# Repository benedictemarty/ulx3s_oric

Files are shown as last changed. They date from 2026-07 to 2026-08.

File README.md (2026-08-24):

# ulx3s_oric — Oric Atmos sur FPGA ULX3S

Portage matériel (core FPGA) de l'**Oric Atmos** pour la carte **ULX3S** (Lattice ECP5-85F),
entièrement en Verilog et synthétisable avec la chaîne open-source (yosys / nextpnr-ecp5).

La référence fonctionnelle est l'émulateur logiciel `~/Oric1` (timing ULA, VIA, clavier, AY
vérifiés contre son code source).

## Fonctionnalités (v1)

- CPU **6502** à 1 MHz (core Arlet Ottens)
- **ULA** vidéo réimplémentée : timing PAL 50 Hz (64 µs/ligne, 312 lignes), modes
  TEXT 40×28 et HIRES 240×200, attributs série (ink/paper/charset alternatif/double
  hauteur/clignotement/inversion), palette 8 couleurs
- ROM **BASIC 1.1b** (Atmos), 48 Ko de RAM
- **VIA 6522** complète ($0300) : ports A/B, timers T1/T2, IFR/IER, PCR/ACR
- **AY-3-8912** (core jt49) piloté par CA2/CB2 (BC1/BDIR), audio sur la prise jack
  (DAC 4 bits ULX3S)
- **Clavier USB** sur le port US2 (core usb_hid_host), traduit vers la matrice 8×8 Oric
- Sortie vidéo **HDMI/DVI** (GPDI) 640×480@60, framebuffer 240×224 doublé ×2

## Arborescence

```
rtl/           RTL spécifique au projet (ULA, VIA, clavier, top…)
third_party/   Cores libres vendorés (verilog-6502, jt49, usb_hid_host)
roms/          ROM BASIC 1.1b (+ conversion .hex pour $readmemh)
sim/           Testbenches iverilog
tests/         Scripts de test automatisés
constraints/   Fichier LPF ULX3S v2.0 (85F)
docs/          Documentation projet (architecture, backlog agile)
build/         Produits de synthèse (non versionnés)
```

## ROMs requises (non fournies)

Les ROMs propriétaires ne sont **pas distribuées** dans ce dépôt (copyright). À
placer soi-même dans `roms/` avant de construire :

| Fichier | Contenu | Format |
|---|---|---|
| `roms/basic11b.rom` | BASIC 1.1b (Atmos), 16 Ko | binaire |
| `roms/basic11b.hex` | idem, converti pour `$readmemh` | un octet hexa/ligne |
| `roms/basic10.hex`  | BASIC 1.0 (banque alternative) | idem |
| `roms/microdis.hex` | firmware Microdisc (support `.dsk`) | idem |

Conversion binaire → `.hex` (exemple) :
```sh
xxd -c1 -p roms/basic11b.rom > roms/basic11b.hex
```
`roms/font8x8.hex` (police OSD, maison) est fournie.

## Construire

```sh
make            # synthèse complète -> build/oric_ulx3s.bit
make test       # lance tous les testbenches (iverilog)
make prog       # flash SRAM via openFPGALoader (ou: make prog-fujprog)
```

## Matériel requis

- ULX3S avec ECP5-**85F**
- Écran HDMI (640×480@60 minimum)
- Clavier USB (le port **US2**, connecteur micro-USB du dessus)
- Casque/enceintes sur la prise jack 3,5 mm (son AY)

## Licences

- `third_party/verilog-6502` : licence libre (voir README amont, Arlet Ottens)
- `third_party/jt49` : GPL-3.0 (Jose Tejada)
- `third_party/usb_hid_host` : MIT (nand2mario)
- RTL du projet : GPL-3.0 (contaminé par jt49)
- Les ROMs BASIC (Oric/Tangerine) et le firmware Microdisc restent la propriété
  de leurs ayants droit ; **non distribués ici** — à fournir localement (cf.
  « ROMs requises »).

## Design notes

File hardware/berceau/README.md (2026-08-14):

# Berceau « LOCI-Bridge » — état du projet

Carte berceau : l'ULX3S s'enfiche (JB1/JB2 aux positions exactes relevées sur
`emard/ulx3s ulx3s.kicad_pcb` — nets affectés PAR POSITION, le piège
pairs/impairs est éliminé par construction), la LOCI arrive par nappe IDC 34
(J_LOCI, numérotation Atmos = table JEXP). Schéma électrique =
`../loci_lvc/SPEC_NETLIST.md` (5× SN74LVCC3245A TSSOP-24 + BSS138, brochage
vérifié TI SCAS585R).

## État (2026-08-14)

- `gen_pcb.py` : génération complète reproductible (150×58, plans F.Cu=GND,
  B.Cu=+3V3|+5V split x=116, vias d'alim posés par `post_power.py`).
- `route.py` : freerouting — **tous les signaux routés** (~40 nets).
- `post_power.py` : raccords alim/masse post-routage (vias collision-vérifiés,
  raccords en L, idempotent).

**RESTE À FAIRE avant fabrication** (~30 min de KiCad interactif) :
1. ~15 liaisons d'alimentation : mes contrôles géométriques ignorent les
   îlots de plan isolés — certains vias +3V3/+5V tombent dans des poches de
   zone déconnectées. Ouvrir `berceau.kicad_pcb`, afficher le chevelu,
   tirer les liaisons d'alim restantes à la souris (large, 0,4 mm), DRC.
2. 3 courts-circuits résiduels + sérigraphie (silk_over_copper etc.) à
   corriger au même moment.
3. REVUE MÉCANIQUE avant commande : sens d'enfichage ULX3S (embases mâles
   verticales sous la carte vs femelles coudées d'origine), hauteur des
   composants sous l'ULX3S, position du détrompeur IDC.

Pipeline : `python3 gen_pcb.py && python3 route.py && python3 post_power.py`
puis `kicad-cli pcb drc berceau.kicad_pcb`.

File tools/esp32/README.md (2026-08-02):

# Outillage ESP32 (ULX3S) — compiler & flasher l'ESP32 embarqué

Chaîne complète pour compiler `firmware/esp32_modem` et le flasher sur
l'**ESP32 embarqué** de l'ULX3S, sans matériel externe.

## Méthode (officielle emard)

L'ESP32 se flashe *à travers* le FPGA : on charge un **bitstream passthru**
qui relie le FTDI (US1) à l'UART0 de l'ESP32 et gère EN/GPIO0 pour le
bootloader, puis on téléverse avec esptool (via arduino-cli). On recharge
ensuite le bitstream Oric.

## Installation (une fois)

```sh
make esp32-setup
```
Installe, en local (`tools/esp32/bin`, ignoré par git) :
- **arduino-cli** (installeur officiel Arduino) ;
- le **core Arduino esp32** d'Espressif (inclut esptool) — gros téléchargement ;
- le **passthru 85F officiel** (`emard/ulx3s-bin`) dans `tools/esp32/passthru/`.

> ⚠️ `make esp32-setup` télécharge et exécute l'installeur arduino-cli
> (`curl | sh`) et récupère plusieurs centaines de Mo (toolchain xtensa). À
> lancer toi-même en connaissance de cause. En environnement restreint,
> exécute-le directement : `! make esp32-setup`.

## Compiler / flasher

```sh
make esp32-build              # compile le firmware
make esp32-flash              # passthru -> flash ESP32 -> recharge l'Oric
make esp32-flash PORT=/dev/ttyUSB1   # port différent
```

`esp32-flash` :
1. charge `ulx3s_85f_passthru.bit` en SRAM (`openFPGALoader -b ulx3s`) ;
2. `arduino-cli upload` sur le port série (esptool entre en bootloader) ;
3. recharge `build/oric_ulx3s.bit`.

## Après le flash — config WiFi

Depuis un terminal côté Oric (écriture sur le 6551 `$031C`), en mode commande :
```
AT$SSID=MonReseau
AT$PASS=monMotDePasse
AT$C          -> WIFI OK
ATDT bbs.exemple.com:23
```

## Dépannage

- **PCB v3.1.x** : si le flash échoue avec le passthru, relie **TMS et GND**
  au connecteur JTAG et réessaie (cf. doc ULX3S).
- L'ESP32 ne doit pas piloter **wifi_gpio5** (LED bleue / TMS) en sortie les
  premières secondes — notre sketch n'y touche pas.
- Mappage UART ESP32↔FPGA à confirmer (cf. `firmware/esp32_modem/README.md`).

## Sources
- Passthru & méthode : `emard/ulx3s-passthru`, `emard/ulx3s-bin`
  (`fpga/passthru/passthru-v20-85f/`).
- Core Arduino : `espressif/arduino-esp32`.

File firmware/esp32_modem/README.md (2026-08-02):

# esp32_modem — modem WiFi Hayes pour l'Oric (US-MODEM phase 2)

Firmware pour l'**ESP32 embarqué de l'ULX3S**. Il ponte l'UART venant du
**6551 ACIA** émulé dans le FPGA (`$031C-$031F`, phase 1) vers une connexion
**TCP/telnet en WiFi**, en interprétant les commandes **Hayes AT**. L'Oric
« croit » parler à un modem RS-232.

> **Statut : scaffold.** À compiler et flasher par bmarty. Non compilé ni
> testé dans ce dépôt (pas de toolchain ESP32 ici). Les points marqués ⚠️
> demandent une vérification matérielle.

## Câblage FPGA ↔ ESP32

Côté FPGA (déjà en place, cf. `rtl/top_ulx3s.v` + LPF) :

| FPGA | Sens | ESP32 |
|---|---|---|
| `wifi_rxd` (K3) | FPGA → ESP32 | RX (le 6551 émet) |
| `wifi_txd` (K4) | ESP32 → FPGA | TX (le 6551 reçoit) |
| `wifi_en` | FPGA → ESP32 | EN (maintenu haut) |

⚠️ **À vérifier sur le schéma ULX3S** : le mappage GPIO exact de cet UART côté
ESP32. Le firmware utilise par défaut `Serial` (**UART0**, GPIO1/3), qui est la
liaison standard ESP32↔FPGA de l'ULX3S. Si UART0 entre en conflit avec la
console/programmation, basculer sur un UART secondaire dans le sketch :
```cpp
HardwareSerial Link(2);
// dans setup(): Link.begin(LINK_BAUD, SERIAL_8N1, RX_PIN, TX_PIN);
```
Le débit **doit rester 115200** (identique aux `uart_tx`/`uart_rx` du FPGA).

## Compilation

Arduino IDE (paquet **esp32** d'Espressif) ou `arduino-cli` :
```sh
arduino-cli compile --fqbn esp32:esp32:esp32 firmware/esp32_modem
```
Carte : « ESP32 Dev Module » (l'ESP32 de l'ULX3S est un module WROOM).
Dépendances : `WiFi`, `Preferences` (fournies par le core esp32).

## Flash de l'ESP32 sur l'ULX3S ⚠️

Sur l'ULX3S, l'ESP32 se flashe **via le FPGA** qui fait passerelle FTDI↔ESP32
et pilote EN/GPIO0 pour le bootloader. Procédure de principe (à confirmer avec
la doc ULX3S / le dépôt `ulx3s-examples`) :
1. Charger un **bitstream « passthru »** ULX3S (relie l'FTDI à l'UART0 de
   l'ESP32 et gère EN/IO0), p.ex. depuis les exemples ULX3S.
2. Flasher avec `esptool.py --chip esp32 --port /dev/ttyUSB0 write_flash ...`
   (ou `arduino-cli upload`), l'esptool gère l'entrée en bootloader.
3. Recharger notre bitstream Oric (`make prog`) pour rétablir le modem.

> Tant que ce point n'est pas rôdé, tester le firmware sur un **ESP32 de
> dev externe** relié à K3/K4/GND est le plus simple.

## Configuration WiFi (une fois)

Depuis un terminal côté Oric (ou tout ce qui écrit sur le 6551), en mode
commande :
```
AT$SSID=MonReseau
AT$PASS=monMotDePasse
AT$C            (connexion WiFi ; réponse WIFI OK / WIFI FAIL)
AT$W            (affiche SSID + IP)
```
SSID/mot de passe sont **persistés en NVS** (Preferences).

## Commandes AT gérées

| Commande | Effet |
|---|---|
| `AT` | OK |
| `ATDT host[:port]` / `ATD ...` | connexion TCP (port 23 telnet par défaut) → `CONNECT` |
| `+++` | échappement vers le mode commande (connexion maintenue) |
| `ATO` | retour en ligne |
| `ATH` | raccroche → `NO CARRIER` |
| `ATE0/ATE1` | écho off/on |
| `ATV0/ATV1` | réponses numériques / texte |
| `ATI` | bannière d'identification |
| `ATZ` | reset léger (raccroche) |
| `AT$SSID= / AT$PASS= / AT$C / AT$W` | config/état WiFi (custom) |

Réponses : `OK`, `ERROR`, `CONNECT`, `NO CARRIER`.

## Points ouverts (à traiter en phase 2/3)

- ⚠️ **UART ESP32↔FPGA** : confirmer le GPIO/UART exact (voir plus haut).
- ⚠️ **Procédure de flash ULX3S** de l'ESP32 (passthru + esptool).
- **DCD matériel** : la porteuse est signalée **en bande** (`CONNECT` / `NO
  CARRIER`). Pour un vrai bit **DCD** (`$031D` bit5), router un `wifi_gpio`
  (p.ex. `wifi_gpio5`) depuis l'ESP32 vers l'entrée `acia_dcd` du FPGA (câblée
  à 0 aujourd'hui) — petite retouche RTL à faire quand le firmware pilote la
  porteuse.
- **Contrôle de flux** : pas de RTS/CTS câblé ; le 6551 régule via
  `TDRE`/`RDRF`. Aux débits BBS (≤ 9600 « virtuels ») c'est large ; surveiller
  aux gros transferts.
- **Telnet** : négociations IAC refusées en minimal (`telnetStrip`) ; suffit
  pour la plupart des BBS. PETSCII/ANSI = côté terminal Oric (phase 3).
- **Partage du lien** avec US-NETFS : à terme ce même UART portera aussi le
  contrôle du navigateur de fichiers → prévoir un protocole à canaux
  (cf. `docs/NETFS_WIFI.md`).

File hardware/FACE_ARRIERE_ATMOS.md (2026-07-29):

# Carte « Atmos moderne » — carte mère format Oric Atmos

**CARTE UNIQUE** (décision 2026-07-29) : une seule platine porte tout le
micro — berceau **Tang Nano 20K** (le cœur, portage Gowin prérequis),
**2 berceaux Pico W**, adaptation 5 V, connecteurs d'époque, USB, HP.
L'ULX3S reste hors carte (banc de développement ECP5 uniquement).

```
                    face arrière (connecteurs d'époque)
┌──────────────────────────────────────────────────────────────────────┐
│  [HDMI]   [DIN-7]     [===== 2x10 =====]    [██ peigne 34 ██]   [5V] │
│  vidéo    cassette     port imprimante        extension (LOCI)  jack │
│                                                                      │
│U │   ┌─────────────┐  ┌─────────────┐  ┌──────────────────────┐     │
│S │   │ berceau      │  │ berceau     │  │ berceau              │     │
│B │   │ Pico W  #1   │  │ Pico W #2   │  │ TANG NANO 20K        │     │
│1 │   │ (LOCI fw,    │  │ (modem WiFi,│  │ (le cœur : core Oric │     │
│  │   │  SD ext,USB1)│  │ clavier,USB2│  │  Gowin, HDMI, SDRAM) │     │
│U │   └─────────────┘  └──────┬──────┘  └───────────┬──────────┘     │
│S │                          pont UART multiplexé ───┘                │
│B │      6x TXS0108E, LM393, PhotoMOS, PAM8302+HP, nappe clavier      │
│2 │                                                                   │
└──────────────────────────────────────────────────────────────────────┘
   côté : USB1, USB2 (USB-A femelles)
```

## Connecteurs (de gauche à droite, comme l'Atmos)

| Emplacement Atmos | Ici | Référence |
|---|---|---|
| Prise TV (RF) | — supprimée | |
| DIN RGB | **HDMI femelle** coudée, déport mécanique du GPDI ULX3S par câble HDMI court mâle-mâle (aucune électronique) | prise HDMI-A traversante |
| DIN-7 cassette | **DIN-7 femelle** identique à l'origine (brochage Atmos : TAPE OUT, GND, TAPE IN, SOUND, RELAYS) | DIN 7 broches 270° |
| Port imprimante 20 pts | **Header mâle 2×10** au pas 2,54 comme l'origine (câbles imprimante d'époque compatibles) | |
| Port d'extension 34 pts | **Peigne doré 2×17** au bord de la carte — la LOCI s'y clipse comme sur un vrai Atmos | doigts or, PCB 1,6 mm |
| Jack alim 9 V | **Jack 5,5/2,1 mm, 5 V** : alimente le côté 5 V (cartouche, imprimante, cassette, TXS) | |

## Électronique embarquée (assemblage JLCPCB, zéro soudure)

- 5× **TXS0108E** (TSSOP-20) : 16 adresses + 8 données + 8 contrôles
  extension + 8 données imprimante + strobe/ack/cassette.
- 1× **LM393** + réseau RC : mise en forme du signal TAPE IN
  (magnétophone → niveau logique).
- Condensateurs de découplage, résistances de pull-up 5 V (bus au repos).
- liaisons internes en pistes (plus aucun câblage Dupont : carte unique).

## Affectation GPIO complémentaire (imprimante + cassette)

| GPIO | Signal | Sens FPGA |
|---|---|---|
| gp[23..27], gn[23..25] | Données imprimante PA0..PA7 | sortie |
| gn[26] | /STROBE imprimante (PB4) | sortie |
| gn[27] | /ACK imprimante (CA1) | entrée (pull-up) |
| gp[14] | TAPE OUT (PB7) | sortie |
| gp[15] | MOTEUR cassette (PB6, vers relais/transistor) | sortie |
| gp[16] | TAPE IN (vers CB1, après LM393) | entrée |

## Berceaux (côté 3,3 V — le même bus que le lien ULX3S)

Principe : **un Pico = un firmware** ; les berceaux sont de simples
supports femelles, à peupler selon l'usage. Avec la LOCI réelle branchée
sur le peigne, le berceau #1 (LOCI intégrée) reste VIDE — un seul Pico W
(#2, modem WiFi + scan clavier) suffit. Le #1 se peuple pour une config
autonome sans cartouche.

- **2× berceau Pico W** (2 rangées de supports femelles 1×20, pas 2,54) :
  - Pico #1 : candidat naturel pour porter le **firmware LOCI natif**
    (github.com/sodiumlb/loci-firmware, RP2040) ou tout périphérique de bus
    maison — il voit le bus 6502 en 3,3 V, comme le RP2040 de la vraie LOCI ;
  - Pico #2 : **modem WiFi** (PicoWiFiModemUSB, ACIA à $0380 — déjà supporté
    par l'émulateur de référence) ;
  - straps de sélection pour choisir quelles lignes de bus chaque Pico voit
    (éviter les conflits de pilotage — deux périphériques ne répondent
    jamais à la même adresse).
- **1× berceau Tang Nano 20K** (choix acté 2026-07-29, remplace le couple
  Primer 20K + dock) : format DIP à picots 2,54 → deux rangées de supports
  femelles. GW2AR-18 avec 8 Mo de SDRAM intégrée, HDMI et lecteur SD à
  bord ; FPGA d'expérimentation sur le bus (co-processeur, cartouche
  synthétique…). Même règle : il voit le bus 3,3 V.

⚠️ Règle de cohabitation : le Tang Nano pilote toujours A/RW/Φ2 ; les berceaux
sont des **périphériques** (ils ne pilotent D que sur lecture de leur
plage, /IRQ//ROMDIS//MAP en drain ouvert).

## Stockage et mémoire

- **Slot micro-SD ACCESSIBLE DE L'EXTÉRIEUR** (exigence 2026-07-29) :
  monté au bord arrière de la carte, poussoir push-push, câblé en SPI sur
  le berceau Pico #1 — c'est le stockage LOCI (.tap/.dsk), celui qu'on
  change au quotidien. Accès par l'ancienne découpe TV (RF) du boîtier
  Atmos, inutilisée (prévoir un insert imprimé 3D pour guider la carte
  dans l'ouverture ronde).
- Le micro-SD embarqué du Tang Nano 20K (core, rarement manipulé) reste
  interne ; en cas de besoin, une rallonge micro-SD souple peut le
  déporter.
- **RAM : aucun boîtier sur la carte porteuse.** La RAM de l'Oric (64 Ko)
  est en BRAM dans le FPGA ; le Tang Nano 20K apporte 8 Mo de SDRAM
  intégrés — le bus 6502 n'adresse que 64 Ko.

## USB latéraux

Chaque USB-A latéral est un port **hôte PIO-USB appartenant à un Pico**
(D+/D- sur 2 GPIO + 5 V du jack ; le Tang Nano n'a aucun rôle USB) :
- **USB1 → Pico #1** (firmware LOCI) : clé USB de stockage et
  clavier/souris HID, comme le port USB de la vraie cartouche (hub
  supporté par le firmware) ;
- **USB2 → Pico #2** (modem WiFi + scan matrice) : clavier USB de secours
  quand le berceau #1 est vide (vraie LOCI sur le peigne).
La LOCI réelle branchée sur le peigne conserve son propre port USB.
Les micro-USB natifs des Picos restent accessibles sur les berceaux pour
flasher leurs firmwares (opération d'atelier, ne sort pas du boîtier).

## Portage Gowin (nouveau chantier RTL)

Le core développé sur ULX3S (ECP5) devra être porté sur le GW2AR-18 du
Tang Nano 20K : chaîne yosys `synth_gowin` + nextpnr-himbaechel/apicula
(le Tang Nano 20K est bien supporté par la chaîne libre), ou Gowin EDA.
À adapter : PLL (rPLL Gowin), sérialiseur TMDS (primitives ODDR Gowin),
BRAM (inférence identique), USB clavier (déplacé vers les Pico).
CPU/ULA/VIA/AY : portables tels quels. → épic au backlog.

## Alimentation

- Le jack 5 V alimente exclusivement le domaine 5 V de la carte
  (VCCB des TXS, cartouche broche 33, imprimante, LM393).
- Le jack 5 V alimente aussi le Tang Nano et les Picos (via leurs entrées 5 V). **Masse unique de la carte.**
- Prévoir 5 V / 1 A (la LOCI consomme < 300 mA).

## Format : carte mère Atmos complète

**Boîtier cible acté (2026-07-29) : OriClone-1** — boîtier imprimable 3D
(Thingiverse 6228328, CC-BY-SA, ~284×205×~100 mm assemblé) conçu pour la
carte du projet OriClone-1 de JennyDigital (github.com/JennyDigital/OriClone-1,
cloné en `hardware/oriclone-1-ref/`). Notre carte reprend donc le gabarit
**OriClone-1 : 206,5 × 138,0 mm**, trous de fixation à (3,8;3,8),
(3,8;133), (96,8;133), (202,5;3,8), (202,5;133) mm (+ 2 petits trous à
l'origine), extraits du fichier Eagle `OriClone-1.brd`. Le clavier peut
être la platine **« Oric Tactile KB » du même dépôt** (switches MX,
gerbers prêts à commander, compatible avec ce boîtier et sa touche SHIFT
imprimée). Positions des connecteurs arrière à reprendre du .brd au
moment du routage :
- connecteurs arrière positionnés exactement comme l'origine (découpes du
  boîtier) : le peigne d'extension au bord arrière droit, DIN cassette,
  port imprimante, HDMI à l'emplacement du DIN RGB, jack alim ;
- trous de fixation aux emplacements des plots du boîtier Atmos ;
- **le Tang Nano 20K en berceau est le cœur** : son HDMI est déporté sur le
  connecteur arrière (câble/adaptateur court), son micro-SD sert au core,
  sa SDRAM 8 Mo est intégrée ; le bus 6502 5 V sort de ses GPIO via les
  TXS0108E ;
- **haut-parleur** : emplacement pour HP Ø 40-50 mm (comme l'origine) +
  ampli classe D PAM8302 attaqué en PWM/sigma-delta depuis un GPIO du
  Tang Nano ;
- **budget GPIO Tang Nano 20K** (~40 broches utiles) : bus extension
  (32) + cassette (3) + OE + audio + pont UART Pico #2 (2) ≈ 40 ;
- **architecture satellites (actée 2026-07-29)** : seuls le FPGA et la
  LOCI (réelle ou Pico #1 avec le firmware LOCI, ~26 GPIO consommés par
  le bus) touchent le bus parallèle. Le Pico #2 est un satellite HORS
  bus relié au FPGA par un **pont UART multiplexé** (2 GPIO) qui
  transporte : les octets imprimante (logique VIA dans le FPGA, lignes
  Centronics physiques et handshake ACK sur le Pico — mode « imprimante
  virtuelle » vers SD/WiFi possible), le modem WiFi (ACIA 6551 en RTL
  dans le FPGA, modèle dispo dans la référence Phosphoric), et les
  événements du clavier matrice scanné par le Pico ;
- **pont UART : aucun composant à ajouter** (pistes 3,3 V courtes sur
  PCB ; la liaison PC du Nano 20K passe par son BL616 embarqué, comme le
  FTDI de l'ULX3S). Protocole du pont avec trames typées + CRC8 +
  acquittement (3 flux multiplexés : imprimante, modem ACIA, clavier) —
  la robustesse est logicielle, pas matérielle ;
- **clavier d'origine réutilisable tel quel** : la platine Atmos est une
  matrice 8×8 passive (aucune électronique). Header nappe au même
  emplacement que la carte d'origine (brochage : schéma du manuel de
  service, à transcrire au routage). Scan par le **Pico #2** (16 GPIO,
  injection vers le core par le canal clavier série existant) — le FPGA
  reste déchargé. Pas de diodes dans la matrice d'origine : ghosting
  authentique conservé.

⚠️ Mesures à faire sur boîtier/carte réels avant le routage final :
dimensions exactes, positions des découpes arrière, entraxes de fixation,
position du connecteur nappe clavier.

## Stratégie : CARTE UNIQUE (décision bmarty 2026-07-29)

**Une seule platine porte tout** : berceau Tang Nano 20K, 2 berceaux
Pico W, les 6 TXS, le peigne LOCI, cassette, imprimante, HDMI déporté,
micro-SD externe, HP, clavier. Pas de bandeau intermédiaire commandé.

Le dossier « phase A » (hardware/phaseA/) N'EST PAS perdu : c'est le
prototype virtuel dont la carte unique hérite les blocs VALIDÉS PAR DRC :
banc de 6 TXS et affectations, géométrie exacte du peigne (pas confirmé
sur la LOCI réelle), chaîne analogique cassette (LM393+hystérésis,
PhotoMOS), port imprimante, pinouts fan-out monotone, et toutes les
leçons de routage (paires de doigts, échappements TSSOP, routage
conjoint). Maîtrise du risque sans deuxième commande : DRC 0 erreur
exigé + revue visuelle des rendus + lot de 5 (une itération de réserve).

Le boîtier paramétrique OpenSCAD (backlog S5) est généré depuis les
coordonnées des connecteurs de CETTE carte : gabarit libre (plus
contraint par l'OriClone), silhouette Atmos par le profil extrait.

## Notes de conception vérifiées

- **TXS0108E TSSOP-20 (PW), brochage vérifié sur datasheet TI SCES642H** :
  1=A1, 2=VCCA(3,3 V), 3..9=A2..A8, 10=OE, 11=GND, 12..18=B8..B2,
  **19=VCCB(5 V), 20=B1**. OE : pull-down 10 kΩ vers GND (Hi-Z au
  démarrage, exigence datasheet) + strap vers 3,3 V pour activer.
- Moteur cassette : contact sec attendu par le magnétophone → relais
  statique PhotoMOS (AQY212 ou TLP222A) piloté par MOTOR_3V3, pas un
  transistor à la masse.
- TAPE IN : comparateur LM393 (seuil ~200 mV) avec pull-up 3,3 V en sortie.
- TAPE OUT : diviseur résistif vers niveau ligne (~10 k/1 k).

## Fabrication

- PCB 2 couches ~150×40 mm, doigts or biseautés (option « gold fingers +
  bevel » chez JLCPCB), épaisseur 1,6 mm.
- Assemblage face top (économique) : TXS0108E, LM393, passifs.
- Connecteurs traversants (HDMI, DIN-7, headers, jack) en assemblage
  standard JLCPCB.
- Fichiers à produire : KiCad (schéma + PCB), gerbers, BOM.csv, CPL.csv.

## État

- [x] Spécification (ce document)
- [x] RTL : signaux imprimante + cassette exposés (cf. CHANGELOG)
- [ ] Schéma KiCad (en attente installation KiCad : `sudo apt install kicad`)
- [ ] PCB + DRC + gerbers + BOM/CPL JLCPCB
- [ ] Vérification du pas exact du connecteur LOCI avant envoi en fab
      (mesure sur la cartouche réelle : pas attendu 2,54 mm, à confirmer !)

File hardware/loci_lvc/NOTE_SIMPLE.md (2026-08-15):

# Version SIMPLIFIÉE — `loci_lvc_simple` (façon vraie LOCI)

**Date :** 2026-08-15 · **Auteur :** bmarty

## L'idée
La carte à **5 transceivers** (`loci_lvc` / `SPEC_NETLIST.md`) est dense et dure à
router. Or la **vraie LOCI n'a qu'UN transceiver octal** (74LVC4245A) + de petits
buffers, parce que sa logique est dans le RP2040.

On applique le même principe : **les entrées des périphériques Oric sont
5 V-tolérantes** (seuil TTL ≈ 2 V), donc les **sorties du FPGA** (A0–A15, Φ2, R/W,
/IO) pilotent le peigne **en direct en 3,3 V — sans aucun transceiver**. Il ne
reste à adapter que :
- le **bus de données** (bidirectionnel) → **1× 74LVC4245A** (`U1`) ;
- les **entrées de contrôle** (/IRQ, /ROMDIS, /MAP, /IOCTL, venant du périphérique
  en 5 V) → **1× 74LVC245** (`U2`, alim 3,3 V, 5 V-tolérant) ;
- **/RESET** (drain ouvert) → **1× BSS138** (`Q1`).

## Résultat
- **15 composants** au lieu de 25.
- **Route en 2 couches** : freerouting ferme **tous les signaux, 0 violation**
  (là où la version 5-transceivers plafonnait à 12–17 signaux !).
- Reste **9 masses à coudre** + 3 vias GND de freerouting à écarter — **finition
  triviale**.

## Reproduire
```sh
python3 gen_pcb_simple.py loci_lvc_simple.kicad_pcb   # placement + zones
python3 route_simple.py                               # freerouting 2 couches
# -> tous signaux routes, 0 violation, 9 masses restantes
```

## Finir (couture des 9 masses)
Le plus simple : **passer en 4 couches** (plan GND interne) → la couture devient un
via par pad GND (cf. `convert_6layer.py` adapté, ou dans KiCad). Ou, en 2 couches,
poser à la main un **via GND** près de chaque pad GND non connecté (9 vias, ~5 min
dans KiCad). Puis DRC → 0/0 → Gerbers → JLCPCB.

## BOM (simplifiée)
| Réf | Composant | Boîtier |
|---|---|---|
| U1 | SN74LVCC3245APW (data) | TSSOP-24 |
| U2 | SN74LVC245APW (entrées ctrl) | TSSOP-20 |
| Q1 | BSS138 (/RESET) | SOT-23 |
| R1–R4 | 10 kΩ | 0603 |
| C1–C5 | 100 nF / 10 µF | 0603 / 0805 |
| J_ULX | 2×20 (vers ULX3S) | THT |
| J_EXP | peigne 34 doigts | bord de carte |
| J_PWR | jack +5 V | THT |

> **Mapping GPIO ULX3S** : inchangé (`top_ulx3s.v` / `mapping-gpio-contraintes.md`).
> Les nets `A5V*`, `RW5`, `PHI2_5`, `IO5_n` disparaissent (adresses/Φ2/R-W//IO
> pilotées en direct) ; seuls `D5V*`, `*5_n`, `RST5_n` restent (via composants).

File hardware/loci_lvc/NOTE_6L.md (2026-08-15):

# Variante 6 couches — routage du bus complet (WIP)

**Date :** 2026-08-15 · **Auteur :** bmarty

## Pourquoi 6 couches
La carte 2 couches (routage `route.py` d'origine) **plafonne à ~12–17 signaux
non routés** : le faisceau côté 5 V (puces → peigne) est trop dense pour 2 (voire
4) couches. **Le passage en 6 couches (4 couches de signal + 2 plans GND internes)
débloque le routage** : freerouting ferme alors tout sauf ~11 liaisons.

## État de `loci_lvc_6l2.kicad_pcb`
- **6 couches** : F.Cu / **In1.Cu (plan GND)** / In2.Cu (signal) / In3.Cu (signal) /
  **In4.Cu (plan GND)** / B.Cu. Plans GND aussi sur F/B.
- **Routé à ~90 % par freerouting, PROPRE : 0 violation DRC.**
- **Reste 25 liaisons non connectées** :
  - **11 signaux** dont les pads côté puce sont **recouverts par le faisceau**
    (freerouting ne les ferme pas — limite de placement, pas de couches) ;
  - **14 masses** à coudre (vias pad → plans In1/In4).

## Reproduire le board propre
```sh
python3 gen_pcb.py loci_lvc_6l2.kicad_pcb      # board vierge (placement)
python3 convert_6layer.py loci_lvc_6l2.kicad_pcb  # 6 couches + plans GND In1/In4
python3 route_6l2.py                            # freerouting (mp 100) + import
# -> ~25 non connectees, 0 violation
```

## Finition (à faire dans KiCad, à la main)
Les 25 dernières liaisons se finissent **dans l'éditeur KiCad** :
- router les **11 signaux** sur In2/In3 (couches internes libres) ;
- **coudre les 14 masses** (poser un via GND près de chaque pad GND non connecté ;
  les plans In1/In4 sont continus → tout via GND legal connecte).

## ⚠️ Scripts de complétion automatique — NON fiables
`route_signals.py`, `fix_gnd2.py`, `finish_islands.py`, `route_pair.py`,
`fix_power.py`, `cleanup_vias.py`, `find_island2.py` : tentatives de complétion
**automatique** des 25 liaisons. **Elles connectent mais introduisent des
courts-circuits / violations DRC** (détection de collision insuffisante). À
utiliser seulement comme base ; **préférer la finition manuelle KiCad** pour un
board réellement fabricable.

## Règles / fabrication
- Réglé fabricable JLCPCB 6 couches (trace 0,15 / via 0,3-0,6 possible).
- Une fois les 25 liaisons finies et DRC propre : générer Gerbers + drill + BOM
  (BOM = `SPEC_NETLIST.md`) + placement, puis commander en PCBA.

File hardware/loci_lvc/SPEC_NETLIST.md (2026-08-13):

# Carte adaptateur LOCI (rév. LVC) — spécification électrique

Petite carte 2 couches (~110×50 mm) entre les nappes GPIO de l'ULX3S et le
connecteur carte-bord 34 points de la **LOCI**. Révision 2026-08-13 : les
TXS0108E du bandeau phaseA sont **proscrits** (auto-sens inadapté à un bus
parallèle push-pull, cf. `docs/PORT_EXTENSION.md`) → **5× SN74LVCC3245APW**
(dual-supply 3,3 V/5 V, DIR + /OE maîtrisés).

Hérite de phaseA : géométrie du peigne J_EXP (34 doigts, 2×17, pas 2,54 mm,
doigts 1,6×6 mm sans masque, F.Cu+B.Cu, biseau 45°, ENIG), numérotation
officielle Atmos (position k : avant = 2k, arrière = 2k−1).

## Différences avec phaseA

- Périmètre réduit : NI imprimante, NI cassette/DIN, NI LM393/PhotoMOS —
  uniquement le bus d'extension vers la LOCI.
- 5× 74LVCC3245A à direction figée ou pilotée, plus de TXS.
- /RESET par BSS138 (drain ouvert bidirectionnel), plus par transceiver.
- Deux nets de pilotage venant du FPGA : `XCVR_DIR` (gp[16]) et
  `/XCVR_OE` (gn[16]) — déjà câblés dans le bitstream (commit RTL
  2026-08-13).

## Affectation des transceivers

DIR haut = A→B (A = côté 3,3 V FPGA, B = côté 5 V LOCI).

| Chip | Canaux | DIR | /OE |
|---|---|---|---|
| U1 | A1..A8 = A0..A7 → A5V0..A5V7 | figé HAUT (A→B) | GND |
| U2 | A1..A8 = A8..A15 → A5V8..A5V15 | figé HAUT (A→B) | GND |
| U3 | A1..A8 = D0..D7 ↔ D5V0..D5V7 | **XCVR_DIR** (pull-down 10 k) | **/XCVR_OE** (pull-up 10 k → isolé par défaut) |
| U4 | A1..A3 = RW, PHI2, IO_n → RW5, PHI2_5, IO5_n (A4..A8 NC, entrées A à GND) | figé HAUT (A→B) | GND |
| U5 | B1..B4 = IRQ5_n, ROMDIS5_n, MAP5_n, IOCTL5_n → IRQ_n, ROMDIS_n, MAP_n, IOCTL_n (B5..B8 = entrées, liées à GND en direct) | figé BAS (B→A) | GND |

Sécurité par défaut (FPGA absent/non configuré) : U3 isolé (/OE tiré haut)
et en écoute (DIR tiré bas) ; les entrées de canaux inutilisés ne flottent
jamais (liées à la masse du côté émetteur).

## SN74LVCC3245A — brochage VÉRIFIÉ (TI SCAS585R, mai 2026)

⚠️ Boîtier PW = **TSSOP-24** (7,8×6,4 mm, pas 0,65 mm) — PAS 20 broches.
1=VCCA, 2=DIR, 3..10=A1..A8, 11/12/13=GND, 14..21=B8..B1 (ordre inversé),
22=/OE (actif bas), 23=NC, 24=VCCB.
- VCCA 2,3-3,6 V (côté FPGA), VCCB 3-5,5 V (côté LOCI).
- **DIR et /OE référencés à VCCA** → pilotage direct 3,3 V par le FPGA.
- DIR haut = A→B ; VCC isolation : si un des deux VCC < 100 mV, tout passe
  en haute impédance (sécurité au débranchement).
- Empreinte KiCad : `Package_SO:TSSOP-24_4.4x7.8mm_P0.65mm`.

## /RESET (bidirectionnel drain ouvert)

BSS138 : gate = +3V3 ; source = RST_n (côté FPGA) + R 10 k → 3V3 ;
drain = RST5_n (côté LOCI, doigt 4) + R 10 k → +5V. Schéma classique
« niveau I²C » : chaque côté peut tirer bas, aucun ne pousse du 5 V vers
le FPGA.

## J_ULX (2×20) — vers l'ULX3S (nappe/Dupont, 3,3 V)

Ordre fan-out monotone (hérité phaseA, + les 2 nets XCVR) :
1=RW, 2=PHI2, 3=IO_n, 4=RST_n, 5=IRQ_n, 6=ROMDIS_n, 7=MAP_n, 8=IOCTL_n,
9=XCVR_DIR, 10=XCVR_OE_n ; 11..18 = D0..D7 ; 19..26 = A0..A7 ;
27..34 = A8..A15 ; 35,36=GND ; 37,38=+3V3 (depuis l'ULX3S) ; 39,40=GND.

Correspondance côté ULX3S = table de `docs/PORT_EXTENSION.md`
(gp/gn J1-J2, dont XCVR_DIR=gp[16], /XCVR_OE=gn[16]).

## Alimentations

- +3V3 : depuis l'ULX3S (J_ULX 37,38) — alimente VCCA des 5 chips + pull-ups côté A.
- +5V : **jack 5,5/2,1 externe** (J_PWR) — alimente VCCB des 5 chips,
  pull-up RST5_n, et le doigt 33 (+5V LOCI). JAMAIS relié au 3V3/FPGA.
- Masse commune : J_ULX (35,36,39,40) + jack + doigt 34.
- Découplage : 100 nF ×2 par chip (un par VCC), 10 µF vrac sur +5V et +3V3.

## BOM (draft)

| Réf | Composant | Empreinte |
|---|---|---|
| U1..U5 | SN74LVCC3245APW | TSSOP-24_4.4x7.8mm_P0.65mm |
| Q1 | BSS138 | SOT-23 |
| J_EXP | Peigne 34 doigts (script phaseA) | custom |
| J_ULX | Header mâle 2×20 | PinHeader_2x20_P2.54mm_Vertical |
| J_PWR | Jack alim 5,5/2,1 | BarrelJack_Horizontal |
| R1,R2 | 10 k (pull-ups /RESET 3V3 et 5V) | R_0603 |
| R3 | 10 k (pull-up /XCVR_OE → 3V3) | R_0603 |
| R4 | 10 k (pull-down XCVR_DIR) | R_0603 |
| C1..C10 | 100 nF | C_0603 |
| C11,C12 | 10 µF | C_0805 |

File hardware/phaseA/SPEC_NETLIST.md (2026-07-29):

# Phase A — Bandeau LOCI : spécification électrique complète

Carte 2 couches ~160×50 mm. Peigne doré 34 contacts (2×17, pas 2,54 mm,
doigts des deux faces) au bord DROIT. Assemblage JLCPCB (SMD top).
Épaisseur 1,6 mm, finition ENIG + biseau 45° sur le peigne.

## Composants

| Réf | Composant | Empreinte KiCad |
|-----|---|---|
| J_EXP | Peigne 34 doigts (custom, voir géométrie) | générée par script |
| U1..U6 | TXS0108E (TSSOP-20) | Package_SO:TSSOP-20_4.4x6.5mm_P0.65mm |
| U7 | LM393 (SOIC-8) | Package_SO:SOIC-8_3.9x4.9mm_P1.27mm |
| K1 | PhotoMOS AQY212GH (DIP-4 CMS) | Package_DIP:DIP-4_W7.62mm (ou SOP-4) |
| J_ULX_A | Header mâle 2×20 | Connector_PinHeader_2.54mm:PinHeader_2x20_P2.54mm_Vertical |
| J_ULX_B | Header mâle 2×10 | Connector_PinHeader_2.54mm:PinHeader_2x10_P2.54mm_Vertical |
| J_PRN | Header mâle 2×10 (Centronics Atmos) | idem 2x10 |
| J_CAS | DIN-7 femelle 270° THT | Connector_DIN:DIN41524_7pin_... (ou pads THT custom) |
| J_PWR | Jack alim 5,5/2,1 | Connector_BarrelJack:BarrelJack_Horizontal |
| J_SND | Header 1×2 (audio vers DIN4) | PinHeader_1x02 |
| R_OE | 10 kΩ 0603 (pull-down OE) | R_0603 |
| R1 | 10 kΩ 0603 (div. TAPE OUT série) | R_0603 |
| R2 | 1 kΩ 0603 (div. TAPE OUT masse) | R_0603 |
| R3,R4 | 100 kΩ 0603 (polarisation IN+ LM393) | R_0603 |
| R5 | 100 kΩ 0603 (seuil auto IN-) | R_0603 |
| R6 | 10 kΩ 0603 (pull-up sortie LM393) | R_0603 |
| R7 | 470 Ω 0603 (LED PhotoMOS) | R_0603 |
| R8 | 1 MΩ 0603 (hystérésis LM393) | R_0603 |
| C1 | 1 µF 0603 (couplage TAPE IN) | C_0603 |
| C2 | 100 nF 0603 (moyenne IN-) | C_0603 |
| C3..C14 | 100 nF 0603 (découplage : 2/TXS) | C_0603 |
| C15,C16 | 10 µF 0805 (vrac 5V, 3V3) | C_0805 |

## TXS0108E — brochage VÉRIFIÉ (TI SCES642H)

1=A1, 2=VCCA(3V3), 3=A2, 4=A3, 5=A4, 6=A5, 7=A6, 8=A7, 9=A8, 10=OE,
11=GND, 12=B8, 13=B7, 14=B6, 15=B5, 16=B4, 17=B3, 18=B2, **19=VCCB(5V)**,
**20=B1**. Tous les OE sur le net OE_EN (R_OE 10 k vers GND ; piloté haut
par le FPGA via J_ULX_A.33 après verrouillage des PLL).

## J_EXP — peigne (numérotation officielle Atmos, annexe 11)

Face AVANT (F.Cu) = broches paires, face ARRIÈRE (B.Cu) = impaires,
même position le long du bord. Position k (1..17) : avant = 2k, arrière = 2k-1.

| Doigt | Net 5V | | Doigt | Net 5V |
|---|---|---|---|---|
| 1 | MAP5_n | 2 | ROMDIS5_n |
| 3 | PHI2_5 | 4 | RST5_n |
| 5 | IO5_n | 6 | IOCTL5_n |
| 7 | RW5 | 8 | IRQ5_n |
| 9 | D5V2 | 10 | D5V0 |
| 11 | A5V3 | 12 | D5V1 |
| 13 | A5V0 | 14 | D5V6 |
| 15 | A5V1 | 16 | D5V3 |
| 17 | A5V2 | 18 | D5V4 |
| 19 | D5V5 | 20 | A5V4 |
| 21 | A5V5 | 22 | D5V7 |
| 23 | A5V6 | 24 | A5V15 |
| 25 | A5V7 | 26 | A5V14 |
| 27 | A5V8 | 28 | A5V13 |
| 29 | A5V9 | 30 | A5V12 |
| 31 | A5V10 | 32 | A5V11 |
| 33 | +5V | 34 | GND |

Géométrie doigts : largeur 1,6 mm, longueur 6 mm depuis le bord, pas
2,54 mm, sans masque (mask ouvert), F.Cu ET B.Cu.
✔ Pas confirmé (2026-07-29, bmarty) : le connecteur LOCI est un
Amphenol 34 points carte-bord standard (type nappe disquette), pas
2,54 mm, carte 1,6 mm. Option de raccordement souple : nappe 34
conducteurs avec connecteurs carte-bord IDC de récupération (câble
disquette d'époque), si l'insertion directe est mécaniquement gênante.

## Affectation TXS

| Chip | Côté A (3V3) ← J_ULX_A | Côté B (5V) → destination |
|---|---|---|
| U1 A1..A8 | A0..A7 | A5V0..A5V7 → J_EXP |
| U2 A1..A8 | A8..A15 | A5V8..A5V15 → J_EXP |
| U3 A1..A8 | D0..D7 | D5V0..D5V7 → J_EXP |
| U4 A1..A8 | RW, PHI2, IO_n, RST_n, IRQ_n, ROMDIS_n, MAP_n, IOCTL_n | RW5, PHI2_5, IO5_n, RST5_n, IRQ5_n, ROMDIS5_n, MAP5_n, IOCTL5_n → J_EXP |
| U5 A1..A8 | PA0..PA7 | PRN_D0..PRN_D7 → J_PRN |
| U6 A1,A2 | STROBE_n, ACK | PRN_STB_n, PRN_ACK → J_PRN (A3..A8/B3..B8 : NC) |

## J_ULX_A (2×20) — vers le FPGA hôte (Dupont, 3,3 V)

**Hôte cible : Tang Nano 20K** (décision 2026-07-29) — l'ULX3S peut aussi
servir de banc de validation ECP5. Budget Nano 20K : J_ULX_A complet passe ;
J_ULX_B (imprimante/cassette) attendra le pont Pico (voir spec carte B).

**Ordre RÉVISÉ 2026-07-29 (fan-out monotone vers les TXS, routage sans
croisements)** :
1=RW, 2=PHI2, 3=IO_n, 4=RST_n, 5=IRQ_n, 6=ROMDIS_n, 7=MAP_n, 8=IOCTL_n,
9=OE_EN ; 10..17 = D0..D7 ; 18..25 = A0..A7 ; 26..33 = A8..A15 ;
34..36=GND ; 37,38=+3V3 (depuis ULX3S) ; 39,40=GND.
(Le câblage Dupont vers les gp/gn de l'ULX3S suit ce tableau, pas
l'ancien : chaque fil est indépendant, seule la table change.)

## J_ULX_B (2×10)

1..8 = PA0..PA7 ; 9=STROBE_n ; 10=ACK ; 11=TAPE_OUT_3V3 ; 12=MOTOR_3V3 ;
13=TAPE_IN_3V3 ; 14,15,16=GND ; 17,18=+3V3 ; 19,20=GND.

## J_PRN (2×10, brochage imprimante Atmos officiel)

Impairs : 1=PRN_STB_n, 3=PRN_D0, 5=PRN_D1, 7=PRN_D2, 9=PRN_D3, 11=PRN_D4,
13=PRN_D5, 15=PRN_D6, 17=PRN_D7, 19=PRN_ACK. Pairs 2..20 : GND.

## J_CAS (DIN-7, brochage Atmos)

1=TAPE_OUT_DIN (depuis diviseur R1/R2), 2=GND, 3=TAPE_IN_DIN (vers C1),
4=SOUND (depuis J_SND.1), 5=NC, 6=MOTOR_A, 7=MOTOR_B (contacts K1).

## Circuits analogiques

- TAPE OUT : TAPE_OUT_3V3 —R1(10k)— TAPE_OUT_DIN —R2(1k)— GND.
- TAPE IN : TAPE_IN_DIN —C1(1µF)— nœud IN+ ; R3(100k) IN+→3V3 ;
  R4(100k) IN+→GND ; R5(100k) IN+→IN- ; C2(100n) IN-→GND ;
  LM393 : IN+=broche 3, IN-=broche 2, OUT=broche 1 ; R6(10k) OUT→3V3 ;
  **R8(1M) OUT→IN+ : hystérésis ~30 mV** (immunité au bruit du câble
  magnétophone — ajouté 2026-07-29) ; OUT = net TAPE_IN_3V3.
  VCC LM393(8)=3V3, GND(4)=GND. 2e comparateur : entrées (5,6) à GND,
  sortie (7) NC.
- MOTEUR : MOTOR_3V3 —R7(470)— K1 LED+(1) ; K1 LED-(2)=GND ;
  K1 contacts (3,4) = MOTOR_A/MOTOR_B (contact sec).

## Alimentations

+5V : J_PWR centre → VCCB U1..U6 (19), J_EXP.33. GND : commun.
+3V3 : J_ULX_A.37/38 → VCCA U1..U6 (2), R3, R6, LM393.8.
Découplage 100 nF au plus près de chaque broche VCCA et VCCB.

## Placement (indicatif)

- Bord droit : J_EXP (doigts, centrés).
- Bord haut (« face arrière ») de gauche à droite : J_PWR, J_CAS, J_PRN.
- Bande centrale : U1..U6 alignés, côté B vers la droite/haut.
- Bord bas : J_ULX_A puis J_ULX_B (accès Dupont), U7/K1 près de J_CAS.

## Critères d'acceptation des fichiers de fabrication

1. `kicad-cli pcb drc` : 0 erreur (avertissements sérigraphie tolérés).
2. 0 net non routé (ratsnest vide).
3. Gerbers + perçage Excellon exportés (`kicad-cli pcb export gerbers/drill`).
4. BOM.csv (réf LCSC quand dispo : TXS0108EPWR=C17197?, à vérifier) et
   CPL.csv (positions top) au format JLCPCB.
5. README de commande : 2 couches, 1,6 mm, ENIG, gold fingers + bevel.

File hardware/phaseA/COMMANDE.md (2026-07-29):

# COMMANDE JLCPCB — Phase A « Bandeau LOCI »

Fichiers à téléverser : archive zip du dossier `gerbers/`
(gerbers toutes couches + Edge.Cuts + perçage Excellon).

## Options PCB (obligatoires)

| Option | Valeur |
|---|---|
| Base Material | FR-4 |
| Layers | **2** |
| Dimensions | 160 × 50 mm |
| PCB Thickness | **1,6 mm** |
| Surface Finish | **ENIG** (obligatoire pour le peigne) |
| Gold Fingers | **Yes** |
| Bevel/Chamfer (gold fingers) | **45°** |
| Outer Copper Weight | 1 oz |
| Solder Mask / Silkscreen | au choix (vert/blanc par défaut) |
| Remove Order Number | conseillé : « Specify a location » impossible ici → « Yes » (payant) ou accepter le marquage |

Remarques :
- Le peigne (34 doigts, 2×17, pas 2,54 mm, doigts 1,6 × 6 mm sur F.Cu et
  B.Cu, masque ouvert) est au bord DROIT du contour. L'option « Gold
  Fingers + 45° bevel » s'applique à ce bord.
- ⚠️ Avant de payer : confirmer le pas de 2,54 mm et le sens de
  numérotation par mesure sur la LOCI réelle (voir QUESTIONS.md §1/§10).

## Options assemblage (SMT top uniquement)

| Option | Valeur |
|---|---|
| PCBA Type | Economic (si dispo) |
| Assembly Side | **Top** |
| BOM | `BOM.csv` |
| CPL (Pick & Place) | `CPL.csv` |

Composants assemblés (32 CMS top) : U1..U6 (TXS0108EPWR, C17206),
U7 (LM393DR, C67470), R_OE,R1..R8 (0603), C1..C14 (0603), C15,C16 (0805).

NON assemblés (à souder soi-même, lignes LCSC=TBD dans la BOM) :
- K1 AQY212GH (DIP-4 traversant — cf. QUESTIONS.md §3 ; variante CMS
  possible : AQY212GHAX = C719739 avec empreinte SOP/SMDIP),
- J_ULX_A (2×20), J_ULX_B (2×10), J_PRN (2×10), J_SND (1×2) : headers
  mâles 2,54 mm THT,
- J_PWR : jack alim 5,5/2,1 THT (type CUI PJ-102A ou équivalent),
- J_CAS : DIN-7 femelle 270° THT (valider l'empreinte mécanique du
  connecteur acheté avant commande, QUESTIONS.md §4).

## Vérifications au moment de la commande

1. Aperçu JLC : orientation des TSSOP/SOIC dans le rendu de placement
   (rotations CPL = angles KiCad ; corriger dans l'outil JLC si besoin).
2. Statut/stock des codes LCSC (vérifiés 07/2026) : C17206, C67470,
   C25804, C21190, C25803, C23179, C14663, C15849, C15850.
3. DRC de production JLC (min track/space 0,127 mm) : la carte est en
   0,25/0,2 mm — large marge.

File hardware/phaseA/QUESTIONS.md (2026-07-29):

# QUESTIONS / points à vérifier avant commande (Phase A)

Incohérences ou ambiguïtés relevées dans SPEC_NETLIST.md, avec
l'interprétation retenue (la plus sûre). AUCUNE modification de netlist
n'a été faite : chaque net/broche/valeur vient de la spec.

## 1. J_EXP — sens de numérotation le long du bord
La spec définit « position k (1..17) : avant = 2k, arrière = 2k-1 » mais
ne dit pas si k=1 est en HAUT ou en BAS du bord droit.
**Retenu : k=1 en haut (y minimal), k=17 en bas.** Si la LOCI réelle est
numérotée dans l'autre sens, il faut miroiter le peigne (1 ligne à changer
dans gen_pcb.py : `y0` / signe du pas). ⚠️ Sens à CONFIRMER face au
connecteur Amphenol de la LOCI (le pas 2,54 mm et l'épaisseur 1,6 mm ont
été confirmés par bmarty le 2026-07-29 — note dans la spec révisée).

## 2. J_EXP — retrait de 0,05 mm par rapport au bord
Les doigts font 6,00 mm de long mais s'arrêtent à 0,05 mm du bord
théorique (demi-épaisseur du trait Edge.Cuts) pour satisfaire le DRC.
Sans effet pratique : le biseau 45° de JLCPCB entame de toute façon le
bord sur ~0,5 mm.

## 3. K1 — « AQY212GH (DIP-4 CMS) » : contradiction THT/CMS
AQY212GH est un boîtier DIP-4 traversant ; les variantes CMS sont
AQY212GHA (pattes coupées) / AQY212GHAX (gull-wing, LCSC C719739).
La spec demande « DIP-4 CMS » avec l'empreinte
`Package_DIP:DIP-4_W7.62mm (ou SOP-4)`.
**Retenu : DIP-4_W7.62mm traversant (1er choix explicite de la spec).**
Conséquence : K1 n'est PAS assemblable par JLC en « assemblage top SMD »
(à souder à la main, ou passer sur AQY212GHAX + empreinte SMD).

## 4. J_CAS — empreinte DIN-7 femelle 270° créée par script
Aucune empreinte DIN 41524 7 broches dans les bibliothèques KiCad.
Créée par script : 7 pastilles THT Ø2,4 mm / perçage 1,3 mm sur un arc de
270°, cercle de broches Ø7,0 mm (DIN 45329), 45° entre broches, ordre
physique 6-1-4-2-5-3-7
(broche 2 au centre de l'arc), ouverture vers le bord haut de la carte.
**À VALIDER mécaniquement contre le connecteur réellement acheté**
(position des pattes de fixation, sens avant/arrière du brochage vu côté
soudure, diamètre des broches). Aucun trou de fixation ajouté faute de
référence constructeur dans la spec.

## 5. J_SND — broche 2 non spécifiée
La spec ne définit que J_SND.1 = SOUND (vers DIN4). **Retenu :
J_SND.2 = GND** (retour audio), interprétation la plus sûre.

## 6. J_PWR — 3e contact du jack (coupure) non spécifié
L'empreinte BarrelJack_Horizontal a 3 pastilles (1=centre, 2=manchon,
3=contact de coupure). La spec ne mentionne que centre=+5V et GND.
**Retenu : pastille 3 laissée non connectée** (le manchon reste GND en
permanence). Vérifier la mécanique du jack acheté (5,5/2,1) vs empreinte
générique KiCad.

## 7. LM393 — comparateur 2 : « entrées (5,6) à GND »
Appliqué tel quel (5 et 6 à GND, 7 NC). Remarque (non corrigée, netlist
respectée) : avec IN+=IN-=0 V la sortie du comparateur inutilisé est
indéterminée ; sans conséquence car la broche 7 est NC. Aucun découplage
100 nF dédié au LM393 dans la spec (C3..C14 réservés aux TXS) ; C16
(10 µF, 3V3) est placé à proximité relative.

## 8. Références LCSC
Vérifiées en ligne (07/2026) :
- TXS0108EPWR (TSSOP-20) = **C17206** (le « C17197? » de la spec ne
  correspond pas : C17206 confirmé sur jlcpcb.com/lcsc.com).
- LM393DR (TI, SOIC-8) = **C67470**.
- AQY212GHAX (CMS) = C719739 ; AQY212GHA = C135778 ; le AQY212GH DIP
  exact n'a pas de code C confirmé → **TBD** dans la BOM.
- Passifs : voir BOM (C25804, C21190, C25803, C23179, C14663, C15849,
  C15850) — codes « basic parts » usuels, à re-vérifier au moment de la
  commande (stock/statut basic évolutif).
- Connecteurs THT (headers, jack, DIN) : non assemblés par JLC → TBD.

## 9. CPL / rotations JLCPCB
Les rotations du CPL sont les angles KiCad. JLCPCB ré-oriente parfois les
TSSOP/SOIC de ±90°/180° : vérifier l'aperçu de placement (rendu 3D) sur
le site JLC avant de valider la commande d'assemblage.

## 10. Révisions de spec intégrées en cours de génération (2026-07-29)
- **R8 1 MΩ (hystérésis LM393, OUT→IN+)** : intégré. R8 avait été ajouté
  directement dans phaseA.kicad_pcb à (55,5;13,2), en court-circuit sur
  U7 pad 8 (+3V3) : replacé en (59;21) par gen_pcb.py.
- **J_ULX_A ordre révisé** (1..8=contrôle, 9=OE_EN, 10..17=D0..D7,
  18..33=A0..A15) : intégré dans gen_pcb.py, carte re-routée.
- **Pas du peigne confirmé** (Amphenol 34 pts, 2,54 mm) : la question ne
  reste ouverte que pour le SENS de numérotation (§1).

## 11. Largeur des pistes d'alimentation : 0,4 mm (au lieu de 0,5)
Le guide de routage indiquait 0,5 mm pour +5V/+3V3. Une piste de 0,5 mm
ne peut pas entrer dans un pad TSSOP-20 au pas 0,65 mm en respectant
l'isolation de 0,2 mm (0,65-0,25-0,2 = 0,20 mm : limite exacte, refusée
par le routeur). Les pistes d'alim sont donc routées à **0,4 mm**
(chutes de tension négligeables : TXS0108E ≈ quelques mA par rail).
La netclass « Power » du board reste déclarée à 0,5 mm.

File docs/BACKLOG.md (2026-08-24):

# Backlog agile — ulx3s_oric

> **Validation carte en attente** : procédure de test matériel des
> fonctionnalités « sim OK » (US2.3 LEDs, US3.3 joystick, US-CSAVE.2/4) dans
> [VALIDATION_CARTE.md](VALIDATION_CARTE.md).

## Sprint 1 (TERMINÉ 2026-07-29) — « Il boote »
Objectif : Oric Atmos fonctionnel sur ULX3S 85F — BASIC 1.1b au boot,
affichage HDMI, clavier USB, son AY.

- [x] US1.1 Squelette projet + docs + git
- [x] US1.2 RTL cœur : ULA, VIA 6522, mémoire, intégration 6502/jt49
- [x] US1.3 HDMI 640×480 + top-level ULX3S + USB HID + audio
- [x] US1.4 Testbenches : VIA, ULA, boot ROM (message BASIC en RAM écran)
- [x] US1.5 Synthèse 85F propre en timing + bitstream + flash carte

### Validation matérielle
- [x] Affichage HDMI réel (2026-07-29 — boot BASIC visible ; synchro
      fiabilisée par l'alignement de phase TMDS)
- [x] Clavier série UART depuis le PC (2026-07-29 — frappes visibles à
      l'écran via picocom)
- [x] Flash permanent en SPI v1.1.0 (2026-07-29, --unprotect-flash)
- [x] HIRES validé sur carte (2026-07-29, correctif v1.1.1 confirmé par bmarty)
- [x] Frappe clavier USB réelle (2026-08-02 — clavier physique confirmé
      fonctionnel par bmarty sur ULX3S)
- [x] Bascule disposition QWERTY/AZERTY sur BTN6 (2026-08-02 — décodage
      ASCII FR + table partagée, LED4 = AZERTY, testbench tb_azerty)
- [x] Son AY sur la prise jack (2026-08-20) : déjà routé (DAC R-2R 4 bits),
      **amélioré** par un noise-shaper sigma-delta `rtl/audio_dac_sd.v`
      (suréchantillonné 25 MHz → résolution effective ~10 bits). `test-audio-dac`.
      Reste validation carte (écoute PING/ZAP/MUSIC au casque).

## Sprint 2 — « On charge des programmes »
- [x] US2.1 Chargement .tap (cassette) (2026-08-02) — injecteur cassette FPGA
      alimenté par UART avec contrôle de flux par crédits (voie retour
      ftdi_rxd) ; modulation fidèle à la référence, script tools/send_tap.py,
      testbench tb_tape. VALIDÉ SUR CARTE avec un vrai .tap (bmarty, 2026-08-02).
- [x] US2.2 Bouton reset physique (BTN1) + reset à chaud/froid (2026-08-16 :
      BTN1 reset ; BTN5 bascule ROM+reset ; SW1 bascule Microdisc+reset AUTO
      anti-rebondi ; insertion .dsk = reset auto. tb_sw1reset garde-fou.)
- [x] US2.3 LED d'activité (IRQ, VSYNC, USB) (2026-08-23, sim + synthèse OK,
      **carte à valider**) : `rtl/led_activity.v` monostable re-déclenchable
      (heartbeat IRQ/VSYNC, flash USB) ; overlay opt-in **SW4** (`sw[3]`) →
      `led[7:5]={IRQ,VSYNC,USB}`, vue diagnostic SD/FAT inchangée sinon.
      tb_led_activity (cible `test-led`).

## Épopée MODEM WiFi — 6551 ACIA + ESP32 Hayes (plan : docs/MODEM_WIFI.md)
Objectif : modem WiFi Oric (telnet/BBS) via 6551 émulé (FPGA) + firmware
Hayes/WiFi sur l'ESP32 embarqué. Décisions (bmarty, 2026-08-02) : Hayes+TCP
dans l'ESP32 ; 6551 mappé `$031C-$031F` (standard Oric, fidèle à
`~/Oric1/src/io/acia6551.c`) ; pont UART FPGA↔ESP32 sur `wifi_rxd`/`wifi_txd`.
- [x] US-MODEM.1 **Phase 1 — Cœur 6551 FPGA** (2026-08-02) : `rtl/acia6551.v`
      (registres data/status/command/control, TDRE/RDRF/OVRN, IRQ, DCD/DSR),
      décodage `sel_acia` ($031C-$031F) dans oric_atmos + IRQ
      `via_irq|ext_irq|acia_irq`, pont UART ESP32 (uart_tx/uart_rx 115200) sur
      wifi_rxd (K3) / wifi_txd (K4), `wifi_en`, testbench `tb_acia`. RTL fait,
      testé (tb_acia), synthèse OK. Reste : brancher DCD réel en phase 2.
- [~] US-MODEM.2 **Phase 2 — Firmware ESP32** : SCAFFOLD + outillage faits
      (2026-08-02, `firmware/esp32_modem/`, `tools/esp32/`). ⚠️ Flash esptool
      de l'ESP32 interne IMPOSSIBLE (v3.0.8, GPIO0 non tenable — épuisé le
      2026-08-02, ne pas retenter). **DÉBLOQUÉ le 2026-08-13 par une autre
      voie : le firmware d'usine MicroPython 1.14 est vivant** (REPL UART
      115200 via le passthru, `network.WLAN` OK, flash 4 Mo, boot.py stub).
      **FAIT le 2026-08-13** : `firmware/esp32_modem/main.py` (MicroPython,
      commandes compatibles ~/picowifi PicoWiFiModemUSB) installé par
      raw-REPL (`tools/esp32/install_main.py`) et persistant. AT/ATI/AT?
      validés via passthru. Reste : ATC1 sur le vrai WiFi, ATDT vers un
      BBS, et le terminal Oric (US-MODEM.3). Pico W (2b) = plan B.
- [ ] US-MODEM.2b **Modem WiFi externe** (issue retenue) : repointer le pont
      UART du 6551 de `wifi_rxd/txd` vers 2 broches `gp[]` accessibles + doc
      câblage (TX/RX/GND). Cible décidée 2026-08-02 : **Pico W** (branché sur
      US2 pour l'ALIM 5 V ; données via UART GPIO sur le connecteur gp[], PAS
      via l'USB de US2 — un hôte USB-CDC FPGA serait trop lourd). Firmware :
      **arduino-pico** (réutilise le sketch modem, API WiFi ~ESP32 ; flash .uf2
      par BOOTSEL, trivial). Reste à faire : repointage RTL + portage sketch
      Pico W + brochage 3 fils.
- [ ] US-MODEM.3 **Phase 3 — Terminal Oric** : programme pilotant le 6551
      (poll RDRF, R/W $031C), v0 BASIC (PEEK/POKE pour AT/OK), v1 terminal ML
      (VT52/ANSI mini) vers un BBS. Réutiliser la logique de la référence.

## Épopée NETFS — Navigateur de fichiers WiFi (tap/dsk) (plan : docs/NETFS_WIFI.md)
Objectif : parcourir depuis l'Oric une arborescence de .tap/.dsk servie en
HTTP via WiFi, et charger le fichier choisi. Décisions (bmarty, 2026-08-02) :
.tap d'abord (.dsk après) ; OSD incrusté par le FPGA ; serveur HTTP + listing
JSON. Partage le lien ESP32↔FPGA de l'épopée MODEM.
- [ ] US-NETFS.1 **Protocole ESP32↔FPGA & client HTTP** : trames série
      (DIR/ENTRY/END côté ESP32 ; CD/UP/LOAD/REFRESH côté FPGA), multiplexées
      avec le modem sur l'UART ESP32. Firmware ESP32 : GET listing JSON d'un
      dossier → trames ENTRY ; sur LOAD, GET du fichier → stream cassette.
- [ ] US-NETFS.2 **OSD incrusté (FPGA)** : couche texte+curseur dans
      `hdmi_out.v` (police 8×8, fenêtre défilante), tampon des entrées de la
      page courante, navigation flèches `btn[3..6]` + FIRE, ouverture/fermeture
      OSD ; incrustation combinatoire (ne touche pas au timing vidéo).
      Testbench de rendu.
- [ ] US-NETFS.3 **Chargement .tap via WiFi (bout-en-bout)** : router le flux
      du fichier sélectionné ESP32 → `tape_injector` (réutilise le contrôle de
      flux crédits, source = UART ESP32). Validation sur carte.

## Épopée DISK — support .dsk (Microdisc) — EN COURS (démarrée 2026-08-12)
Objectif : émuler l'interface Microdisc (FDC WD1793 + EPROM microdis) pour
booter Sedoric et charger la logithèque disquette (dont `Citadelle.dsk`).
Références : `~/Oric1/src/io/microdisc.c` (wrapper : `$0310-$0313` = WD1793,
`$0314` W = contrôle INTENA/ROMDIS/side/drive/EPROM, `$0314`/`$0318` R =
/INTRQ//DRQ bit 7, actifs bas) et `~/Oric1/src/storage/disk.c` (WD1793
complet : types I-IV, timings réels, format MFM_DISK). ROM `microdis.rom`
(8 Ko) dispo dans `~/Oric1/roms`. **Révision 2026-08-12 : la source des
.dsk est la CARTE SD** (le plan WiFi de 2026-08-02 prédate l'épopée
US-SDCARD ; `fat32` liste déjà les `.dsk`). Pas de conflit ACIA : le
Microdisc s'arrête à `$0318`, l'ACIA est à `$031C-$031F` (comme la réf).
Architecture retenue : **buffer de PISTE en BRAM** (~6,4 Ko, piste MFM
brute du format MFM_DISK) rechargé depuis la SD à chaque seek (~200 ms,
comparable à une vraie mécanique 3") ; v1 en LECTURE SEULE.
- [x] US-DISK.1 **Cœur WD1793 RTL** (2026-08-12, validé en sim) fidèle à `disk.c` : registres
      cmd/track/sector/data, commandes type I (seek/step, h/V/r1r0),
      type II (read sector : recherche d'ID dans la piste MFM, DRQ par
      octet), type III (read address), type IV (force interrupt), status
      par type, timings réels (step 6-30 ms, latence rotation, RNF après
      5 tours d'index). Testbench : piste MFM synthétique en BRAM,
      séquences lecture/seek vérifiées contre le comportement de la réf.
- [x] US-DISK.2 **Wrapper Microdisc + intégration** (2026-08-12, VALIDÉ SUR
      CARTE) : registres `$0310-$0318` actifs-bas, EPROM 8 Ko overlay
      `$E000-$FFFF`, /ROMDIS combiné, IRQ si INTENA, **SW1 (DIP) =
      interface branchée** (OFF = Atmos intact). Sur carte : SW1 ON →
      « insert system disc », SW1 OFF → Atmos normal.
- [x] US-DISK.3 **Pistes depuis la SD** (2026-08-12, validé en sim :
      22 pistes réelles Citadelle au byte près) : accès aléatoire dans le
      fichier .dsk (fat32 : seek par re-suivi de chaîne de clusters +
      offset piste = f(side, track) de l'en-tête MFM_DISK), chargement du
      buffer de piste, poignée « disquette insérée » pour le WD1793.
- [x] US-DISK.4 **OSD : insérer un .dsk** (2026-08-13, VALIDÉ SUR CARTE :
      menu Sedoric au boot) : BTN4 sur un `.dsk` = insertion + reset auto
      (attente `dsk_inserted` puis ~5 ms) → boot EPROM → Sedoric. Gel du
      boot résolu (init RAM motif Oricutron + course seek/rechargement,
      cf. CHANGELOG). OSD ouvert/fermé : BTN4 ferme, appui suivant rouvre
      (fini les chargements cassette accidentels pendant un boot disque).
      `Citadelle.dsk` validé sur carte (choix du menu OK — l'« erreur de
      syntaxe » venait de la course de piste). Reste ouvert : lenteur des
      chargements de piste (cf. US-SD-SPEED).
- [x] US-SD-SPEED **SPI SD haute vitesse + seek FAT32 incrémental**
      (2026-08-13, VALIDÉ SUR CARTE — « ok cela fonctionne », gravé SPI) :
      SPI à 6,25 MHz après init (×16) et seek avant en O(1) depuis le
      cluster courant (`cur_base` dans fat32). Le boot Sedoric re-suivait
      la chaîne depuis le début du fichier à chaque piste (piste 60 ≈ 90
      sauts FAT à 390 kHz). Boot Sedoric rapide, Citadelle OK, cassette
      et Atmos pur sans régression.
- [x] US-DISK.5 **Écriture disquette** (TERMINÉ 2026-08-17, 4 phases sim OK) :
      - [x] Phase 1 : sd_spi écrit un bloc (CMD24) — test-sd-write, suite OK
      - [x] Phase 2 : fat32 écrit un bloc à un offset quelconque (suivi de
            chaîne FAT + LBA) — test-fat-write (offset 8192, 3e cluster), OK
      - [x] Phase 3 : dsk_track write-back (2026-08-17, sim OK) — `sec_we` écrit
            le secteur dans tbuf ; `wr_commit` déclenche le **RMW** des 1-2 blocs
            SD touchés (lecture bloc -> overlay des octets du secteur depuis tbuf
            -> réécriture via `fat32.wblk`). Overlay déterministe par `ocnt0`
            (octets dans le 1er bloc) ; `wblk_data` combinatoire (latence 1-cycle
            fatale au streaming, cf. `tb_fat_write`). **`test-dsk-write`** :
            écrit un secteur, recharge depuis la SD, vérifie la nouvelle donnée
            + secteur voisin intact ; **`test-dsk` (lecture) sans régression**.
      - [x] Phase 4 : WD1793 commande write sector (2026-08-17, e2e OK) —
            commande `0xA0`, DRQ pour recevoir 256 octets → `sec_we` vers tbuf
            (position via DRQ pour éviter la course avec le pulse), `wr_commit`
            en fin → attente `wr_ok`/`wr_err` (niveaux, échantillonnables à cen).
            Câblage top complet : WD1793 → microdisc → oric_atmos → dsk_track →
            fat32.wblk (tie-offs supprimés). Write-protect retiré. **`test-wd`
            (écriture 256 o) et `test-dsk-wr-e2e` (Write Sector → SD → relecture,
            secteur voisin intact) PASSED ; test-boot/dsk/microdisc/dsk-write
            sans régression.**
- [x] US-DISK.6 **Formatage — commande Write Track WD1793** (2026-08-17, sim OK) :
      `rtl/wd1793.v` — commande `0xF0` : parseur du flux IBM/MFM (réf. `~/Oric1`
      `disk.c`) — marque `FE` → champ ID 4 octets (secteur), `FB/F8` → champ data
      256 o poussé dans `tbuf` (`sec_we`, secteur = ID courant) ; gaps/CRC (`F5/
      F6/F7/4E`) ignorés ; write-back **par secteur** (réutilise la chaîne phase
      3/4), fin quand les `n_spt` secteurs sont écrits. Même anti-course
      `cur_offset` (incrément à l'échéance DRQ). **`test-wd`** (flux 17 secteurs →
      capture par secteur vérifiée) PASSED ; e2e/boot/microdisc sans régression.
      Permet un `INIT`/formatage Sedoric sur une piste déjà cataloguée (réécrit
      la donnée). Read Track reste non implémenté (peu utile).

## Épopée CSAVE — sauvegarde cassette — EN COURS (démarrée 2026-08-20)
Objectif : capturer la forme d'onde `CSAVE` que la ROM bit-bange sur PB7 et la
reconstruire en `.tap`. Miroir de l'épopée LOAD (`tape_injector`). Destination :
**les deux, en incrémental** — UART vers le PC d'abord (validation rapide),
carte SD ensuite. Décodeur de référence : `~/Oric1/src/io/cassette.c`
(`tape_capture_*`, mode `--tape-out-capture`).
- [x] US-CSAVE.1 **Démodulateur RTL** (2026-08-20, sim OK) : `rtl/tape_demod.v`
      — fronts montants PB7 → période front-à-front → seuil 512 µs (`CYC_THRESH`)
      → bit ; réassembleur d'octet par chasse au start (comme `GetTapeByte`,
      brûle la parité, ignore le nombre de stops) ; `byte_out`/`byte_valid` +
      `capturing` (fin sur `GAP_CYCLES` de silence). `sim/tb_tape_demod.v` (cible
      `test-tape-demod`) : boucle `tape_injector`→`tape_demod`, octets décodés ==
      amorce + données (flux simple + multi-blocs). **PASSED, suite sans
      régression.**
- [x] US-CSAVE.2 **Sortie UART vers le PC** (2026-08-20, synthèse OK, **carte à
      valider**) : `tape_demod` branché sur `tape_out` dans `top_ulx3s`, octets
      injectés dans le mux UART (priorité dump > SAVE > écran > crédits),
      `sav_capturing` coupe l'écran. `tools/recv_tap.py` : resync `0x16…0x24`,
      parse les blocs, écrit le `.tap`. Synthèse 85F propre (pas de double-driver),
      parseur validé sur flux synthétique. Reste : `CSAVE"NOM"` réel sur carte
      → `.tap` relisible par `send_tap.py`/un émulateur.
- [~] US-CSAVE.3 **Sortie carte SD** (stratégie **placeholder** retenue :
      écrase un `SAVE.TAP` pré-créé, pas de création FAT32) :
      - [x] **Phase A** (2026-08-20, sim e2e OK) : `rtl/tape_saver.v` — octets
            démod → double buffer ping-pong → `fat32.wblk` dans `SAVE.TAP` ;
            dernier bloc padé `0x00`, `nbytes` = taille réelle.
            `tools/gen_fat_test.py` : placeholder `SAVE.TAP` (4096 o, 0xEE).
            `sim/tb_tape_saver.v` (`test-tape-saver`) : chaîne complète
            injector→demod→saver→fat32→SD, 600 o (2 blocs, ping-pong), relecture
            vérifiée. `file_count` des tests fat32/dsk 7→8. Suite 29/29.
      - [x] **Phase B** (2026-08-20, synthèse OK, **carte à valider**) :
            intégration top — `fat32` 4ᵉ port de nom (`q4`), locator FSM qui
            verrouille l'index de `SAVE.TAP`, instance `tape_saver`, mux
            `fat32.wblk` disque↔saver (`sav_busy`). Save inhibée si `SAVE.TAP`
            absent (`sav_found`). Synthèse 85F propre, suite sans régression.
            Reste : `CSAVE"NOM"` réel sur carte → `SAVE.TAP` mis à jour.
      - [x] **Refinement** (2026-08-20, sim e2e + synthèse OK) : primitive
            `dsize_*` de fat32 (RMW du secteur de répertoire, octets 28-31),
            localisation de l'entrée mémorisée au parsing, déclenchée par le top
            à la fin de la save (`sav_done` → `sav_nbytes`). Post-check
            `tools/check_save_tap.py` sur l'image. `SAVE.TAP` porte sa taille
            réelle. **US-CSAVE.3 complète** (reste validation carte).
- [x] US-CSAVE.4 **Vraie création FAT32** (COMPLÈTE en sim 2026-08-24, **reste
      validation carte**) :
      lever le *placeholder* `SAVE.TAP` — créer un vrai fichier `.tap` sur la SD
      (allocation de cluster + entrée de répertoire) au lieu d'écraser un fichier
      pré-existant. Stratégie retenue : **allocation incrémentale** (clusters
      alloués à la demande pendant l'écriture, pas de pré-allocation ni de
      troncature).
      - [x] **Phase 1 — Allocateur de cluster** (2026-08-24, sim + check OK) :
            `fat32.v` gagne `alloc_start/alloc_prev → alloc_clus/alloc_done/
            alloc_error`. Scanne la FAT depuis le cluster 2 (multi-secteur),
            trouve la 1re entrée libre, la marque **EOC** (RMW du secteur FAT
            via `secbuf`) ; si `alloc_prev≠0`, chaîne aussi `prev → nouveau`
            (extension). `sim/tb_fat_alloc.v` (cible `test-fat-alloc`) : 3 allocs
            chaînées, la persistance de l'EOC est prouvée (alloc #2 rend c1+1) ;
            `tools/check_fat_alloc.py` valide la chaîne FAT sur l'image. Trous FAT
            de l'image de test bouchés (`gen_fat_test.py`) → 1er libre > 128,
            scan multi-secteur exercé. Top : allocateur tie-off (pas encore
            piloté).
      - [x] **Phase 2 — Création d'entrée de répertoire** (2026-08-24, sim OK) :
            `fat32.v` gagne `mkent_start/mkent_name/mkent_clus/mkent_size →
            mkent_idx/mkent_done/mkent_error`. Scanne le répertoire racine
            (`DIRSECS` secteurs), trouve un slot libre (1er octet `0x00`/`0xE5`),
            écrit l'entrée 8.3 (nom, attr 0x20, cluster hi/lo, taille) par RMW du
            secteur, puis ajoute le fichier au listing en mémoire (visible sans
            re-parse). `sim/tb_fat_mkent.v` (cible `test-fat-mkent`) : alloc +
            création de `NEWSAVE.TAP`, contrôle du listing mémoire, puis
            **re-parse** de l'image → le fichier réapparaît (nom/cluster/taille),
            persistance prouvée.
      - [x] **Phase 3 — Extension de chaîne** (2026-08-24, sim OK) : nouvel input
            `wblk_extend` — quand l'écriture (`wblk`) atteint la fin de chaîne
            (EOC), si `wblk_extend=1` l'allocateur est invoqué en sous-routine
            (`wb_extending`) pour allouer et chaîner un cluster puis poursuivre ;
            si `wblk_extend=0`, comportement inchangé (`wblk_error`, fichiers
            disque pré-alloués). `sim/tb_fat_extend.v` (cible `test-fat-extend`) :
            crée un fichier neuf (alloc + entrée), écrit 3 blocs (SPC=1 → 2
            extensions), relit les 1536 o par le chemin de lecture (suivi de la
            chaîne construite) — contenu conforme.
      - [x] **Phase 4 — Intégration top** (2026-08-24) : orchestration `mkfile`
            (alloc + dirent) branchée au `tape_saver`, **nom réel du `CSAVE"NOM"`**
            extrait de l'en-tête cassette. La phase 5 (e2e) est intégrée dans D2
            (`tb_tape_create`).
            - [x] **D1 — Extracteur de nom** (2026-08-24, sim OK) : `rtl/tape_name.v`
                  observe le flux `tape_demod` (amorce 0x16 → 0x24 → 9 o d'en-tête
                  → nom ASCII + 0x00) et reconstruit un nom 8.3 (troncature 8,
                  majuscules, `[A-Z0-9]` sinon `_`, extension `TAP`, défaut
                  `NONAME`). `sim/tb_tape_name.v` (cible `test-tape-name`) : nom
                  normal, minuscules/invalides, troncature, nom vide.
            - [x] **D2 — Orchestration** (2026-08-24, sim e2e + synthèse OK) :
                  `rtl/tape_creator.v` (intègre `tape_name`) séquence
                  extraction du nom → `alloc` → `mkent` (nom réel, taille 0) →
                  `file_ready`/`file_idx` → écriture `tape_saver` (avec
                  `wblk_extend`) → `dsize` (taille réelle) à la fin. `tape_saver`
                  gagne `file_ready` (le 1er bloc attend la création ; il
                  bufferise pendant l'amorce). `top_ulx3s` remplace le locator
                  `SAVE.TAP` + le bloc `dsize` par `tape_creator` ; `alloc`/
                  `mkent`/`dsize` de fat32 pilotés par lui, `wblk_extend=sav_busy`.
                  `sim/tb_tape_create.v` (cible `test-tape-create`) : chaîne e2e
                  complète (injector→demod→creator+saver→fat32→SD), flux avec
                  en-tête + nom « TESTPROG », capture du flux décodé réel, puis
                  re-parse → fichier `TESTPROGTAP` créé, taille inscrite, contenu
                  relu identique. **Plus de placeholder SAVE.TAP.** Reste :
                  validation carte.
      - [ ] **Phase 5 — e2e** : injector→demod→saver→(création+écriture)→SD,
            relecture du `.tap` créé + vérif entrée + chaîne FAT.

## Épopée LOCI — émulation interne (plan : docs/LOCI_EMULATION.md)
> ⏸ **PARQUÉE (2026-08-17)** — décision « retour à l'Atmos pur » (on arrête
> d'élargir). Exploration conservée pour mémoire, non reprise pour l'instant.
Objectif : décider ce qui, de la carte LOCI (`sodiumlb/loci-hardware` 1.3,
firmware `loci-fw`), est émulable dans l'ECP5. **Constat de conception
(2026-08-17)** : la LOCI est un **RP2040 + firmware** ; son cœur (MIA `$03A0`,
API POSIX, ROM swap) est **logiciel**, non émulable en RTL pur, et **redondant**
avec la chaîne disque native déjà validée (épopée DISK). Seule brique retenue :
l'**ACIA 6551 à `$0380`** (canal modem LOCI), distincte du 6551 existant à
`$031C`. Le pont vers une **vraie** LOCI est un sujet séparé (`expansion_port.v`,
`docs/NOTE_EQUIPE_LIAISON_LOCI.md`).
- [x] US-LOCI.0 **Conception + périmètre** (2026-08-17) : `docs/LOCI_EMULATION.md`
      — cartographie LOCI, ce qui est/n'est pas émulable, recouvrement avec
      l'épopée DISK, brique ACIA `$0380` retenue, soft-CPU écarté.
- [ ] US-LOCI.1 **Décision** : (a) 2ᵉ 6551 à `$0380` coexistant avec `$031C`
      vs (b) 6551 commutable ; garde d'exclusivité avec une vraie LOCI branchée.
- [ ] US-LOCI.2 **RTL** `loci_acia` (ou paramétrage `acia6551.v`) + `sel_loci`
      prioritaire sur `sel_ext` + testbench `tb_loci_acia`.
- [ ] US-LOCI.3 **Intégration** top + pont UART + synthèse timing.
- [ ] US-LOCI.4 **Validation carte** : dialogue AT depuis l'Oric sur `$0380`.

## Épopée LOCI-SOC — soft-core RISC-V exécutant loci-fw (plan : docs/LOCI_SOC.md)
> ⏸ **PARQUÉE (2026-08-17)** — décision « retour à l'Atmos pur ». Conception
> conservée, non reprise.
Objectif : LOCI fidèle via un **soft-core VexRiscv/LiteX** dans l'ECP5 exécutant
un **portage de `loci-fw`**. **Faits de conception (2026-08-17)** : aucun portage
RP6502→FPGA n'existe (*from scratch*) ; ARM M0 open = expérimental → **RISC-V**
(LiteX a une cible ULX3S). « Tel quel » impossible : recompilation + réécriture du
HAL RP2040 (PIO/DMA/dual-core/USB/XIP). Les couches PIO-bus et WD1793 sont
**redondantes** avec le natif → on garde la **logique applicative** (MIA/API,
menu, fatfs) et on branche sur le bus 6502 natif + SD. **Seul vrai mur : l'USB
host du modem** (repli v0 = UART/ESP32). Approche dé-risquée par spikes.
- [x] US-LOCI-SOC.0 **Conception SoC** (2026-08-17) : `docs/LOCI_SOC.md` —
      faisabilité, choix RISC-V, carte SoC, HAL gardé/réécrit, point USB, jalons.
- [ ] US-LOCI-SOC.1 **Spike** : VexRiscv minimal qui boote sur ULX3S (blinky+UART).
- [ ] US-LOCI-SOC.2 **Mémoire & stockage** : SDRAM + SD lus par le soft-core (fatfs).
- [ ] US-LOCI-SOC.3 **Coexistence** SoC ↔ cœur Oric sans casser le boot actuel.
- [ ] US-LOCI-SOC.4 **MIA bridge** : registre-file `$03A0-$03BF` RTL, 1er API_OP.
- [ ] US-LOCI-SOC.5 **Portage loci-fw** (RV32) : logique MIA/API/menu, op par op.
- [ ] US-LOCI-SOC.6 **Modem** : décision USB (v0 UART/ESP32) puis fidélité.
- [ ] US-LOCI-SOC.7 **Validation carte** : menu LOCI piloté depuis l'Oric.

## Épopée ULA-NG — extensions « voie Telestrat » : banques mémoire + vidéo étendue
> **Frontière avec `~/oric2`** (2026-08-10) : le projet Oric 2 « chimère »
> (65C816, OricOS multitâche, GPU blitter, golden model Phosphoric) est un
> **workspace séparé** (`~/oric2`). Ici, `ulx3s_oric` reste l'Atmos fidèle
> en 6502, étendu à la manière de l'époque (Telestrat/Sedoric) — pas de
> duplication de la chimère.
Objectif : étendre l'ULA FPGA vers la spec ULA-NG de la référence
(`~/Oric1/docs/ula-ng/ULA-NG-SPEC.md`) : commutation ROM/RAM pilotée par
l'ULA, banques ROM, puis modes vidéo NG (80 colonnes, chunky 4bpp).
Décisions (bmarty, 2026-08-10) : registre de banque logé dans la fenêtre
ULA-NG (`$03E0-$03EF`, toujours visible) ; l'ULA exporte le signal de
sélection vers le décodage existant de `oric_atmos.v` (sémantique
`sel_rom`/`rom_as_ram` conservée — changement minimal) ; comportement
HCS10017 strict par défaut (verrouillage NG), boot sur la banque BASIC.
Expérience utilisateur (bmarty, 2026-08-10) : boot 100 % classique ; la
commande **`HIRES 1`** (argument inexistant en BASIC standard) bascule en
mode OCULA/NG + BASIC étendu ; `HIRES` sans argument = HIRES classique
inchangé. Implique une ROM 1.1b patchée (handler HIRES seul modifié) en
banque de boot + banque(s) d'extension via NG_BANK (trampoline RAM basse).
Prototypage de la ROM patchée dans l'émulateur `~/Oric1` d'abord.
ROM patchée = usage personnel uniquement (cf. dette technique).
Cible mémoire : 48 Ko RAM fixe + fenêtre 16 Ko à `$C000` commutée
(jusqu'à 4-8 banques ROM + RAM haute = « 64 Ko ROM / 64 Ko RAM »).
L'émulateur `~/Oric1` sert de modèle de référence à chaque incrément.

### Sous-chantier MULTIBANK — voie Telestrat fidèle (plan : docs/MULTIBANK.md)
> ⏸ **PARQUÉ (2026-08-17)** — décision « retour à l'Atmos pur ». Le RTL déjà
> livré (bank_window, VIA-2 $0320, telestrat_mode, SDRAM) reste en place mais
> **DORMANT et rétro-compatible** : `telestrat_mode`=0 dans le top, VIA-2 inactif
> tant que non écrit → l'Atmos boote strictement comme avant (test-boot vert).
> Aucune reprise (US-MBANK.3b et suivantes) tant que la décision tient.
**Décision (bmarty, 2026-08-17)** : le mécanisme de banques est spécifié
**Telestrat-fidèle** (spec confirmée sur le web, état de l'art 2026 : core FPGA
BigMist GPL-2.0, ORIX 2025). Fenêtre `$C000` = **8 banques** hétérogènes ROM/RAM,
sélecteur = **3 bits PA0-2 d'un 2ᵉ VIA à `$0320`** (et non le simple `NG_BANK
$03E0`, qui devient un alias optionnel) ; **bank 0 = overlay RAM** (STRATSED),
**bank 7 = TELEMON** (boot). Écritures `$C000` → toujours overlay RAM. Répond à
« RAM aussi ? » = OUI (RAM = banques comme les ROM ; BigMist a 128 Ko RAM).
Clean-room d'après la spec, pas de reprise du code GPL BigMist.
**Cible ORIX (2026-08-17)** : ORIX = **TELEMON 3.0** (bank 7 bootable, appels
`BRK_TELEMON`, 7 banques `orixbank1..7.rom` présentes dans `~/oricutron/roms/`).
La compat ORIX impose : **boot bank 7** (mode Telestrat, US-MBANK.3), **banques
en SDRAM** (112 Ko, US-MBANK.4, cf. `docs/MULTIBANK_SDRAM.md`) et un **CH376**
(stockage FAT32 d'ORIX, à émuler par-dessus `fat32.v`/`sd_spi.v` — modèle dans
`~/oricutron`). ROM ORIX/Telestrat = **usage perso, jamais commitées** (droits).
- [x] US-MBANK.0 **Conception** (2026-08-17) : `docs/MULTIBANK.md` (spec Telestrat,
      `bank_window.v` unifié ROM/RAM+overlay, intégration, budget BRAM/SDRAM, SotA).
- [x] US-MBANK.1 **`bank_window.v` + testbench** (2026-08-17, sim OK) : 8 banques
      logiques à rôle (0=vide→$FF, 1=ROM A, 2=ROM B, 3=RAM→overlay externe) ;
      sortie `bank_is_ram` (crochet banques RAM). Remplace `oric_rom` dans
      `oric_atmos.v` avec `bank_sel={2'b0,rom_bank}` → **strictement identique**
      (bank0=1.1b, bank1=1.0). `test-bank` (défaut + remap + is_ram) et **`test-boot`
      (boot BASIC complet, zéro régression) PASSED**. NB : overlay write + `/MAP`
      **non déplacés** dans le module (déjà servis par `oric_ram`+`rom_as_ram`) —
      écart assumé vs conception §2 pour zéro régression ; `bank_is_ram` les
      branchera en US-MBANK.4. `oric_rom.v` conservé (inutilisé) pour rollback.
- [x] US-MBANK.2 **2ᵉ VIA `$0320` → `bank_sel`** (2026-08-17, sim OK) :
      `via6522` réinstancié à `$0320-$032F` (`sel_via2`, retiré de `sel_ext`,
      ajouté au mux `cpu_di`) ; `bank_sel = (PA0-2 & DDRA) != 0 ? PA0-2 :
      {2'b0,rom_bank}` → le logiciel Telestrat pilote la banque par le port A,
      repli sur le BTN5 validé carte au reset (DDRA=0). IRQ du VIA-2 non câblée
      (banking seul). `test-bank-sel` (écriture DDRA/ORA → banque 1..7, masquage,
      repli) et **`test-boot` (zéro régression) PASSED**.
- [~] US-MBANK.3 **Mode boot Telestrat** (2026-08-17, sim OK) : `oric_atmos.v`
      — nouvel input `telestrat_mode` (câblé `1'b0` dans `top_ulx3s.v` = Atmos par
      défaut) ; `bank_sel` affiné **gate par DDRA** (banque 0 désormais
      sélectionnable ; ambiguïté US-MBANK.2 levée) : DDRA≠0 → banque du port A ;
      DDRA=0 → défaut = **banque 7 (TELEMON)** si `telestrat_mode`, sinon BTN5
      (BASIC 1.1b/1.0). `test-bank-sel` (gate DDRA + défaut bank7 + masquage) et
      **`test-boot` (zéro régression) PASSED**. Les 5 testbenches cœur câblent
      `telestrat_mode(1'b0)`. Reste **US-MBANK.3b** : charger les 7 ROM ORIX
      (`orixbank1..7`) en banques BRAM (conversion .rom→.hex, extension
      `bank_window` à 8 banques physiques, variante de build Telestrat) — les ROM
      restent gitignorées (droits).
- [~] US-MBANK.4 **Banques en SDRAM** (plan : docs/MULTIBANK_SDRAM.md) —
      investigation faite (2026-08-17). Cible ORIX = 7 banques × 16 Ko (112 Ko)
      → hors BRAM → **SDRAM**. Actif réutilisable : `sdram_ctrl.v` d'`~/oric2`
      (EUPL, bmarty, même carte). **Archi retenue** : banque active 16 Ko en
      BRAM adossée SDRAM, **re-remplie par DMA au changement de banque** (PAS de
      lecture SDRAM au fil de l'eau — latence/refresh vs bus 1 MHz). Sous-jalons :
      - [x] US-MBANK.4a Investigation + architecture (doc).
      - [x] US-MBANK.4b Porter `sdram_ctrl` + testbench SDRAM (**sim PASSED**
            2026-08-17 : `rtl/sdram_ctrl.v` + `sim/sdram_model.v` + `sim/tb_sdram.v`
            d'oric2, EUPL/bmarty ; `test-sdram` = init JEDEC + W/R + refresh, 0
            viol). Reste **sur carte** : `sdram_clk` (F19) + PLL + brochage dans
            `top_ulx3s.v` (non validable en sim). SDRAM réservée à la RAM haute.
      - [x] US-MBANK.4c **ABANDONNÉ** (2026-08-17) : mesure yosys — les banques
            ROM tiennent en BRAM (**121→177/208 EBR** avec 7 banques ORIX), donc
            pas de DMA refill (qui cassait le switch instantané des trampolines
            TELEMON). Switch instantané par `bank_sel` → voir US-MBANK.3.
      - [ ] US-MBANK.4d (RAM haute en SDRAM) — reporté, hors chemin critique ORIX.
- [ ] US-MBANK.5 Validation carte : booter TELEMON/ORIX, `!DIR` STRATSED.

- [~] US-ULA-NG.1 **Registre NG_BANK + commutation ROM/RAM** — première
      tranche FAITE (2026-08-11, validée sur carte) : `oric_rom.v` à
      2 banques (1.1b défaut + **BASIC 1.0**), bascule BTN5 + reset,
      Citadel (loader protégé, sensible à la révision ROM) chargé jusqu'au
      bout sur la banque 1.0. Reste : registre NG_BANK dans `$03E0-$03EF`
      (bit ROM/RAM + n° de banque, sélection via l'ULA), RAM haute,
      testbench POKE ; + nettoyage signature warm-boot à la bascule
      (bannière absente aujourd'hui : warm-boot silencieux).
- [ ] US-ULA-NG.2 **Palette + registres NG** : LUT palette redéfinissable,
      mécanisme de déverrouillage, fidèle à la spec et à l'émulateur.
- [ ] US-ULA-NG.3 **Texte 80 colonnes** (480 px, charset RAM natif,
      `NG_SCRSTART`, modes latchés en début de trame).
- [ ] US-ULA-NG.4 **Chunky 4bpp** 320×224, 16 couleurs (LUT NG).
- [ ] US-ULA-NG.5 **DOS en banque de boot + hooks façon Sedoric** (décision
      bmarty, 2026-08-10 — architecture actée, remplace l'« exploratoire ») :
      - Banque 0 (vecteur reset `$FFFC`) = **DOS** (cc65) : init, SD/FAT32
        (RTL existant), menu/chargement, installation des hooks, puis
        handover vers la banque BASIC (trampoline RAM basse + entrée à
        froid du BASIC). Modèle = ROM de boot Microdisc.
      - Banque 1 = BASIC 1.1b patché (`HIRES 1`, cf. US-ULA-NG.6) ;
        banques 2+ = extensions ; 5e position = RAM haute.
      - **DOS appelable depuis le BASIC** : hooks dans les vecteurs RAM
        page 2 + petit résident RAM basse ; commandes style Sedoric
        (`!DIR`, `!LOAD"X"`) → commutation NG_BANK aller-retour,
        échanges de données par la RAM basse (< `$C000`, seule zone
        visible des deux banques). Choisir l'emplacement du résident
        hors des zones système BASIC.
- [ ] US-ULA-NG.6 **BASIC étendu — bascule `HIRES 1`** : ROM 1.1b patchée
      (handler HIRES : argument optionnel ; sans argument = code d'origine),
      déverrouillage NG + commandes étendues en banque d'extension
      (trampoline RAM basse). Prototype dans l'émulateur `~/Oric1` d'abord.
- [ ] US-ULA-NG.7 **VRAM dédiée + modes « Hercules »** (décision bmarty,
      2026-08-10 : la vidéo étendue a sa VRAM à part) : framebuffer en BRAM
      séparé de la RAM 6502 (zéro contention CPU/vidéo), accès CPU par port
      indexé style VDP (registres adresse+données en `$03xx`). Modes visés :
      texte haute qualité (police 8×16 → 80×30, ou gros texte 14×18 → 45×26,
      à trancher) + hires 640×400 monochrome. Extension AU-DELÀ de la spec
      ULA-NG actuelle (480 px max, lecture RAM principale) → à spécifier
      d'abord dans `ULA-NG-SPEC.md` + émulateur, puis FPGA.
- [x] US-ULA-NG.8 **Mode turbo chargement** (2026-08-12, VALIDÉ SUR CARTE) :
      auto pendant `tape_active` — domaine cen1 (CPU+VIA+AY) 1→4,17 MHz +
      cassette au même ratio (~3× effectif avec les stops anti-IRQ),
      vidéo/ULA sur phase 1 MHz dédiée (écran vivant), retour 1 MHz à la
      fin (moteur coupé inclus). Cf. CHANGELOG (3 correctifs, enquête via
      tb_cload + désassemblage ROM). Resterait (plus tard) : registre
      NG_TURBO pour un turbo PERMANENT commandé par logiciel (jeu à
      8/16 MHz, VIA/AY à 1 MHz — découplage à concevoir).

## Épopée SPEECH — synthèse vocale TMS5220 (le chip voix de l'EXL 100)
Objectif : intégrer un TMS5220 (synthèse LPC Texas Instruments) en RTL dans
le cœur Oric. Décisions (bmarty, 2026-08-10) : réécriture Verilog-2005
fidèle à la référence MAME `tms5220.cpp` (pas de vrai chip 5 V sur le port
d'extension) ; mode **Speak External** uniquement (le CPU streame les
données LPC dans la FIFO — pas de ROM VSM propriétaire) ; pilotage par
2 adresses dans la page `$03xx` (fenêtre libre à choisir entre les zones
réservées Microdisc/LOCI/ACIA/ULA-NG) ; sortie mixée avec l'AY dans le
chemin audio existant (jack + HDMI). Aucun logiciel Oric d'époque ne le
supporte : c'est notre soft (BASIC POKE, puis ROM système US-ULA-NG.5)
qui l'exploitera.
- [ ] US-SPEECH.1 **Cœur LPC TMS5220** : filtre en treillis 10 coefficients,
      excitation chirp/bruit, interpolation de trames, FIFO Speak External,
      status /READY. Testbench de non-régression contre la référence MAME
      (mêmes trames LPC → mêmes échantillons).
- [ ] US-SPEECH.2 **Intégration Oric** : décodage 2 registres page `$03xx`
      dans `oric_atmos.v` (data/status + handshake), mixage avec l'AY vers
      jack + HDMI, synthèse 85F en timing.
- [ ] US-SPEECH.3 **Outillage + démo** : encodeur PC WAV → flux LPC
      (python_wizard ou équivalent), envoi depuis l'Oric (BASIC POKE ou
      loader), démo « l'Oric parle » validée sur carte.

## Sprint 3 — « Confort »
- [ ] US3.0b **Berceau PCBA « LOCI-Bridge » — routage** (pivot 2026-08-14) :
      la carte à fabriquer est le BERCEAU (l'ULX3S s'enfiche, LOCI par nappe
      IDC 34, schéma = SPEC_NETLIST loci_lvc, 5× LVCC3245A + BSS138).
      Fait : spec convergée avec l'étude ~/NetMaze/ulx3s2Loci (cotes J1/J2
      relevées : 2×20 pas 2,54, entraxe 88,90 mm, piège pairs/impairs des
      embases mâles). Reste : (1) récupérer la table gp/gn ↔ broches J1/J2
      depuis le KiCad emard/ulx3s (pas en local), (2) gen_pcb berceau
      (réutiliser la table U1..U5 de loci_lvc, remplacer peigne par IDC),
      (3) routage. AVANCÉ 2026-08-14 (hardware/berceau, b293439) :
      généré (JB1/JB2 par positions exactes du relevé emard/ulx3s — piège
      pairs/impairs éliminé par construction), TOUS les signaux routés par
      freerouting, plans F.Cu=GND / B.Cu=3V3|5V, vias d'alim posés.
      RESTE (~30 min de KiCad interactif, cf. hardware/berceau/README.md) :
      ~15 liaisons d'alim (îlots de plan isolés), 3 courts, sérigraphie,
      puis REVUE MÉCANIQUE (sens d'enfichage, hauteurs, détrompeur) avant
      gerbers/PCBA. La variante B (loci_lvc, carte peigne) reste gelée
      (7d4b66b).
- [ ] US3.0 **Validation LOCI sur le port d'extension** (demandée 2026-08-13) :
      le bus 34 points est câblé et actif (`rtl/expansion_port.v`,
      `docs/PORT_EXTENSION.md`, gp/gn J1-J2, pull-ups OK, /IOCTRL inhibe
      VIA/ACIA/Microdisc interne). Config visée : cartouche **LOCI** +
      **Pico W sur le port USB externe de la LOCI** (transparent pour le
      FPGA — seul le bus d'extension nous concerne). Matériel à réunir (révision
      2026-08-13 : PAS de TXS0108E — auto-sens inadapté à un bus parallèle
      push-pull, cf. PORT_EXTENSION.md) : 4× 74LVC245 DIP-20 (données
      DIR=R/W + adresses/contrôles + entrées), BSS138 pour /RESET, alim
      5 V externe pour la cartouche (JAMAIS le 5 V du FPGA), masse
      commune, Dupont < 20 cm avec GND intercalés. Consigne : **SW1 OFF** (Microdisc interne
      débranché — la LOCI sert son propre DOS via /ROMDIS+/MAP, éviter
      tout double décodage $0310-$0318). Premier test : boot BASIC normal
      cartouche branchée mais inactive, puis menu LOCI (ADJ_SCAN si
      instable).
- [ ] US3.1 OSD de sélection de fichiers .tap → couvert par US-NETFS.2 (OSD
      incrusté FPGA) ; la source de fichiers devient le serveur WiFi.
- [ ] US3.2 Mode 60 Hz optionnel / meilleure synchro vidéo (triple buffer)
- [x] US3.3 Joystick USB → interface joystick Oric (2026-08-20, sim+synthèse OK,
      **carte à valider**) : `rtl/joystick_ijk.v` (interface IJK, Port A du VIA,
      portage `~/Oric1` joystick.c) ; gamepad USB HID (`game_*`) synchronisé et
      superposé sur `via_pa_in` dans `oric_atmos`. `test-joystick` (9 vecteurs).
- [ ] US3.4 Shift register VIA complet + entrée cassette réelle (jack)

## Sprint 4+ — « Atmos moderne » (carte format Atmos)
- [x] US4.1 Conception bandeau LOCI terminée (144/144, DRC 0) — NON commandée : blocs intégrés à la carte unique (décision carte unique 2026-07-29)
- [ ] US4.2 Carte UNIQUE « Atmos moderne » : Tang Nano + 2 Pico W + TXS + tous connecteurs — hérite des blocs du bandeau
- [ ] US4.3 **PRIORITAIRE — Portage du core sur Tang Nano 20K** (Gowin
      GW2AR-18, yosys synth_gowin + apicula ; PLL/TMDS/USB à adapter).
      Prérequis d'usage du bandeau phase A : c'est le Tang Nano qui le
      pilote (décision 2026-07-29). L'ULX3S reste banc de dev ECP5.
- [ ] US4.4 Carte format Atmos (phase B) : mesures boîtier, routage,
      berceaux Pico W ×2 + Tang Nano, micro-SD externe (découpe TV),
      HP + PAM8302, imprimante via Pico
- [ ] US4.5 Firmware LOCI natif sur Pico #1 (build loci-firmware, SD)

## Dette technique / risques identifiés
- Battement 50/60 Hz → tearing occasionnel (accepté v1, cf. US3.2).
- usb_hid_host ne gère que les claviers *boot protocol* low-speed ; certains
  claviers USB ne répondent pas (prévoir un clavier simple).
- ROM : droits d'auteur — usage personnel uniquement, pas de redistribution.

## Sprint 5 — « Boîtier maîtrisé »
- [ ] US5.1 Boîtier paramétrique OpenSCAD silhouette Atmos : profil extrait
      des STL OriClone (hardware/boitier/profil_coupe.json), paramètres :
      profondeur 175 (fidèle/clavier d'origine) ou 205 (clavier MX),
      découpes arrière générées depuis les coordonnées du PCB phase B,
      tuilage imprimable 220×220 (queues d'aronde + bossages à vis)
- [ ] US5.2 Chaînage/nettoyage du profil brut en polygone propre
- [ ] US5.3 Rendu STL + impression test d'un tronçon

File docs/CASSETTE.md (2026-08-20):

# Chargement de programmes `.tap` (cassette)

L'ULX3S charge un fichier `.tap` Oric via un **injecteur cassette dans le
FPGA** : le PC envoie le `.tap` sur l'UART (US1, le câble de programmation),
le FPGA génère la forme d'onde cassette exacte et la présente à la ROM comme
une vraie lecture de bande. Fonctionne pour le **BASIC et le code machine**,
quelle que soit la taille du fichier (contrôle de flux par crédits).

## Utilisation

1. Sur l'Oric, lance la lecture :
   ```
   CLOAD""
   ```
   (le moteur cassette démarre, la ROM attend l'amorce). La **LED5** de la
   carte s'allume pendant le chargement.

2. Sur le PC, envoie le fichier :
   ```sh
   tools/send_tap.py monjeu.tap /dev/ttyUSB0
   ```
   (`pip install pyserial` si besoin ; le port par défaut est `/dev/ttyUSB0`.)

L'ordre est indifférent : le FPGA tamponne l'amorce jusqu'au démarrage du
moteur. À la fin, l'Oric affiche le nom du programme puis `Ready`. Lance-le
avec `RUN` (BASIC) — le code machine démarre souvent tout seul.

## Comment ça marche

- **Chemin de lecture** (déjà présent) : `tape_in` → **VIA CB1** → routine
  `CLOAD` de la ROM, qui mesure l'intervalle entre fronts (Timer 2).
- **Injecteur** (`rtl/tape_injector.v`) : modulation strictement conforme au
  générateur de référence `~/Oric1/src/io/cassette.c` :
  - trame de **14 bits**, LSB d'abord : start(0), 8 data, **parité impaire**,
    4 stop(1) ;
  - **amorce** de 64 trames de synchro `0x16`, puis les données ;
  - chaque bit = 2 demi-pulses, front montant toujours à +208 µs ; période
    bit `1` = 416 µs (courte), bit `0` = 624 µs (longue), seuil ROM 512 µs ;
  - la bande n'avance que quand le **moteur** (VIA PB6) est actif.
- **Contrôle de flux par crédits** : l'Oric consomme la bande à ~137 o/s,
  bien plus lentement que l'UART (115200). Le FPGA renvoie un octet de crédit
  (`0x5A`) sur `ftdi_rxd` pour chaque octet qu'il peut absorber ; le script PC
  envoie exactement un octet `.tap` par crédit → jamais de débordement, même
  pour un jeu de 48 Ko.

## Sauvegarde `CSAVE` → `.tap` (épopée CSAVE)

Le chemin inverse : l'Oric **sauvegarde** un programme sur cassette (`CSAVE`),
le FPGA **démodule** la forme d'onde et renvoie le `.tap` reconstruit au PC.

1. Sur le PC, arme la réception :
   ```sh
   tools/recv_tap.py monprog.tap /dev/ttyUSB0
   ```
2. Sur l'Oric :
   ```
   CSAVE"NOM"
   ```
   (le moteur démarre, la ROM bit-bange la forme d'onde sur **PB7**). Quand la
   sauvegarde se termine, le script écrit `monprog.tap` (relisible ensuite par
   `send_tap.py` ou un émulateur).

### Comment ça marche

- **Chemin d'écriture** (ROM) : `CSAVE` génère la forme d'onde sur **PB7** via le
  Timer 1 — mêmes trames 14 bits, amorce `0x16`, pulses 416/624 µs que la
  lecture.
- **Démodulateur** (`rtl/tape_demod.v`, miroir de `tape_injector.v` et portage
  du décodeur de référence `~/Oric1/src/io/cassette.c`) : ne compte que les
  **fronts montants** de PB7, mesure la période front-à-front, applique le seuil
  512 µs (< → `1`, > → `0`), puis réassemble l'octet par **chasse au start**
  (saute les stops `1`, premier `0` long = start, 8 bits data LSB d'abord, brûle
  une période de parité) — exactement comme `GetTapeByte` (`$E6C9`).
- **Sortie UART** : les octets décodés partent sur `ftdi_rxd` (priorité
  dump > SAVE > écran > crédits) ; `sav_capturing` coupe le streamer écran
  pendant la capture. Débit bande (~137 o/s) très inférieur à l'UART → aucun
  tampon.
- **Réception PC** (`tools/recv_tap.py`) : se resynchronise sur l'amorce
  `0x16…0x24` (écarte tout octet écran reçu avant), parse la structure des blocs
  (en-tête 9 o → adresses fin/début → nom → `fin-début+1` octets de données)
  pour connaître la fin exacte, puis écrit le `.tap`.

### Sauvegarde sur la carte SD (SAVE.TAP)

En parallèle de la voie UART, le FPGA peut écrire le `.tap` directement sur la
carte, dans un fichier **placeholder pré-créé** `SAVE.TAP` (racine de la carte,
taille max fixe — l'allocation FAT32 / la création d'entrée n'est pas faite,
seul le contenu est écrasé).

- `rtl/tape_saver.v` consomme les octets du démodulateur, les accumule dans un
  **double buffer ping-pong** (512 o) et les écrit bloc par bloc via
  `fat32.wblk` (même chemin que le write-back disque). Le dernier bloc est
  complété par des `0x00`.
- Le top **localise `SAVE.TAP`** par son nom 8.3 (balayage du listing fat32) et
  mux `fat32.wblk` entre le write-back disque et le saver. Si `SAVE.TAP` est
  absent, la save SD est simplement inhibée (la voie UART reste disponible).
- À la fin de la sauvegarde, la **taille réelle** est inscrite dans l'entrée de
  répertoire de `SAVE.TAP` (primitive `dsize` de fat32 : RMW du secteur de
  répertoire, octets 28-31) — le fichier ne garde donc pas sa taille placeholder.

### Tests

`make test-tape-demod` : boucle `tape_injector` → `tape_demod`, vérifie que les
octets décodés == amorce `0x16` + données envoyées, sur flux simple et
multi-blocs. (La modulation de l'injecteur est déjà validée sur carte contre la
vraie ROM CLOAD, ce qui fait de la boucle un test de fidélité du démodulateur.)

`make test-tape-saver` : chaîne complète `tape_injector → tape_demod →
tape_saver → fat32.wblk → sd_card_file`, joue une charge > 512 o (2 blocs,
exerce le ping-pong), relit `SAVE.TAP` et vérifie amorce + données + padding.

## Protocole UART

```
PC  -> FPGA : 0x01, len_lo, len_hi, <len octets .tap>
FPGA -> PC  : 0x5A  (un crédit par octet acceptable ; le PC répond 1 octet)
```
Pendant le mode cassette (`tape_active`), l'UART entrant est aiguillé vers
l'injecteur `.tap` et **non** vers le clavier série — les deux ne se marchent
pas dessus.

## Tests

`make test-tape` : le testbench redécode la forme d'onde produite (périodes
front-à-front → bits → trames) et vérifie l'amorce `0x16`, le framing
(start/parité/stop) et l'égalité données décodées = données envoyées, ainsi
que le nombre de crédits.

## Limites

- Taille ≤ 65535 octets (limite ROM Oric).
- Un seul fichier à la fois ; relance `CLOAD""` + le script pour le suivant.
- **Jeux à loader protégé/maison** (ex. `citadel.tap`, Loriciels 84 : bloc 1
  autorun qui recharge la suite via des points d'entrée INTERNES de la ROM,
  après vérification d'empreinte `$FFF9`/`$E4B6`) : ces jeux sont sensibles à
  la **révision exacte de la ROM**. Citadel connaît la 1.0 et la 1.1
  d'origine (`$E4B6=$A2`) mais PAS notre 1.1b (code décalé, `$E4B6=$8E`) →
  « Errors found » quel que soit le flux. **Vérifié en émulateur
  (2026-08-11)** : avec la ROM **1.0** ET l'amorce inter-blocs (celle que
  notre RTL insère — l'émulateur ne l'a pas, il a fallu la simuler dans le
  fichier), Citadel charge et tourne. → Prise en charge = **banque ROM 1.0
  sélectionnable sur BTN5** (US-ULA-NG.1) — **VALIDÉ SUR CARTE le
  2026-08-11** : Citadel charge ses 4 blocs jusqu'au « Choix des couleurs »
  sur la banque 1.0. Vérifier la banque active : `PRINT PEEK(#FFF9)`
  (1 = 1.1b, autre = 1.0 ; la bascule fait un warm-boot silencieux, pas de
  bannière). NB : le mode signal de la référence `~/Oric1` bénéficierait
  aussi de l'insertion d'amorce inter-blocs (amélioration à reporter).

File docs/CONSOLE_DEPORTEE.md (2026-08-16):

# Console déportée (écran + clavier sur PC, sans moniteur ni clavier)

Piloter l'Oric sur ULX3S **sans écran HDMI ni clavier USB** : le FPGA streame
le framebuffer par l'UART FTDI (US1) et reçoit les frappes par la même liaison.

## Principe

- `rtl/screen_stream.v` envoie en boucle le **framebuffer** 240×224×4 bits
  (le rendu final de la ULA → couvre **TEXT, HIRES et modes mixtes**).
  Trame : en-tête `AA 55 F0 0F` puis 26880 octets (2 pixels/octet).
- `rtl/framebuffer.v` : lecture par le **port d'écriture** aux cycles où la
  ULA n'écrit pas (`rd_valid`) → BRAM 2 ports, pas de duplication.
- Clavier : `rtl/key_injector.v` (déjà présent) injecte l'ASCII reçu.
- **UART FTDI à 1 Mbaud** (`FTDI_BAUD` dans `top_ulx3s.v`) : ~3-4 images/s
  en plein écran, texte fluide. Priorité UART : dump (BTN2) > cassette/
  chargeur > écran (l'écran ne streame qu'à l'idle).

## Outils PC

- **`tools/screen_gui.py`** (recommandé) : fenêtre Tkinter WYSIWYG, clavier
  capturé dans la fenêtre. `python3 tools/screen_gui.py [-z ZOOM]`.
- `tools/screen_view.py` : rendu ANSI dans le terminal (`-k` = clavier ;
  `--snap out.png` = capture fidèle). Sensible à la taille du terminal.

## À savoir

- Tous les outils PC sur le FTDI utilisent désormais **1 Mbaud**
  (`send_tap.py`/`dump_sd.py` : ajouter `--baud 1000000`).
- Ne pas ouvrir deux outils sur `/dev/ttyUSB0` en même temps (accès exclusif).

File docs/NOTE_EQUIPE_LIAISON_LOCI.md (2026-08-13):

# Note à l'équipe — liaison physique vers la LOCI (berceau ULX3S) + revue croisée

**De :** bmarty · **Date :** 2026-08-13 · **Objet :** convergence avec
`PORT_EXTENSION.md`, apport d'un **berceau PCBA**, et 2 points à corriger.

En marge du projet **NetMaze** (client Oric qui parle à l'ACIA `$0380`), j'ai
mené une étude indépendante de raccordement **Oric-émulé-sur-ULX3S ↔ LOCI réelle**
(dossier `~/NetMaze/ulx3s2Loci/`). Elle **recoupe très largement** notre
`docs/PORT_EXTENSION.md` et `rtl/expansion_port.v` déjà en place. Cette note fait
le point : ce qui se valide mutuellement, ce que j'apporte de neuf, et 2 détails
à corriger.

---

## 1. Validation croisée (rassurant : deux analyses indépendantes concordent)

- **Brochage du connecteur 34 points** : identique. Je l'ai reconstruit par
  connectivité du **schéma réel de la LOCI 1.3** (`sodiumlb/loci-hardware`,
  `SCH_loci-1.3.json`) → mêmes affectations que notre table (pins 33/34 = +5 V/GND).
- **Adaptation de niveau** : même conclusion — **74LVC (DIR//OE), TXS0108E
  proscrit** (auto-sens → contention avec le 74LVC4245A push-pull de la LOCI,
  sensible à la capacité). Confirmé aussi par la BOM réelle de la LOCI
  (U3 = 74LVC4245A, buffers Schmitt 5 V-tolérants en entrée).
- **`/OE` du transceiver data** : même piège identifié — `/OE = /IO` **ne suffit
  pas** (la LOCI sert sa ROM menu en `$C000–$FFFF` via /ROMDIS+/MAP, hors page
  I/O). Notre solution (`/XCVR_OE` passant pendant Φ2, ou masse) est la bonne.
- **Architecture d'inhibition** : `oric_atmos.v` gère déjà proprement le partage
  du bus — ACIA interne en **`$031C–$031F`**, microdisc `$0310–$031B`, et
  `sel_ext = sel_io & ~sel_via & ~sel_acia & ~sel_md`, le tout **inhibé par
  `ext_ioctl`**. Donc **aucune collision** avec la LOCI en `$0380` : elle tombe
  dans `sel_ext`, et /IOCTRL retire les périphériques internes. 👍

---

## 2. Apport nouveau : un **berceau PCBA** (au lieu du câblage Dupont)

`PORT_EXTENSION.md` cible le **câblage Dupont**. Pour fiabiliser (et « ne pas se
tromper » : une inversion 5 V→GPIO grille l'ECP5), je propose une **petite carte
berceau assemblée** (SMD monté en usine, type JLCPCB PCBA) sur laquelle **l'ULX3S
s'enfiche** et où la LOCI arrive par nappe IDC 34 — **zéro fil volant**.

**Cotes mécaniques relevées** (extraction du `.kicad_pcb` d'`emard/ulx3s`,
empreintes `Socket_Strip_Angled_2x20`, vérifiées dans le contour) :

| Cote | Valeur |
|---|---|
| Connecteurs J1/J2 | 2×20, **pas 2,54 mm**, rangées verticales |
| **Entraxe centre-à-centre J1↔J2** | **88,90 mm** (= 35 × 2,54, alignés en Y) |
| Rangées internes / externes | 86,36 / 91,44 mm |
| Longueur d'un connecteur | 48,26 mm |
| Carte ULX3S | ≈ 93,98 × 50,8 mm |

⚠️ **Piège mécanique** (note du schéma ULX3S) : la numérotation 1–40 vaut pour
l'embase **femelle coudée** ; pour une embase **mâle verticale** (berceau),
**échanger pairs/impairs** — ou câbler par **nom de net GPx/GNx**.

Le berceau reprend exactement notre schéma : **2× 74LVC4245A dual-supply**
(le même que la LOCI, réf LCSC **C6091**), pull-ups, découplage, cavaliers
(source 5 V, `/OE` masse↔`/XCVR_OE`). Détails et BOM à réfs LCSC :
`~/NetMaze/ulx3s2Loci/docs/carte-interface-pcb.md`.

---

## 3. Deux points à corriger / clarifier (revue de `rtl/`)

1. **`gp[16]` / `gn[16]` = zone ADC « évitée »** — dans `top_ulx3s.v` le
   transceiver data est piloté par `pin_xcvr_dir = gp[16]` et
   `pin_xcvr_oe_n = gn[16]`, or le commentaire juste au-dessus dit
   « gp/gn[11..17] évitées : partagées avec l'ESP32 et l'ADC », et le `.lpf`
   confirme **gp[16]=N16 (ADC AIN5)**, **gn[16]=M17 (ADC AIN4)**.
   → Est-ce intentionnel (ADC non utilisé, broches libres) ? Sinon, déplacer
   `xcvr_dir`/`xcvr_oe_n` vers 2 nets hors 11..17 (p. ex. `gp/gn[23]`, libres).
   À trancher **avant** de figer le typon du berceau.

2. **Commentaire obsolète dans `expansion_port.v`** — l'en-tête mentionne encore
   « câblage Dupont + **TXS0108E** » (lignes ~10 et ~ chronologie), ce qui
   contredit la décision **anti-TXS0108E** de `PORT_EXTENSION.md`. À aligner pour
   éviter qu'un contributeur reparte sur le TXS0108E.

---

## 4. Mapping GPIO — `top_ulx3s.v` fait foi

Ma proposition initiale (côté `ulx3s2Loci`) plaçait les signaux différemment ;
**la référence est le HDL réel** (`top_ulx3s.v`) :

- `pin_a = {gp[22:18], gp[10:0]}` → **A0..A10** = gp[0..10], **A11..A15** = gp[18..22]
- `pin_d = gn[7:0]` → **D0..D7**
- `gn[8]=R/W`, `gn[9]=Φ2`, `gn[10]=/IO`
- `gn[18]=/RESET`, `gn[19]=/IRQ`, `gn[20]=/ROMDIS`, `gn[21]=/MAP`, `gn[22]=/IOCTRL`
- `gp[16]=XCVR_DIR`, `gn[16]=/XCVR_OE` (cf. point 3.1)

→ J'**aligne** `ulx3s2Loci/docs/mapping-gpio-contraintes.md` et le typon du berceau
sur cette table (et non l'inverse).

---

## 5. Livrables disponibles (dossier `~/NetMaze/ulx3s2Loci/`)

- `docs/etude-liaison-physique.md` — signaux/directions, **brochage CN1** reconstruit
  du schéma LOCI, niveaux, timing.
- `docs/carte-interface-pcb.md` — **berceau PCBA** (cotes, BOM LCSC, fichiers PCBA).
- `docs/mapping-gpio-contraintes.md` — mapping signal→GPIO→**bille ECP5** + `.lpf`.
- `docs/plan-physique-fils-volants.md` — variante breadboard (validation rapide).

---

## 6. Proposition de suite

1. Trancher le **point 3.1** (gp/gn[16] vs ADC).
2. Aligner le mapping `ulx3s2Loci` sur `top_ulx3s.v` (**§4**).
3. Router le **berceau** (EasyEDA → PCBA) avec l'entraxe 88,90 mm.
4. Bring-up : ULX3S enfiché + nappe LOCI, Φ2 nominal (marges OK à 1 MHz, la LOCI
   ayant son ADJ_SCAN).

Retours bienvenus, surtout sur le point 3.1.

— bmarty

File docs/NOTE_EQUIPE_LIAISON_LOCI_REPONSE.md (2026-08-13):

# Réponse — liaison LOCI : points tranchés et vigilances berceau

**De :** session ulx3s_oric · **Date :** 2026-08-13 · **Réf. :**
`NOTE_EQUIPE_LIAISON_LOCI.md` (étude `~/NetMaze/ulx3s2Loci`).

Merci pour la revue croisée — les concordances (brochage 34 points depuis le
schéma LOCI 1.3, anti-TXS0108E, piège `/OE=/IO`, inhibition /IOCTRL) valident
les deux analyses. Réponses aux points ouverts :

## 3.1 — gp/gn[16] : INTENTIONNEL, on garde (tranché)

- `gp/gn[23]` ne sont **pas libres** : le port imprimante Centronics occupe
  `gp[23..27]` **et** `gn[23..27]` (`top_ulx3s.v` : `prn_data`,
  `prn_strobe_n=gn[26]`, `prn_ack=gn[27]`). Hors de la plage 11..17, il ne
  reste **aucune** paire disponible.
- Dans 11..17, les broches partagées **ESP32** (gp/gn[11..13]) sont désormais
  à éviter en priorité : depuis le 2026-08-13 l'ESP32 interne est ACTIF
  (modem Hayes MicroPython sur son UART) — ne pas hypothéquer ses GPIO.
- Les broches **ADC** (gp/gn[15..17]) sont le choix le moins risqué : l'ADC
  est un esclave SPI que notre bitstream ne sélectionne jamais, ses entrées
  AIN sont en haute impédance. `gp[16]=XCVR_DIR`, `gn[16]=/XCVR_OE` sont
  **figés** (commités, gravés en flash SPI le 2026-08-13). Le typon du
  berceau peut partir là-dessus.
- Seule réserve documentée : si un jour un bitstream utilise l'ADC, il devra
  éviter AIN4/AIN5 — noté ici, nulle part ailleurs à corriger.

## 3.2 — commentaire TXS dans `expansion_port.v` : CORRIGÉ

L'en-tête renvoie maintenant explicitement à la famille 74LVC(C)245 à
DIR//OE et au caractère proscrit du TXS0108E (commit du 2026-08-13).

## Vigilance berceau : la BOM à « 2× 74LVC4245A » est INSUFFISANTE

Il faut **31 signaux répartis sur 4 directions différentes** :

| Groupe | Canaux | Direction |
|---|---|---|
| Données D0-D7 | 8 | bidir pilotée (DIR=XCVR_DIR, /OE=/XCVR_OE) |
| Adresses A0-A15 | 16 | sortie figée |
| R/W, Φ2, /I/O | 3 | sortie figée |
| /IRQ, /ROMDIS, /MAP, /IOCTRL | 4 | entrée figée |
| /RESET | 1 | drain ouvert bidir → **BSS138**, PAS un transceiver |

Un transceiver 8 bits n'a qu'un DIR : il faut **5 puces** (2 ne suffisent
pas). Affectation complète prête à réutiliser telle quelle :
`hardware/loci_lvc/SPEC_NETLIST.md` (U1..U5, pull-ups de sécurité, canaux
inutilisés non flottants). ⚠️ Brochage vérifié datasheet TI SCAS585R : le
SN74LVCC3245A est un **TSSOP-24** (1=VCCA, 2=DIR, 3-10=A1-8, 11-13=GND,
14-21=B8-B1, 22=/OE, 24=VCCB, DIR//OE référencés VCCA) — ne pas partir
d'un brochage '245 DIP à 20 broches.

## Articulation des deux cartes

- **Berceau PCBA** (ULX3S enfichée + nappe IDC 34) = voie retenue si l'on
  passe par JLCPCB PCBA — c'est la meilleure réponse au « ne pas se
  tromper ». Entraxe 88,90 mm et piège pairs/impairs (embase mâle verticale)
  bien notés : câbler par **nom de net**, jamais par numéro 1-40.
- `hardware/loci_lvc/` (carte peigne 34 + connecteurs nappe, 110×50, spec
  commitée, routage freerouting en cours) devient la **variante B**
  (fabrication sans assemblage usine). Pas de double fabrication : on fige
  le berceau d'abord.

## Divers

- `ATDISKRD` : introuvable dans `~/picowifi` (tables AT du firmware
  épluchées : aucun $DISK) et dans `~/NetMaze`. En attente d'une définition
  avant implémentation dans le modem MicroPython.

— session ulx3s_oric

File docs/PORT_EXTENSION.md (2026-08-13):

# Port d'extension Oric sur GPIO ULX3S

Reconstitution du connecteur d'extension 34 points de l'Oric Atmos (annexe 11
du manuel officiel) sur les en-têtes GPIO de l'ULX3S, pour brancher une vraie
cartouche — cible : **LOCI**.

## Brochage officiel du connecteur Oric (34 points, mâle vu de l'arrière)

| Broche | Signal  | Sens (vu de l'Oric) | | Broche | Signal | Sens |
|---:|---|---|-|---:|---|---|
| 1  | /MAP | entrée  | | 2  | /ROMDIS | entrée  |
| 3  | Φ2 | sortie  | | 4  | /RESET  | bidir |
| 5  | /I/O | sortie  | | 6  | /IOCTRL | entrée  |
| 7  | R/W | sortie  | | 8  | /IRQ | entrée  |
| 9  | D2 | bidir | | 10 | D0 | bidir |
| 11 | A3 | sortie  | | 12 | D1 | bidir |
| 13 | A0 | sortie  | | 14 | D6 | bidir |
| 15 | A1 | sortie  | | 16 | D3 | bidir |
| 17 | A2 | sortie  | | 18 | D4 | bidir |
| 19 | D5 | bidir | | 20 | A4 | sortie  |
| 21 | A5 | sortie  | | 22 | D7 | bidir |
| 23 | A6 | sortie  | | 24 | A15 | sortie  |
| 25 | A7 | sortie  | | 26 | A14 | sortie  |
| 27 | A8 | sortie  | | 28 | A13 | sortie  |
| 29 | A9 | sortie  | | 30 | A12 | sortie  |
| 31 | A10 | sortie  | | 32 | A11 | sortie  |
| 33 | +5V | alim | | 34 | GND | alim |
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

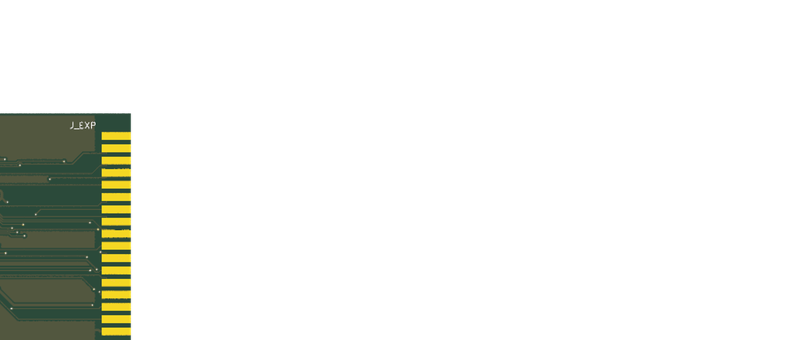
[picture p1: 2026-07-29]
hardware/phaseA/zone_crop.png

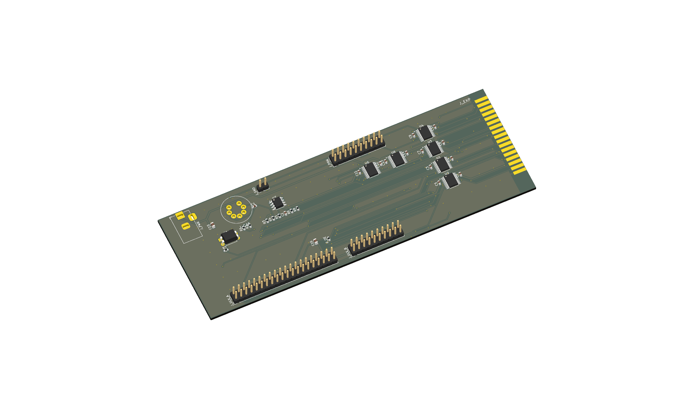
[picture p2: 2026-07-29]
hardware/phaseA/vue3d_composants.png

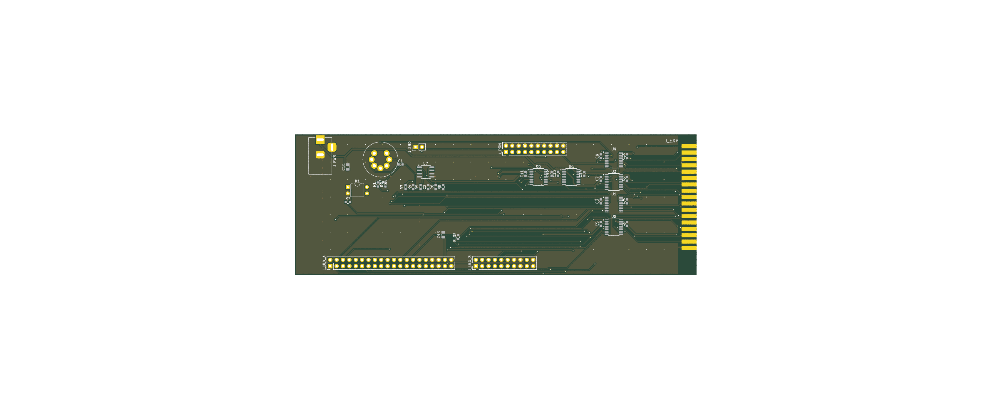
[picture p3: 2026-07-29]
hardware/phaseA/rendu_final_top.png

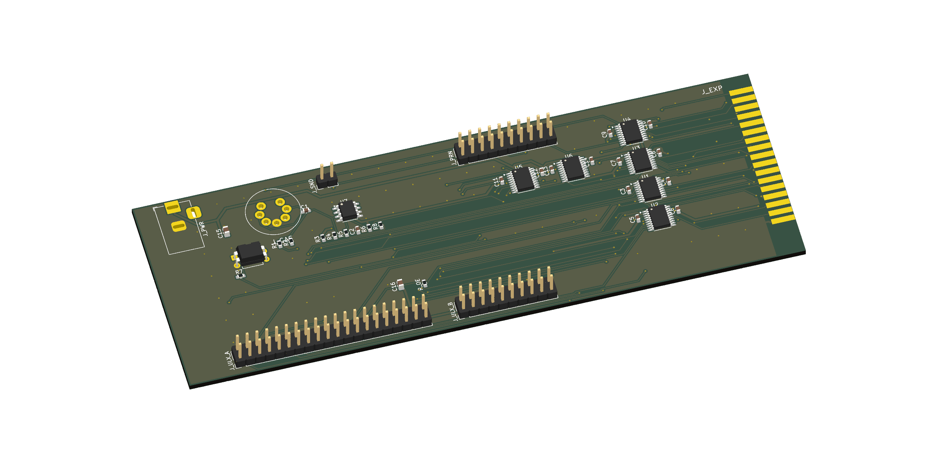
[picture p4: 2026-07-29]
hardware/phaseA/vue3d_face.png

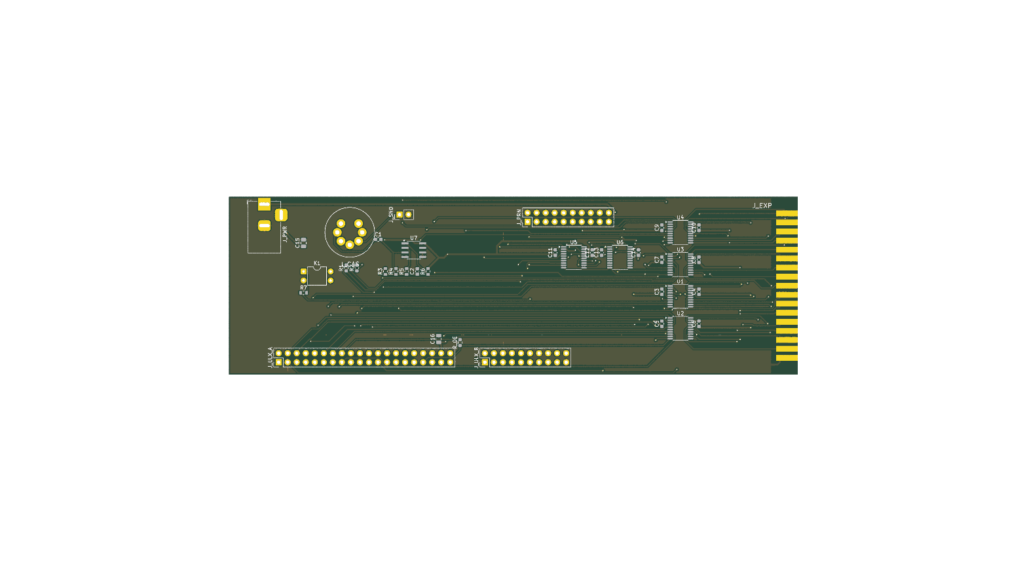
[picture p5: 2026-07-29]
hardware/phaseA/render_top.png

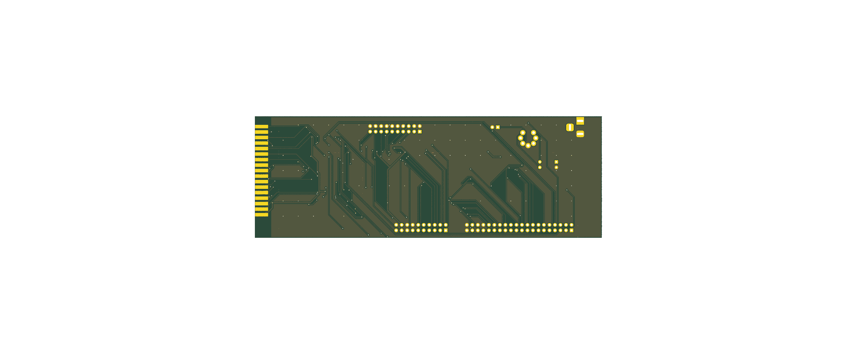
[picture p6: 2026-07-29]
hardware/phaseA/rendu_final_bottom.png

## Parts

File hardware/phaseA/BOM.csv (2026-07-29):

Comment | Designator | Footprint | LCSC Part #
1uF | C1 | C_0603_1608Metric | C15849
100nF | C10,C11,C12,C13,C14,C2,C3,C4,C5,C6,C7,C8,C9 | C_0603_1608Metric | C14663
10uF | C15,C16 | C_0805_2012Metric | C15850
DIN41524_7pin_270deg_Female | J_CAS | DIN41524_7pin_270deg_Female | TBD
Conn_02x10 | J_PRN,J_ULX_B | PinHeader_2x10_P2.54mm_Vertical | TBD
Jack_5.5x2.1 | J_PWR | BarrelJack_Horizontal | TBD
Conn_01x02 | J_SND | PinHeader_1x02_P2.54mm_Vertical | TBD
Conn_02x20 | J_ULX_A | PinHeader_2x20_P2.54mm_Vertical | TBD
AQY212GH | K1 | DIP-4_W7.62mm | TBD
10k | R1,R6,R_OE | R_0603_1608Metric | C25804
1k | R2 | R_0603_1608Metric | C21190
100k | R3,R4,R5 | R_0603_1608Metric | C25803
470 | R7 | R_0603_1608Metric | C23179
1M | R8 | R_0603_1608Metric | C22935
TXS0108EPWR | U1,U2,U3,U4,U5,U6 | TSSOP-20_4.4x6.5mm_P0.65mm | C17206
LM393 | U7 | SOIC-8_3.9x4.9mm_P1.27mm | C67470

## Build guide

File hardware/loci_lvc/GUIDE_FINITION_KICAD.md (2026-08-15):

# Guide de finition dans KiCad — `loci_lvc_6l2` (25 liaisons)

But : partir du board **`loci_lvc_6l2.kicad_pcb`** (routé à 90 %, 0 violation) et
finir à la main les **11 signaux + 14 masses** restants, pour obtenir un board
**0 non-connecté, 0 violation**, prêt à commander.

Temps estimé : 30–45 min. Aucune expérience KiCad préalable requise — suis les
étapes.

---

## 0. Ouvrir le board
1. Installer **KiCad 9** (kicad.org).
2. Ouvrir **`loci_lvc_6l2.kicad_pcb`** (double-clic, ou KiCad → *Éditeur de PCB*).
3. Menu **Affichage → repère** : tu vois la carte (120×50 mm), les 5 puces, le
   peigne à droite, le connecteur en bas à gauche.

Les liaisons **non finies** apparaissent comme de **fines lignes blanches**
(le « chevelu » / ratsnest). Il y en a 25.

---

## 1. Coudre les 14 masses (le plus simple — commence par ça)
Chaque masse manquante = un pad GND à relier aux plans internes.

Pour **chaque** fine ligne blanche qui part d'un pad **GND** :
1. Touche **`V`** (pose un via) **juste à côté du pad** (dans une zone dégagée,
   0,5–1 mm du pad), puis clique. Le via traverse les plans GND internes → le pad
   est relié.
2. Si le via est trop près d'autre chose, KiCad le refuse (croix rouge) : déplace-le
   d'un poil.

💡 Astuce : règle le via par défaut à **0,6 mm / perçage 0,3 mm**
(*Préférences → Règles de conception*), c'est conforme.

À la fin, **Édition → Remplir toutes les zones** (`B`) : les masses se connectent.

---

## 2. Router les 11 signaux (sur les couches internes libres In2/In3)
Nets concernés (approx.) : des `A5V*`, `D5V*`, `D*`, quelques contrôles.

Pour **chaque** fine ligne blanche entre **deux pads de signal** :
1. Sélectionne la couche **In2.Cu** (menu déroulant des couches, en haut, ou touche
   `+`/`-` pour changer de couche active).
2. Touche **`X`** (router une piste), clique sur le **premier pad**, tire la piste
   vers le **second pad**, double-clic pour finir.
3. Si ça bloque (pad recouvert d'une piste), pose un **via `V`** juste à côté du pad
   pour **descendre sur In2.Cu**, puis route sur In2 jusqu'à l'autre pad (remonte
   avec un via si besoin).
4. Si In2 est encombré à un endroit, utilise **In3.Cu** (change de couche en cours
   de route avec `V`).

Largeur de piste : **0,2 mm** suffit (les couches internes sont peu chargées).

---

## 3. Vérifier (DRC)
1. **Inspecter → Vérificateur de règles de conception (DRC)**.
2. Clique **Exécuter le DRC**.
3. Objectif : **0 élément non connecté** et **0 violation**.
   - S'il reste des non-connectés : une fine ligne blanche subsiste → route-la.
   - S'il reste des violations (clearance, etc.) : double-clic dessus, KiCad zoome
     sur le problème → écarte la piste/le via fautif.

---

## 4. Générer les fichiers de commande
Une fois **DRC propre** :
1. **Fichier → Fabrication → Gerbers** : coche toutes les couches cuivre + masque +
   sérigraphie + contour ; **Générer**. Puis **Générer les fichiers de perçage**.
2. **Fichier → Fabrication → Position des composants** (pour l'assemblage) :
   format CSV.
3. **BOM** : voir `SPEC_NETLIST.md` (composants + réfs LCSC).
4. Zippe les Gerbers + drill → upload sur **JLCPCB** (choisir **6 couches**),
   ajouter BOM + placement pour le service **PCBA**.

---

## En cas de blocage
- Un pad **vraiment inatteignable** : route-le sur **B.Cu** (couche du dessous) en
  posant un via à côté, puis remonte au pad destination par un autre via.
- Reviens vers moi avec une **capture d'écran** de la zone bloquée : je te dirai
  précisément où passer.

> Rappel : le fichier de départ `loci_lvc_6l2.kicad_pcb` est déjà routé à 90 % et
> **sans aucune erreur** — tu ne fais qu'ajouter les 25 dernières liaisons.

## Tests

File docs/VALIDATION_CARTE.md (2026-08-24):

# Procédure de validation carte — ulx3s_oric

Checklist de tests **matériels** (carte ULX3S 85F) pour les fonctionnalités
actuellement marquées « sim OK, validation carte à faire » dans
[BACKLOG.md](BACKLOG.md) :

| # | Fonctionnalité | US | Statut carte |
|---|---|----|---|
| 1 | LEDs d'activité (IRQ/VSYNC/USB) | US2.3 | ⬜ à valider |
| 2 | Joystick USB → IJK | US3.3 | ⬜ à valider |
| 3 | Sauvegarde cassette → UART/PC | US-CSAVE.2 | ⬜ à valider |
| 4 | **Sauvegarde cassette → création SD** | US-CSAVE.4 | ⬜ à valider |

> Coche chaque case et note la date/observations au fil de l'eau. En cas
> d'échec, reporte le symptôme précis (LEDs, écran, sortie PC) — c'est ce qui
> permet de diagnostiquer.

---

## 0. Préparation commune

### Matériel
- Carte **ULX3S 85F** + câble USB (port **US1**, côté FPGA/FTDI) vers le PC.
- Écran **HDMI** branché.
- **Clavier USB** sur le port USB hôte de la carte.
- Pour les tests SD : une **micro-SD formatée FAT32** (voir §4).
- Pour le test joystick : un **gamepad USB HID**.

### Build + flash du bitstream
```bash
cd ~/ulx3s_oric
make                 # synthèse -> build/oric_ulx3s.bit (déjà à jour si non modifié)
make prog            # flash volatile (openFPGALoader -b ulx3s)
# ou : make prog-fujprog
```
> `make prog` charge en SRAM (volatile, perdu à la coupure). Pour un flash
> **permanent** en SPI, se référer à la procédure `--unprotect-flash` déjà
> utilisée (cf. historique v1.1.0). Pour la validation, le flash volatile suffit.

### Critère de bon départ
Après flash + reset (**BTN1**), l'écran HDMI affiche le **BASIC Oric** (« Atmos »
/ prompt `Ready`). Le clavier USB permet de taper. Si ce n'est pas le cas,
inutile d'aller plus loin — vérifier alimentation, HDMI, flash.

---

## 1. US2.3 — LEDs d'activité (IRQ / VSYNC / USB)

**But** : vérifier l'overlay d'activité sur les 8 LEDs, activé par **SW4** (`sw[3]`).

### Étapes
1. Boot normal (BASIC affiché).
2. Basculer **SW4** (4ᵉ interrupteur) sur **ON**.
3. Observer les LEDs **hautes** :
   - **LED7 (IRQ)** et **LED6 (VSYNC)** : allumées ~en continu tant que le cœur
     tourne (heartbeat — l'IRQ ~100 Hz et le VSYNC 50 Hz rechargent en
     permanence le monostable).
   - **LED5 (USB)** : **flashe** à chaque frappe clavier / événement gamepad.
4. Repasser **SW4** sur **OFF** : les LEDs reviennent à la **vue diagnostic**
   SD/FAT/sélection habituelle (inchangée).

### ✓ Succès
- SW4=ON → LED7 et LED6 allumées, LED5 clignote quand on tape au clavier.
- SW4=OFF → affichage diagnostic normal restauré.

### Dépannage
- LED7/LED6 éteintes alors que l'écran vit → problème d'horloge/IRQ, à investiguer.
- LED5 ne flashe pas à la frappe → chaîne USB HID (mais le clavier fonctionne
  déjà si on voit les caractères ; vérifier que SW4 est bien lu).

---

## 2. US3.3 — Joystick USB → interface IJK

**But** : un gamepad USB pilote le port joystick **IJK** (VIA Port A, côté
imprimante) vu par un programme Oric.

### Pré-requis
- Un **gamepad USB HID** reconnu (`typ==3`). Il se branche sur le **même port
  USB** que le clavier (hub si besoin de garder le clavier).
- Un programme Oric qui **lit l'IJK** (jeu compatible interface Jasmin/IJK, ou
  petit programme BASIC de lecture du port A imprimante). Réf. mapping :
  [JOYSTICK.md](JOYSTICK.md).

### Étapes
1. Boot, brancher le gamepad USB.
2. Charger/lancer un jeu compatible IJK (via SD/OSD ou cassette).
3. Actionner la croix directionnelle et les boutons **A/B** (= FIRE).

### ✓ Succès
- Les **directions** (haut/bas/gauche/droite) et le **feu** (A ou B) répondent
  dans le jeu.
- Mapping attendu (actif bas sur Port A) : bit0=RIGHT, 1=LEFT, 2=FIRE, 3=DOWN,
  4=UP ; présence signalée dès reconnaissance du gamepad.

### Dépannage
- Rien ne répond → vérifier que le gamepad est bien en `typ==3` (certains
  manettes s'énumèrent autrement). Tester d'abord qu'il est reconnu (une action
  fait flasher **LED5** en mode SW4=ON, §1).
- Un seul stick est émulé (stick A ; stick B non câblé) — conforme à la réf.

---

## 3. US-CSAVE.2 — Sauvegarde cassette → UART / PC

**But** : un `CSAVE` de l'Oric est reçu sur le PC via l'UART FTDI et reconstruit
en `.tap`.

### Étapes
1. Sur le **PC**, lancer le récepteur **avant** de sauvegarder :
   ```bash
   tools/recv_tap.py monprog.tap /dev/ttyUSB0
   ```
   (`pip install pyserial` si besoin.)
2. Sur l'**Oric**, entrer un petit programme puis le sauvegarder :
   ```basic
   10 PRINT "HELLO"
   CSAVE"TEST"
   ```
3. Attendre la fin (le script clôt le `.tap` après un silence).

### ✓ Succès
- `recv_tap.py` écrit `monprog.tap` sans erreur.
- Relecture : renvoyer le fichier à l'Oric le recharge correctement —
  ```bash
  tools/send_tap.py monprog.tap /dev/ttyUSB0
  ```
  puis sur l'Oric `CLOAD""` → `RUN` doit afficher `HELLO`. (Ou vérifier avec un
  émulateur type Oricutron.)

### Dépannage
- Rien reçu → l'écran cède l'UART pendant la capture (`sav_capturing`) ; vérifier
  le bon port `/dev/ttyUSB*` et qu'aucun autre process ne l'occupe.
- `.tap` corrompu → noter la taille reçue et l'octet de divergence.

---

## 4. US-CSAVE.4 — Sauvegarde cassette → **création SD** (nouveau)

**But** : un `CSAVE"NOM"` **crée de zéro** un fichier `NOM.TAP` sur la micro-SD
(allocation FAT + entrée de répertoire + écriture + taille), **sans** placeholder
pré-existant. C'est la fonctionnalité la plus neuve — à tester en priorité.

### Pré-requis micro-SD
- Carte **micro-SD** formatée **FAT32** (MBR **ou** superfloppy ; les deux sont
  gérés). Idéalement quelques fichiers `.tap`/`.dsk` déjà présents pour que l'OSD
  ait un listing — mais **aucun `SAVE.TAP` n'est requis** (placeholder supprimé).
- Insérer la carte dans le lecteur SD de l'ULX3S **avant** le boot.

### Étapes
1. Boot. Vérifier via l'OSD (BTN3/BTN4) que la carte est **lue** (listing des
   `.tap`/`.dsk`). Fermer l'OSD.
2. Sur l'Oric, entrer un programme identifiable puis :
   ```basic
   10 PRINT "SD SAVE OK"
   CSAVE"MONJEU"
   ```
3. Attendre la fin de la sauvegarde (bande « jouée », puis silence).
4. **Éteindre la carte**, retirer la micro-SD, la monter sur le **PC**.

### ✓ Succès
- Un fichier **`MONJEU.TAP`** (nom réel du `CSAVE`, tronqué 8.3, majuscules)
  est présent à la racine de la SD, avec une **taille non nulle et cohérente**.
- `fsck.vfat -n /dev/sdXn` (carte non montée) **ne signale aucune incohérence
  FAT** (correctif multi-FAT : les 2 copies sont écrites).
- Relecture : le fichier est un `.tap` valide —
  ```bash
  tools/send_tap.py MONJEU.TAP /dev/ttyUSB0   # rejoue vers l'Oric
  ```
  puis `CLOAD""` + `RUN` → affiche `SD SAVE OK`. (Ou ouvrir dans Oricutron.)
- Nom vide (`CSAVE""`) → fichier créé sous le nom **`NONAME.TAP`**.

### Points de vérification spécifiques (issus de la revue)
- **Multi-fichiers** : faire **deux** `CSAVE` de noms différents → deux fichiers
  distincts créés, tous deux relisibles, FAT cohérente.
- **Capture interrompue** : lancer un `CSAVE` puis couper (reset **BTN1**) avant
  la fin → au reboot, un nouveau `CSAVE` doit **toujours fonctionner** (pas de
  blocage résiduel ; correctif anti-blocage `had_file`).
- La voie **UART (§3)** fonctionne **simultanément** : on peut lancer
  `recv_tap.py` en parallèle du `CSAVE` qui écrit sur SD.

### Dépannage
- Fichier absent → vérifier que la SD était bien lue au boot (OSD non vide) ;
  la création est inhibée si la FAT n'a pas été parsée.
- Taille = 0 ou fichier tronqué → noter la taille et l'état FAT (`fsck.vfat -v`).
- `fsck` signale une divergence FAT → régression du correctif multi-FAT, à
  remonter.
- Aucune sauvegarde ne marche après une capture coupée → régression du correctif
  anti-blocage, à remonter.

---

## Journal de validation

| # | Test | Date | Résultat | Observations |
|---|---|---|---|---|
| 1 | LEDs d'activité (SW4) | | ⬜ | |
| 2 | Joystick IJK | | ⬜ | |
| 3 | CSAVE → UART | | ⬜ | |
| 4 | CSAVE → création SD | | ⬜ | |
| 4b | Multi-fichiers SD | | ⬜ | |
| 4c | Capture coupée → pas de blocage | | ⬜ | |

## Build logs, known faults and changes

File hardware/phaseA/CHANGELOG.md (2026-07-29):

# CHANGELOG — hardware/phaseA

## 2026-07-29 — Génération initiale des fichiers de fabrication JLCPCB
- `gen_pcb.py` : construction scriptée complète de `phaseA.kicad_pcb`
  depuis SPEC_NETLIST.md (contour 160×50 mm, 39 empreintes, 99 nets,
  peigne 34 doigts custom bord droit, DIN-7 270° custom, zones GND F/B,
  netclasses Default 0,25 mm / Power 0,5 mm, vias 0,6/0,3).
- `route.py` : pipeline de routage freerouting (export DSN pcbnew →
  patch DSN des doigts → freerouting 2.1.0 headless → import SES →
  re-remplissage zones). Freerouting 2.2.4 écarté (exige Java 25,
  Java 21 installé).
- `make_fab.py` : BOM.csv + CPL.csv au format JLCPCB (LCSC vérifiés :
  TXS0108EPWR=C17206, LM393DR=C67470, passifs basic parts).
- `Makefile` : cibles pcb / drc / gerbers / fab.
- `QUESTIONS.md` : ambiguïtés de la spec et interprétations retenues
  (sens du peigne, AQY212GH THT/CMS, DIN-7 mécanique, J_SND.2, jack pad 3).
- `COMMANDE.md` : options JLCPCB (2 couches, 1,6 mm, ENIG,
  gold fingers + biseau 45°, assemblage top).
- Corrections en cours de génération : orientation des headers 2×N
  (broches hors carte), jack alim affleurant le bord haut, géométrie
  DIN-7 (cercle Ø7 mm, pastilles 2,4/1,3), retrait 0,05 mm des doigts
  (DRC bord de cuivre).
- Gerbers + perçage Excellon exportés dans `gerbers/` (voir Makefile).

## 2026-07-29 (b) — Intégration des révisions de spec du jour
- SPEC_NETLIST.md révisée en parallèle par bmarty : R8 1 MΩ (hystérésis
  LM393), nouvel ordre J_ULX_A (fan-out monotone), pas du peigne confirmé
  (Amphenol 34 pts / 2,54 mm).
- gen_pcb.py : ajout R8 (replacé en (59;21), l'emplacement initial
  court-circuitait U7.8), nouveau mapping J_ULX_A, FPID des empreintes
  custom, zones GND en connexion pleine (anti « starved thermal »).
- route.py : bord droit virtuel du DSN à 156,3 mm (le routeur ne passe
  plus sur la partie réelle des doigts), alim routée à 0,4 mm (limite
  d'isolation au pas TSSOP 0,65), patch robuste des noms SES.
- Carte re-routée entièrement (freerouting tour 3) après régénération.

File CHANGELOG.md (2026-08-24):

# CHANGELOG — ulx3s_oric

Toutes les modifications notables de ce projet sont documentées ici.
Format inspiré de [Keep a Changelog](https://keepachangelog.com/fr/).

## [Non publié]

### Documentation
- **Procédure de validation carte** (bmarty, 2026-08-24) : `docs/VALIDATION_CARTE.md`
  — checklist de tests **matériels** des fonctionnalités « sim OK, carte à
  valider » : US2.3 (LEDs d'activité via SW4), US3.3 (joystick IJK), US-CSAVE.2
  (sauvegarde → UART/PC) et US-CSAVE.4 (sauvegarde → **création SD** au nom réel).
  Chaque test : pré-requis, étapes, critères de succès et dépannage ; points de
  vérification spécifiques issus de la revue (multi-fichiers, capture coupée,
  cohérence FAT via `fsck.vfat`). Pointeur ajouté en tête de `BACKLOG.md`.

### Corrigé
- **US-CSAVE.4 — robustesse (revue adversariale)** (bmarty, 2026-08-24, **sim +
  synthèse OK**) : deux correctifs sur du code non encore validé sur carte,
  trouvés par une revue de code dédiée.
  - **Blocage sur CSAVE avorté** : si la capture s'arrêtait avant l'extraction du
    nom (bruit sur PB7 / flux tronqué), `tape_saver` posait `wr_req` et attendait
    `file_ready` (qui ne venait jamais) → `busy`/`armed` collés, cassant
    l'écriture disque et toute sauvegarde ultérieure jusqu'au reset. Ajout d'un
    verrou `had_file` : sans fichier créé, la capture est abandonnée proprement.
    `tape_creator` gagne un échappement `CR_ACTIVE` (via `sav_busy`) pour le cas
    symétrique. Nouveau scénario « capture avortée » dans `tb_tape_create`
    (saver + creator reviennent au repos).
  - **2ᵉ copie de la FAT non mise à jour** : l'allocateur n'écrivait que la 1re
    FAT (`fat_lba`) ; sur un volume `nfat=2` la 2ᵉ copie divergeait → un
    `chkdsk`/OS hôte « réparait » et pouvait casser le fichier. `AL_WR`/`AL_PWR`
    réécrivent désormais le secteur FAT sur les **`nfat` copies** (accumulateur
    `al_fatoff`, pas de multiplieur). `check_fat_alloc.py` vérifie la cohérence
    des deux copies.

### Ajouté
- **US-CSAVE.4 phase D2 — Orchestration de la vraie création cassette** (bmarty,
  2026-08-24, **sim e2e + synthèse OK, validation carte à faire**) : lève
  définitivement le placeholder `SAVE.TAP`. `rtl/tape_creator.v` (intègre
  `tape_name`) séquence toute la création pendant un CSAVE : extraction du nom →
  `fat32.alloc` (1er cluster) → `fat32.mkent` (entrée au **nom réel**, taille 0) →
  publication `file_ready`/`file_idx` → écriture par `tape_saver` (avec
  `wblk_extend`) → `fat32.dsize` (taille réelle) à la fin. La création tient dans
  l'amorce (~259 o) donc `file_ready` est prêt avant le 1er bloc de 512 o.
  `rtl/tape_saver.v` gagne l'input `file_ready` : il bufferise dès le 1er octet
  mais n'écrit le 1er bloc qu'une fois le fichier créé (aucun octet perdu).
  `rtl/top_ulx3s.v` remplace le locator `SAVE.TAP` + l'ancien bloc `dsize` par
  `tape_creator` ; `alloc`/`mkent`/`dsize` de fat32 pilotés par lui,
  `wblk_extend=sav_busy`. Nouveau `sim/tb_tape_create.v` (cible
  `test-tape-create`, ajoutée à `TESTS`) : chaîne e2e complète
  (injector→demod→creator+saver→fat32→SD) avec en-tête + nom « TESTPROG » ;
  capture le flux décodé réel (indépendant du modèle injecteur/démod), puis
  re-parse → fichier `TESTPROGTAP` **créé de zéro**, taille inscrite, contenu relu
  identique. `tape_name.v`/`tape_creator.v` ajoutés à la synthèse. **Suite
  complète + synthèse 85F sans régression.**
- **US-CSAVE.4 phase D1 — Extracteur de nom cassette** (bmarty, 2026-08-24,
  **sim OK**) : `rtl/tape_name.v` — observe (sans le consommer) le flux `.tap`
  produit par `tape_demod` et reconstruit le **nom 8.3** du fichier à partir de
  l'en-tête cassette Oric (amorce `0x16` → marqueur `0x24` → 9 octets d'en-tête →
  nom ASCII terminé `0x00`). Normalisation 8.3 : troncature à 8 caractères,
  minuscules → majuscules, `[A-Z0-9]` conservés sinon `_`, complété d'espaces,
  extension forcée `TAP` ; nom vide → `NONAME`. `capturing` bas réarme pour le
  CSAVE suivant. Décision produit : le fichier créé portera le **nom réel** du
  `CSAVE"NOM"`. Nouveau `sim/tb_tape_name.v` (cible `test-tape-name`, ajoutée à
  `TESTS`) : nom normal, minuscules+invalides, troncature > 8, nom vide. Module
  isolé (pas encore instancié dans le top). **Suite complète sans régression.**
- **US-CSAVE.4 phase 3 — Extension de chaîne à la demande** (bmarty,
  2026-08-24, **sim OK**) : `rtl/fat32.v` gagne un input `wblk_extend`. Quand
  l'écriture d'un bloc (`wblk`) atteint la fin de la chaîne (EOC), au lieu de
  `wblk_error` l'allocateur est invoqué **en sous-routine** (flag `wb_extending`,
  retour depuis `AL_PBUSY`/`AL_WBUSY` vers `WB_SKIP`) pour allouer et chaîner un
  cluster, puis l'écriture se poursuit dedans. `wblk_extend=0` conserve le
  comportement d'erreur (fichiers disque pré-alloués, `dsk_track`). Nouveau
  `sim/tb_fat_extend.v` (cible `test-fat-extend`, ajoutée à `TESTS`) : crée un
  fichier neuf (alloc + entrée, taille 1536), écrit 3 blocs de 512 o à des
  offsets croissants (image SPC=1 → chaque bloc après le 1er force une
  extension : clusters 335→336→337), puis relit les 1536 o par le chemin de
  lecture (suivi de la chaîne dynamiquement construite) — **contenu conforme**.
  `top_ulx3s` : `wblk_extend` câblé à 0 (phase D le passera à `sav_busy`).
  **Suite complète sans régression.**
- **US-CSAVE.4 phase 2 — Création d'entrée de répertoire FAT32** (bmarty,
  2026-08-24, **sim OK**) : `rtl/fat32.v` gagne `mkent_start`/`mkent_name`/
  `mkent_clus`/`mkent_size` → `mkent_idx`/`mkent_done`/`mkent_error`. Scanne le
  répertoire racine (`DIRSECS` secteurs), trouve un **slot libre** (1er octet
  `0x00` fin ou `0xE5` supprimé) et y écrit une **entrée 8.3** (nom 11 o, attr
  archive `0x20`, cluster high 20-21 / low 26-27, taille 28-31, reste à zéro) par
  RMW du secteur (états `ME_*`, remplissage octet-par-octet piloté par un décodeur
  combinatoire `me_val`). Le fichier est ajouté au **listing en mémoire**
  (`name/clus/size/dsk/dsec/doff_mem`) et son index renvoyé — visible sans
  re-parse. Nouveau `sim/tb_fat_mkent.v` (cible `test-fat-mkent`, ajoutée à
  `TESTS`) : allocation + création de `NEWSAVE.TAP` (cluster 335, taille 1234),
  contrôle du listing mémoire, puis **re-parse** de l'image → le fichier
  réapparaît avec le bon nom/cluster/taille (**persistance prouvée**). `top_ulx3s`
  câble `mkent` en tie-off. **Suite complète sans régression.**
- **US-CSAVE.4 phase 1 — Allocateur de cluster FAT32** (bmarty, 2026-08-24,
  **sim + check OK**) : première brique de la *vraie création FAT32* (lever le
  placeholder `SAVE.TAP`). `rtl/fat32.v` gagne une primitive d'allocation
  `alloc_start`/`alloc_prev` → `alloc_clus`/`alloc_done`/`alloc_error` : scanne
  la FAT depuis le cluster 2 (**balayage multi-secteur**, `al_sec`/`al_ae`),
  trouve la 1re entrée libre (== 0), la marque **EOC** (`0x0FFFFFFF`) par RMW du
  secteur FAT (réutilise `secbuf` + `ds_writing`) ; si `alloc_prev ≠ 0`, chaîne
  également `prev → nouveau cluster` (extension de fichier) par un 2ᵉ RMW.
  Sortie `alloc_error` si la FAT est pleine. `state` élargi à 6 bits (9 états
  `AL_*`). Nouveau `sim/tb_fat_alloc.v` (cible `test-fat-alloc`, ajoutée à
  `TESTS`) : 3 allocations chaînées ; la **persistance de l'EOC** est prouvée
  (l'alloc #2 renvoie `c1+1`, pas `c1`) et `tools/check_fat_alloc.py` valide la
  chaîne FAT (`FAT[c1]=c2`, `FAT[c2]=c3`, `FAT[c3]=EOC`, `c1` = 1re libre) sur
  l'image écrite. `tools/gen_fat_test.py` : bouche les trous FAT des entrées
  factices → 1er cluster libre > 128, ce qui exerce le scan multi-secteur (sans
  effet sur les autres bancs). `top_ulx3s` : allocateur câblé en tie-off (pas
  encore piloté). **Suite complète sans régression.**
- **US2.3 — LEDs d'activité (IRQ, VSYNC, USB)** (bmarty, 2026-08-23, **sim +
  synthèse OK, validation carte à faire**) : `rtl/led_activity.v` — monostable
  re-déclenchable générique (paramètre `WIDTH`) : chaque impulsion/niveau haut
  sur `trig` recharge un compteur qui décroît ensuite ; la LED reste allumée
  ~2^WIDTH cycles après le **dernier** événement (WIDTH=22 @ 25 MHz ≈ 168 ms).
  `top_ulx3s` instancie trois monostables sur `clk_sys` : **IRQ** (`irq_dbg`) et
  **VSYNC** (`frame_tick`, 50 Hz) restent allumés en continu tant que le cœur
  tourne = *heartbeat « il vit »* ; l'**USB** flashe à chaque rapport HID
  (`usb_report`, resynchronisé du domaine `clk_usb` 12 MHz par double bascule —
  largeur ≥ 2 `clk_sys`, aucune perte). Affichage **opt-in** via **SW4**
  (`sw[3]`, resynchronisé) : haut → vue activité sur les LEDs hautes
  (`led[7]=IRQ`, `led[6]=VSYNC`, `led[5]=USB`) ; bas → la vue diagnostic
  SD/FAT/sélection existante est **inchangée** (zéro régression fonctionnelle).
  Nouveau `sim/tb_led_activity.v` (cible `test-led`, ajoutée à `TESTS`) :
  WIDTH=4 réduit, vérifie allumage immédiat, durée de vie ~2^WIDTH, maintien
  sous train d'impulsions (retriggerable) et extinction au reset. **Suite
  complète + synthèse 85F sans régression.**
- **Audio jack — noise-shaper sigma-delta (qualité AY)** (bmarty, 2026-08-20,
  **sim + synthèse OK**) : le son AY était déjà présent sur le jack 3.5 mm mais
  **tronqué à 4 bits** (`audio_mix[9:6]`, 16 niveaux). `rtl/audio_dac_sd.v` —
  noise-shaper sigma-delta du 1er ordre **suréchantillonné à 25 MHz** : les
  6 bits de poids faible du mix 10 bits sont accumulés et reportés (carry) dans
  le LSB du code 4 bits, si bien que la **moyenne temporelle** de la sortie suit
  la valeur 10 bits complète (résolution effective ~10 bits, bruit de
  quantification hors bande). Modulateur borné (accumulateur 6 bits) : pas
  d'emballement, saturation propre à pleine échelle (`in≥960`). `top_ulx3s`
  interpose le module entre `audio_mix` et `audio_l/r`. Nouveau
  `sim/tb_audio_dac_sd.v` (cible `test-audio-dac`) : pour 7 niveaux DC, la
  moyenne·64 == entrée (à ~1 LSB), sortie bornée ≤15. **Suite + synthèse sans
  régression.**
- **US3.3 — Joystick USB → interface IJK Oric** (bmarty, 2026-08-20, **sim +
  synthèse OK, validation carte à faire**) : `rtl/joystick_ijk.v` — portage RTL
  de `oric_joystick_port_a_pins()` (réf. `~/Oric1/src/io/joystick.c`) : l'IJK vit
  sur le port imprimante = **VIA Port A**, activé quand PB4 (strobe) est piloté
  bas (`~pb_out[4]`), stick sélectionné par les bits 6-7 de `pa_out`
  (`ora|~ddra`), état actif bas sur bits 0-4 (RIGHT/LEFT/FIRE/DOWN/UP), présence
  bit 5. Sortie `pins` combinée par **ET** dans `via_pa_in` (pull-downs à
  collecteur ouvert ; 0xFF = neutre hors lecture joystick). Le core USB HID
  décodait déjà le gamepad (`game_u/d/l/r`, `game_a/b`) : `top_ulx3s` câble ces
  sorties, dérive `fire = A|B` et `present = (typ==3)`, les synchronise
  (12→24 MHz) et les passe à `oric_atmos` qui instancie l'IJK. Nouveau
  `sim/tb_joystick_ijk.v` (cible `test-joystick`, ajoutée à `TESTS`) : 9 vecteurs
  vérifiés contre la référence (absence, activation PB4, sélection, chaque
  direction/fire, tout appuyé). `test-boot` inchangé (overlay neutre au repos).
  **Suite complète + synthèse 85F sans régression.**
- **US-CSAVE.3 refinement — Taille réelle dans l'entrée de répertoire**
  (bmarty, 2026-08-20, **sim validée e2e + synthèse OK**) : `rtl/fat32.v` gagne
  une primitive `dsize_*` — **RMW du secteur de répertoire** : lecture du secteur
  dans `secbuf`, substitution du champ taille (octets 28-31 de l'entrée) par
  `dsize_val`, réécriture (CMD24) ; `wr_data` muxé (`secbuf` en écriture dir,
  sinon passthrough `wblk_data`). Le parsing mémorise désormais la **localisation
  de l'entrée** de chaque fichier (secteur `dsec_mem` + offset `doff_mem`).
  `rtl/top_ulx3s.v` : à la fin d'une sauvegarde réussie (`sav_done` & `sav_found`),
  la taille réelle (`sav_nbytes`) est inscrite dans l'entrée de `SAVE.TAP` — le
  fichier ne conserve plus sa taille placeholder. `tb_tape_saver` étendu (clôture
  de la lecture de contrôle, `dsize` → `q_size`=604) + **post-check
  `tools/check_save_tap.py`** qui relit l'image FAT : entrée `SAVE.TAP` taille=604
  et 1er octet de données `0x16` (placeholder `0xEE` bien écrasé). **Suite
  complète 29/29 PASSED, synthèse 85F sans erreur ni double-driver. US-CSAVE.3
  est complète** (reste la validation carte). Bug corrigé au passage : la maj
  n'est possible que fat32 en `S_DONE` — le banc clôt d'abord la lecture par
  `open_abort`.
- **US-CSAVE.3 phase B — Intégration top de la sauvegarde SD** (bmarty,
  2026-08-20, **synthèse OK, validation carte à faire**) : `rtl/fat32.v` gagne
  un **4ᵉ port de nom** (`q4_idx`/`q4_name`, lecture combinatoire de `name_mem`)
  pour localiser un fichier par son nom. `rtl/top_ulx3s.v` : **locator FSM** qui,
  après le parsing (`fat_done`), balaie le listing via `q4` et verrouille
  l'index du fichier `« SAVE    TAP »` (`sav_found`/`sav_file_idx`, domaine
  `rst_por` → survit aux resets CPU comme le listing) ; instance `tape_saver`
  alimentée par le démodulateur (`sav_byte`/`sav_valid`/`sav_capturing`) et
  autorisée par `sav_found` ; **mux `fat32.wblk`** arbitrant la source d'écriture
  entre le write-back disque (`dsk_track`) et le saver selon `sav_busy` (disque
  et cassette-save mutuellement exclusifs ; retours `wblk_pos/done/error`
  partagés). `tape_saver.v` ajouté aux sources de synthèse. Si `SAVE.TAP` est
  absent, `sav_found=0` inhibe la save SD sans gêner la voie UART (US-CSAVE.2).
  **Synthèse 85F sans erreur, ni double-driver, ni signal non piloté** ;
  `test-tape-saver` + suite complète sans régression. **Reste : validation carte**
  (`CSAVE"NOM"` réel → `SAVE.TAP` mis à jour) et le refinement « taille dans
  l'entrée de répertoire ».
- **US-CSAVE.3 phase A — Sauvegarde cassette vers la carte SD (module +
  chaîne sim)** (bmarty, 2026-08-20, **sim validée e2e**) : `rtl/tape_saver.v`
  — consomme les octets `.tap` de `tape_demod` et les écrit dans un fichier
  placeholder **pré-existant** `SAVE.TAP` via le chemin `fat32.wblk` déjà
  validé (US-DISK.5 : suit la chaîne de clusters + CMD24). **Double buffer
  ping-pong** (bufA/bufB de 512 o) : on écrit le buffer plein pendant que
  l'autre se remplit — la cadence bande (~137 o/s) étant très inférieure à une
  écriture SPI, aucun octet n'est perdu. Dernier bloc partiel complété par des
  `0x00` ; `nbytes` donne la taille réelle. `tools/gen_fat_test.py` : ajout d'un
  placeholder `SAVE.TAP` (8 clusters = 4096 o, rempli `0xEE`). Nouveau
  `sim/tb_tape_saver.v` (cible `test-tape-saver`) : chaîne complète
  `tape_injector → tape_demod → tape_saver → fat32.wblk → sd_card_file`, joue une
  charge de 600 o (> 512 → 2 blocs, exerce le ping-pong), relit `SAVE.TAP` →
  amorce + données correctes, padding `0x00` en fin de bloc (604 o sauvegardés).
  `test-fat32`/`test-dsk` : assertion `file_count` 7→8 (SAVE.TAP ajouté à
  l'image partagée). **`test-tape-saver` PASSED ; suite complète 29/29, zéro
  régression.** Reste **US-CSAVE.3 phase B** (intégration top : localiser
  SAVE.TAP par son nom, arbitrer `fat32.wblk` disque↔saver, déclencheur) et la
  mise à jour de la taille dans l'entrée de répertoire (refinement).
- **US-CSAVE.2 — Sortie SAVE vers le PC (câblage top + `recv_tap.py`)** (bmarty,
  2026-08-20, **synthèse OK, validation carte à faire**) : `rtl/top_ulx3s.v` —
  `tape_out` (PB7) passe désormais par un wire nommé alimentant à la fois la
  broche d'extension `gp[14]` et une instance `tape_demod`. Les octets `.tap`
  reconstruits sont injectés dans le **mux UART FTDI** avec priorité
  **dump > SAVE > écran > crédits** ; `sav_capturing` coupe le streamer écran et
  donne la main à la voie SAVE (débit bande ~137 o/s << UART 115200 → le pulse
  `byte_valid` pilote directement `uart_tx`, jamais occupé). `tape_demod.v`
  ajouté aux sources de synthèse. Nouveau `tools/recv_tap.py` : se
  **resynchronise sur l'amorce `0x16…0x24`** (écarte tout octet écran parasite
  reçu avant la sauvegarde), parse la structure des blocs (en-tête 9 o →
  adresses fin/début → nom → `fin-début+1` octets, **même logique que le parseur
  de `tape_injector.v`**) pour connaître la fin exacte, écrit le `.tap` après un
  silence. **Synthèse 85F sans erreur ni double-driver** ; parseur `recv_tap`
  validé sur flux synthétique (bruit + 2 blocs → reconstruits à l'octet près) ;
  `test-tape-demod` + suite sans régression. Utilisation : `recv_tap.py sortie.tap`
  puis `CSAVE"NOM"` sur l'Oric. **Reste : valider sur carte** (`CSAVE` réel →
  `.tap` relisible), puis US-CSAVE.3 (écriture sur SD).
- **US-CSAVE.1 — Démodulateur cassette (CSAVE) RTL** (bmarty, 2026-08-20,
  **sim validée**) : `rtl/tape_demod.v` — miroir de `tape_injector.v` et portage
  RTL du décodeur de référence `~/Oric1/src/io/cassette.c` (`tape_capture_*`).
  Échantillonne `tape_out` (PB7, bit-bangé par la ROM `CSAVE` via Timer 1),
  **ne compte que les fronts montants**, mesure la période front-à-front
  (2·HALF_ONE = '1' court / HALF_ONE+HALF_LONG = '0' long), applique le **seuil
  512 µs** (`CYC_THRESH`, défaut 12800 cy à 25 MHz) → bit. Réassembleur d'octet
  **sans trame de longueur fixe** (comme `GetTapeByte` $E6C9) : chasse le start
  (saute les stops '1', le 1er '0' long est le start), 8 bits data LSB d'abord,
  **brûle une période** (parité, valeur ignorée), rechasse — évite le décalage
  de framing d'un bit/trame. Sorties `byte_out`/`byte_valid` (pulse) et
  `capturing` (retombe après `GAP_CYCLES` de silence → fin de sauvegarde).
  Nouveau `sim/tb_tape_demod.v` (+ cible `test-tape-demod`, ajoutée à `TESTS`) :
  **boucle `tape_injector` → `tape_demod`** (la modulation est déjà validée sur
  carte contre la vraie ROM CLOAD), vérifie octets décodés == amorce 0x16 +
  données, sur flux simple ET multi-blocs (amorce inter-blocs). **`test-tape-demod`
  PASSED du premier coup**, suite complète sans régression. Reste US-CSAVE.2
  (câblage top + sortie UART vers PC / `recv_tap.py`) puis US-CSAVE.3 (écriture
  `.tap` sur carte SD).
- **US-DISK.6 — Formatage disquette : commande Write Track du WD1793** (bmarty,
  2026-08-17, **sim validée**) : `rtl/wd1793.v` — la commande `0xF0` (jusque-là
  « write protect ») implémente le **parseur du flux IBM/MFM** de formatage
  (modèle `~/Oric1/src/storage/disk.c`) : marque `FE` → champ ID de 4 octets
  (dont le n° de secteur), marque `FB`/`F8` → champ data de 256 octets poussé
  dans `tbuf` via `sec_we` (au secteur nommé par le dernier ID) ; gaps et octets
  de contrôle CRC (`F5/F6/F7/4E`) ignorés (layout seul). **Write-back par
  secteur** réutilisant la chaîne RMW des phases 3/4 (`wr_commit` → attente
  `wr_ok`), fin de commande quand les `n_spt` secteurs de la piste sont écrits.
  Nouveaux ops `OP_WR_TRK`/`OP_WR_TRK_WB` ; même correctif anti-course
  `cur_offset` (incrément à l'échéance DRQ) que la phase 4. `tb_wd1793` étendu :
  génère un flux MFM de 17 secteurs, capture par secteur, vérifie le motif
  écrit → **`test-wd` PASSED** ; `test-dsk-wr-e2e`/`test-boot`/`test-microdisc`
  **sans régression**. Autorise un `INIT`/formatage Sedoric sur une piste déjà
  cataloguée. (Read Track reste non implémenté — usage marginal.)
- **US-DISK.5 phase 4 — commande Write Sector du WD1793 (écriture disquette
  bout-en-bout)** (bmarty, 2026-08-17, **e2e sim validé**) : `rtl/wd1793.v`
  (commande `0xA0` : DRQ → réception de 256 octets → `sec_we`/`sec_wr_data` vers
  `dsk_track`, `wr_commit` en fin → attente `wr_ok`/`wr_err` ; write-protect
  retiré ; `currentop` élargi à 3 bits, ops `OP_WR_SEC`/`OP_WR_WB`),
  `rtl/dsk_track.v` (`wr_ok`/`wr_err` passés en **niveaux** pour un
  échantillonnage fiable côté WD1793 en domaine `cen`), et **câblage top complet**
  du chemin d'écriture : `wd1793` → `microdisc` → `oric_atmos` → `dsk_track` →
  `fat32.wblk` (tie-offs supprimés). Bug corrigé : décalage d'un octet
  (l'incrément de `cur_offset` était concurrent du pulse `sec_we` large ; déplacé
  à l'assertion du DRQ suivant). Nouveau `sim/tb_dsk_wr_e2e.v` (+ cible
  `test-dsk-wr-e2e`) : chaîne Microdisc+WD1793+dsk_track+fat32+SD, écrit le
  secteur 1 par la commande WD1793, relit → nouveau motif, secteur 2 intact.
  `tb_wd1793` mis à jour (le Write Sector n'est plus « write protect » : écrit
  256 octets vérifiés). **`test-dsk-wr-e2e`, `test-wd` PASSED ;
  `test-boot`/`test-dsk`/`test-microdisc`/`test-dsk-write` sans régression.**
  **US-DISK.5 (écriture disquette) est complète** — un `SAVE` Sedoric a désormais
  tout le chemin RTL (validation carte à faire).
- **US-DISK.5 phase 3 — write-back disquette (RMW) dans `dsk_track`** (bmarty,
  2026-08-17, **sim validée**) : `rtl/dsk_track.v` + `sim/tb_dsk_write.v` + cible
  `test-dsk-write`. Nouveau chemin d'écriture : `sec_we`/`sec_wr_data` poussent
  les octets du secteur dans le buffer de piste (`tbuf`), puis `wr_commit`
  déclenche une **FSM read-modify-write** — pour chacun des 1-2 blocs SD de 512 o
  couvrant le secteur : lecture du bloc (fat32) → overlay des octets du secteur
  (depuis `tbuf`) → réécriture (`fat32.wblk`). Overlay **déterministe** via
  `ocnt0` (octets du secteur dans le 1er bloc), 3 phases par octet pour la
  latence BRAM. `wr_busy`/`wr_ok`/`wr_err` pilotent le WD1793 (phase 4 à venir).
  **2 bugs corrigés au debug** : (1) `ocnt0[12:0]` sur un reg 10 bits → `x` sur le
  2e bloc ; (2) `wblk_data` registré → latence 1-cycle → `sd_spi` latchait
  l'octet précédent au streaming → source rendue **combinatoire** (comme
  `tb_fat_write`). **`test-dsk-write`** (écrit un secteur, recharge depuis la SD,
  vérifie nouvelle donnée + secteur voisin intact) et **`test-dsk`** (lecture,
  zéro régression) **PASSED**. Reste US-DISK.5 phase 4 (commande write sector
  WD1793 + câblage top WD1793↔dsk_track↔fat32.wblk).

### Décision
- **Retour à l'Atmos pur — tangentes Telestrat/ORIX/LOCI parquées** (bmarty,
  2026-08-17) : après une session d'exploration large (émulation LOCI, soft-core
  loci-fw, banking Telestrat, cible ORIX, CH376, comparaison LOCI/CH376), décision
  de **recentrer sur l'Atmos fidèle qui marche** et d'arrêter d'élargir. Les
  épopées **LOCI**, **LOCI-SOC** et le sous-chantier **MULTIBANK** sont **PARQUÉS**
  dans `docs/BACKLOG.md` (exploration conservée, non reprise). **Aucun revert** :
  le RTL multibank livré (bank_window, VIA-2 `$0320`, telestrat_mode, contrôleur
  SDRAM) reste en place mais **dormant et rétro-compatible** — `telestrat_mode`=0,
  VIA-2 inactif tant que non écrit → l'Atmos boote comme avant (`test-boot` vert).
  Les docs de conception (`LOCI_EMULATION`, `LOCI_SOC`, `MULTIBANK`,
  `MULTIBANK_SDRAM`) restent comme trace des études.

### Ajouté
- **US-MBANK.3 — Mode boot Telestrat + affinage sélecteur de banque** (bmarty,
  2026-08-17, **sim validée**) : `rtl/oric_atmos.v` — nouvel input
  **`telestrat_mode`** (0 = Atmos/boot BASIC bank0 ; 1 = Telestrat/boot TELEMON
  bank7), câblé `1'b0` dans `top_ulx3s.v` (Atmos par défaut, zéro régression).
  Sélecteur `bank_sel` affiné : **gate par DDRA** du 2e VIA — dès que le port A
  est piloté (DDRA≠0) la banque en vient (**banque 0 désormais sélectionnable**,
  l'ambiguïté « via2_bank=0 » de US-MBANK.2 est levée) ; sinon défaut =
  **banque 7 (TELEMON, vecteur reset)** en mode Telestrat, ou chemin BTN5
  (BASIC 1.1b/1.0) en Atmos. `sim/tb_bank_sel.v` étendu (gate DDRA, défaut
  bank7, masquage PA0-2) **PASSED** ; **`test-boot` PASSED** (zéro régression) ;
  les 5 testbenches cœur (`tb_boot`/`tb_sedboot`/`tb_trace`/`tb_cload`/
  `tb_cload_sd`) câblent `telestrat_mode(1'b0)`. Reste **US-MBANK.3b** : charger
  les 7 ROM ORIX en banques BRAM (les 177/208 EBR mesurés le permettent).

### Modifié
- **Plan MULTIBANK révisé par une mesure — banques ORIX en BRAM, DMA abandonné**
  (bmarty, 2026-08-17) : synthèse yosys du design complet → **121/208 EBR
  occupés** (87 libres). Une banque ROM 16 Ko = 8 EBR, donc 7 banques ORIX =
  56 EBR → **177/208, ça TIENT en BRAM**. Corrige l'hypothèse non mesurée de
  US-MBANK.4a (« 112 Ko trop juste → SDRAM »). Conséquence : **toutes les banques
  ORIX vont en BRAM** (switch instantané, fidèle aux trampolines TELEMON) ;
  l'architecture « banque active + DMA refill » (US-MBANK.4c) est **ABANDONNÉE**
  (son switch en ~ms cassait les trampolines) ; `bank_backing.v` non écrit. Le
  contrôleur SDRAM (4b) reste pour la **RAM haute**, hors chemin critique ORIX.
  Vrai prochain pas : `bank_window` à 8 banques BRAM + ROM ORIX (MBANK.3).
  Doc mis à jour : `docs/MULTIBANK_SDRAM.md` §2bis.

### Ajouté
- **US-MBANK.4b — Portage du contrôleur SDRAM (bring-up sim)** (bmarty,
  2026-08-17, **sim validée**) : `rtl/sdram_ctrl.v` + `sim/sdram_model.v` +
  `sim/tb_sdram.v` importés d'`~/oric2/hdl` (EUPL-1.2, auteur bmarty, en-têtes
  conservés) + cible `test-sdram`. Contrôleur SDR JEDEC closed-page, 16-bit,
  25-bit adresse (32 Mo). **`test-sdram` PASSED** : init JEDEC (PRECHARGE ALL →
  2× AUTO_REFRESH → LOAD MODE), écriture/relecture de 4 mots sur 2 lignes
  (exerce ACTIVE), persistance après ≥1 auto-refresh (refresh=5), **0 violation**
  READ/WRITE-sans-ACTIVE. Hors bus Oric — c'est le spike dé-risquant qui prouve
  que le contrôleur fonctionne dans `ulx3s_oric` avant d'y accrocher les banques.
  **Reste (sur carte, non simulable)** : `sdram_clk` (F19) + PLL + brochage dans
  `top_ulx3s.v`. Note licence : ces 3 fichiers sont **EUPL-1.2** (mixage assumé).
- **US-MBANK.4a — Investigation budget SDRAM pour les banques ORIX** (bmarty,
  2026-08-17, conception) : `docs/MULTIBANK_SDRAM.md`. Déclenchée par la cible
  **ORIX** (= TELEMON 3.0, **7 banques ROM** `orixbank1..7.rom` dans
  `~/oricutron/roms/`, boot bank 7, stockage **CH376**). 112 Ko de banques ne
  tiennent pas en BRAM → **SDRAM**. Actif réutilisable identifié : `sdram_ctrl.v`
  d'`~/oric2/hdl` (contrôleur SDR JEDEC 16-bit, 32 Mo, EUPL, auteur bmarty, même
  carte) + arbitre + `ulx3s_sdram.lpf`. **Décision d'architecture** : NE PAS lire
  les banques en SDRAM au fil de l'eau (latence variable + refresh vs bus 1 MHz,
  risque de rater l'échantillon t4) mais **banque active de 16 Ko en BRAM adossée
  à la SDRAM, re-remplie par DMA au changement de banque** (modèle `oric_bankN`
  du firmware LOCI). Sous-jalons US-MBANK.4a→d définis. Risques ouverts listés
  (fréquence de swap TELEMON, collision refresh, coexistence horloges HDMI/SDRAM,
  mixage licence EUPL). **Aucun RTL SDRAM ajouté** — investigation seule.
- **US-MBANK.2 — 2ᵉ VIA `$0320` pilotant la banque `$C000` (voie Telestrat)**
  (bmarty, 2026-08-17, **sim validée**) : `rtl/oric_atmos.v` — un `via6522` est
  réinstancié à **`$0320-$032F`** (`sel_via2`, décodage `$03xx` mis à jour :
  retiré de `sel_ext`, ajouté au multiplexeur `cpu_di`). Le **port A** de ce VIA
  (bits de sortie `PA0-2 & DDRA`) devient le **registre de banque** :
  `bank_sel = (via2_bank != 0) ? via2_bank : {2'b0, rom_bank}` — un logiciel
  Telestrat sélectionne la banque `$C000` en écrivant le port A, avec **repli sur
  le BTN5** (BASIC 1.1b↔1.0) validé sur carte quand aucune banque n'est
  sélectionnée (au reset DDRA=0 → repli → **boot inchangé**). IRQ du 2ᵉ VIA **non
  câblée** (banking seul ; IER=0 au reset → pas d'IRQ parasite). Nouveau
  `sim/tb_bank_sel.v` + cible `test-bank-sel` : vérifie écriture DDRA/ORA →
  banques 1..7, masquage PA0-2, et repli BTN5. **Zéro régression prouvée** :
  `test-bank-sel` ET `test-boot` (boot BASIC complet) **PASSED**. Suite :
  numérotation Telestrat fidèle (bank0=RAM overlay, bank7=TELEMON) + ROM réelles
  (US-MBANK.3).
- **US-MBANK.1 — `bank_window.v` : fenêtre multibank $C000 (voie Telestrat)**
  (bmarty, 2026-08-17, **sim validée**) : `rtl/bank_window.v` + `sim/tb_bank_window.v`
  + cible `test-bank`. Généralise `oric_rom.v` (2 banques figées) vers **8 banques
  logiques à rôle** (2 bits/banque : 0=non peuplée→$FF, 1=ROM A, 2=ROM B, 3=RAM
  servie par l'overlay externe), avec sortie **`bank_is_ram`** (crochet pour router
  les futures banques RAM vers l'overlay `oric_ram`+`rom_as_ram` existant, US-MBANK.4).
  Intégré dans `oric_atmos.v` en remplacement de `oric_rom` avec
  `bank_sel={2'b0,rom_bank}` → comportement **strictement identique** (bank0=BASIC
  1.1b, bank1=1.0). **Zéro régression prouvée** : `test-bank` (défaut + remapping
  des rôles + `bank_is_ram`) et `test-boot` (boot BASIC complet du cœur, bannière
  détectée) tous deux **PASSED**. Écart assumé vs conception (`docs/MULTIBANK.md`
  §2) : l'overlay write et `/MAP` **restent** gérés par la RAM 64 Ko existante
  (non dupliqués dans le module) — c'est ce qui garantit la non-régression.
  `oric_rom.v` conservé mais retiré des listes de build (rollback). Suite : 2e VIA
  `$0320` pilotant `bank_sel` (US-MBANK.2). **Makefile** : `oric_rom.v`→`bank_window.v`
  dans `RTL`/`SIM_CORE`, `test-bank` ajouté à `TESTS`.
- **US-MBANK.0 — Conception multibank « voie Telestrat fidèle »** (bmarty,
  2026-08-17) : `docs/MULTIBANK.md` + sous-chantier MULTIBANK sous l'épopée
  ULA-NG dans `docs/BACKLOG.md`. Décision prise avec bmarty : le banking mémoire
  est spécifié **Telestrat-fidèle**, après vérification web (spec faisant autorité
  cc65/OSDK + **état de l'art 2026** : core FPGA **BigMist/Oric_Telestrat**
  GPL-2.0, core MiSTer, OS **ORIX v2025.3**). Spec confirmée : fenêtre `$C000`
  = **8 banques** hétérogènes ROM/RAM, sélecteur = **3 bits PA0-2 d'un 2ᵉ VIA à
  `$0320`** (le `NG_BANK $03E0` de US-ULA-NG.1 devient un alias optionnel),
  **bank 0 = overlay RAM** (STRATSED), **bank 7 = TELEMON** (boot, vecteur reset) ;
  écritures `$C000` → toujours overlay RAM. Réponse tranchée à « si ROM alors RAM
  aussi ? » = **OUI** (la RAM est des banques comme les ROM ; BigMist embarque
  128 Ko RAM). Conception d'un `bank_window.v` **unifié** (banques ROM/RAM +
  overlay + `/MAP`) remplaçant `oric_rom.v`, avec réserve **budget BRAM/SDRAM**
  (128 Ko bankés probablement trop justes en EBR seule → banques RAM en SDRAM à
  chiffrer). Approche **clean-room** (spec, pas le code GPL BigMist). 6 jalons
  US-MBANK.0→5. **Aucun code produit** — conception seule.
- **US-LOCI-SOC.0 — Conception SoC : soft-core RISC-V exécutant loci-fw**
  (bmarty, 2026-08-17) : `docs/LOCI_SOC.md` + épopée LOCI-SOC dans
  `docs/BACKLOG.md`. Périmètre décidé avec bmarty : voie **soft-core + firmware**,
  fidélité maximale. Recherche factuelle : **aucun portage RP6502/RP2040→FPGA
  n'existe** (*from scratch*) ; **Cortex-M0 open-source sur ECP5 = expérimental**
  (netlist DesignStart obfusqué) → on part sur **RISC-V (VexRiscv/LiteX**, cible
  ULX3S clé en main). Constat honnête : « exécuter `loci-fw` tel quel » n'est pas
  atteignable — la voie RISC-V impose de **recompiler** et de **réécrire le HAL
  RP2040** (PIO/DMA/dual-core/USB host/XIP) ; or PIO-bus et WD1793 sont
  **redondants** avec le natif `ulx3s_oric`. Architecture retenue : SoC
  LiteX/VexRiscv gardant la **logique applicative** (MIA/API POSIX, `fatfs`, menu)
  branchée sur le bus 6502 natif + `sd_spi.v`, via un **« MIA bridge »** RTL
  (`$03A0-$03BF`). **Seul vrai mur : l'USB host du modem CDC** (repli v0 =
  UART/ESP32 déjà présent). Plan dé-risqué en 7 jalons (spike VexRiscv →
  SDRAM/SD → coexistence → MIA bridge → portage → modem → validation), avec
  critère d'arrêt (repli sur le MIA RTL pur de `LOCI_EMULATION.md` si la
  coexistence ne tient pas sur la 85F). **Aucun code produit** — conception seule.
- **US-LOCI.0 — Conception de l'émulation LOCI interne** (bmarty, 2026-08-17) :
  `docs/LOCI_EMULATION.md` + nouvelle épopée LOCI dans `docs/BACKLOG.md`.
  Analyse factuelle des sources réelles (`loci-hardware` 1.3, `loci-fw`,
  ROM menu, code client `bbsoric`/`scum`) via 3 explorations parallèles.
  **Décision de périmètre** : la LOCI est un **RP2040 + firmware** ; son cœur
  (MIA `$03A0`, API POSIX open/read/write/mount/boot, ROM swap `$C000`) est
  **logiciel** — non émulable en RTL pur et **redondant** avec la chaîne disque
  native déjà validée (sd_spi→fat32→dsk_track→wd1793→microdisc, boot Sedoric OK).
  Seule brique retenue comme émulable ET distincte de l'existant :
  l'**ACIA 6551 à `$0380`** (canal modem LOCI), face au 6551 existant à `$031C`.
  Soft-CPU exécutant `loci-fw` **écarté** (projet en soi). Backlog : US-LOCI.1
  (décision 2ᵉ 6551 vs commutable) → US-LOCI.4 (validation carte). **Aucun RTL
  produit** — conception seule, à valider avant codage.
- **Note à l'équipe — liaison physique vers la LOCI + berceau PCBA**
  (bmarty, 2026-08-13) : `docs/NOTE_EQUIPE_LIAISON_LOCI.md`. Revue croisée avec
  l'étude indépendante `~/NetMaze/ulx3s2Loci/` : **validation mutuelle** du
  brochage 34 points (reconstruit du schéma réel LOCI 1.3), du choix 74LVC
  (TXS0108E proscrit) et du piège `/OE=/IO` (ROM menu `$C000–$FFFF`). Apport d'un
  **berceau PCBA** (l'ULX3S s'enfiche, entraxe J1/J2 = **88,90 mm** relevé du
  `.kicad_pcb`, 2× 74LVC4245A). **2 points signalés** : `gp/gn[16]` (XCVR_DIR//OE)
  tombent dans la zone ADC « évitée » (N16/M17 = AIN5/AIN4) ; commentaire
  « TXS0108E » obsolète dans l'en-tête de `rtl/expansion_port.v`. Mapping du berceau
  à aligner sur `top_ulx3s.v` (référence).
- **Modem WiFi Hayes sur l'ESP32 interne — INSTALLÉ ET FONCTIONNEL**
  (bmarty, 2026-08-13) : `firmware/esp32_modem/main.py` (MicroPython,
  jeu de commandes COMPATIBLE PicoWiFiModemUSB de ~/picowifi : AT$SSID=,
  AT$PASS=, ATC1, AT&W, ATDT host[:port], +++/ATO/ATH, ATGET http(s),
  ATI, ATZ), installé par le raw-REPL (`tools/esp32/install_main.py`,
  aucun flash esptool), persistant (main.py + wifi.txt dans la flash de
  l'ESP32). Testé via le passthru : AT→OK, ATI→bannière, AT?→aide.
  Reste : config WiFi réelle (AT$SSID/AT$PASS/ATC1/AT&W) et terminal
  côté Oric via le 6551 $031C (US-MODEM.3).

### Ajouté
- **ESP32 interne : REPL MicroPython découvert fonctionnel** (bmarty,
  2026-08-13) : le firmware d'usine MicroPython 1.14 répond sur l'UART
  (115200, passthru officiel), `network.WLAN` opérationnel, flash 4 Mo,
  `boot.py` = stub par défaut. Le blocage « ESP32 non flashable » (GPIO0,
  2026-08-02) ne condamne que le remplacement du firmware par esptool —
  l'injection de code par le REPL (paste mode → `main.py` persistant)
  contourne tout : le modem WiFi (US-MODEM.2) redevient réalisable sans
  matériel externe, en MicroPython. Sondé par script série (tests :
  version, listdir, WLAN, boot.py lu avant toute modification).

### Ajouté
- **US-SD-SPEED : SPI rapide après init + seek FAT32 incrémental** (bmarty,
  2026-08-13, **VALIDÉ SUR CARTE** — boot Sedoric rapide, Citadelle OK,
  cassette/Atmos sans régression ; gravé en flash SPI avec l'OSD
  ouvert/fermé, le reset auto et les broches XCVR) : (1) `spi_byte.v`/`sd_spi.v` — l'init SD reste à ~390 kHz
  (norme), puis tous les transferts passent à `HALF_FAST` (6,25 MHz à
  25 MHz, ×16 — la FSM SPI exige une demi-période ≥ 2 cycles : mosi doit
  précéder le front montant de sck) dès `ready` ; la vitesse est figée au lancement de chaque
  octet (pas de glitch). (2) `fat32.v` — `cur_base` suit l'offset fichier
  du début du cluster courant ; une réouverture du même fichier à un offset
  en aval repart du cluster courant au lieu de re-suivre la chaîne depuis
  le début (chargements de pistes .dsk successives en O(1) ; un seek en
  amont re-parcourt — rare et désormais rapide). Cache invalidé au
  re-listing. Validation : suite complète + `tb_side1` byte-exact.

### Ajouté
- **US-DISK.4 : boot Sedoric VALIDÉ SUR CARTE + OSD ouvert/fermé + reset
  auto** (bmarty, 2026-08-13, « cela fonctionne » — menu Sedoric au boot) :
  `rtl/top_ulx3s.v` — (1) l'OSD a un état ouvert/fermé : BTN4 charge/insère
  ET ferme l'OSD ; fermé, BTN3/BTN4 ne font que le rouvrir. `Citadelle.dsk`
  validé aussi (choix du menu OK — l'« erreur de syntaxe » venait de la
  course de piste, les données servies étaient fausses). Motif : l'OSD
  restait affiché pendant le boot disquette et les appuis « pour fermer »
  lançaient un chargement cassette qui volait le bus SD (READ FAULT sur le
  répertoire) et enclenchait le turbo ×4 (touches répétées, curseur rapide).
  L'OSD ne se rouvre pas sur reset (pas de recouvrement du boot).
  (2) Insertion d'un .dsk = reset automatique : on attend le front de
  `dsk_inserted` (la disquette survit au soft reset) puis ~5 ms de reset —
  la machine reboote sur l'EPROM Microdisc qui trouve la disquette ; plus
  besoin de BTN1. Lenteur connue : chaque piste refait le seek FAT32 depuis
  le début du fichier à la vitesse SPI d'init → chantier « SPI haute
  vitesse » au backlog.

### Corrigé
- **Boot Sedoric : gel après la bannière (US-DISK.4) — deux causes racines**
  (bmarty, 2026-08-13, validé en sim `tb_sedboot` : la séquence FDC suit la
  référence sans divergence, plus de tempête d'IRQ ni de READ FAULT) :
  1. `rtl/oric_ram.v` : la BRAM démarrait toute à zéro ; or le boot Sedoric
     (`$B932`) checksomme la RAM haute `$C980-$FFFF` — tout-zéro est pris
     pour un boot à chaud → **mini-loader 4 secteurs** au lieu des 60 de
     SYSTEM.DOS → vecteur IRQ posé sur `$D0A5` vide → tempête BRK. La RAM
     est maintenant initialisée au motif Oricutron (rampattern=0) : par page
     de 256 octets, 128×`$00` puis 128×`$FF` (même init sim et synthèse).
  2. `rtl/dsk_track.v` : course seek/rechargement — un seek arrivant PENDANT
     un rechargement de piste (cas réel : le noyau écrit ctl side=1 puis
     seek 4 cycles plus tard) étiquetait le buffer avec la NOUVELLE cible
     (`loaded <= wanted` échantillonné en fin de scan) → piste 20 face 1
     servie comme « piste 13 face 1 », secteurs pleins d'espaces `$20` →
     « TRACK:20 SECTOR:20 READ FAULT ». La cible est maintenant capturée au
     début du chargement (`load_tgt`) : si la demande change en cours de
     route, le mismatch persiste et la bonne piste est rechargée aussitôt.
  Bancs : `sim/tb_side1.v` (diagnostic ciblé face 1, hors suite) ;
  `sim/tb_dsk.v` scénario 3 = non-régression de la course (deux seeks
  enchaînés sans attendre, la piste servie doit être celle du second).
  `tools/gen_sed_test.py` : SEDBOOT.DSK n'est plus tronqué à 62 pistes
  face 0 — le boot lit aussi la **face 1** (piste `$80|n` dans les messages
  d'erreur Sedoric), l'image embarque les 2 faces × 80 pistes.

### Ajouté
- **Deux banques ROM (US-ULA-NG.1, première tranche) — VALIDÉ SUR CARTE**
  (bmarty, 2026-08-11, **Citadel chargé jusqu'au « Choix des couleurs »**) :
  `rtl/oric_rom.v` héberge 2 banques de 16 Ko en BRAM — banque 0 = BASIC
  1.1b (défaut), banque 1 = **BASIC 1.0** (`roms/basic10.hex`, généré depuis
  la ROM de l'émulateur). **BTN5 (gauche)** bascule la banque et déclenche
  un reset (~5 ms) ; vérification de la banque active : `PRINT PEEK(#FFF9)`
  (1 = 1.1b). Décidé après le diagnostic Citadel : les jeux à loader protégé
  vérifient la révision exacte de la ROM et sautent dans ses entrailles —
  la 1.0 est un des deux chemins supportés par Citadel, et sur carte les
  4 blocs s'enchaînent grâce à l'amorce inter-blocs. Testbenches : `tb_boot`
  boote les deux banques (`+bank=1`). Limitation connue : la bascule fait
  un warm-boot silencieux (pas de bannière — la RAM n'est pas effacée) ;
  nettoyage de la signature à prévoir pour un vrai boot à froid.

### Ajouté
- **Interface Microdisc (US-DISK.2) — VALIDÉE SUR CARTE** (bmarty,
  2026-08-12 : SW1 ON → « insert system disc », SW1 OFF → Atmos intact) :
  `rtl/microdisc.v` fidèle à `~/Oric1/src/io/microdisc.c` — registres
  `$0310-$0313` (WD1793), `$0314` W = contrôle (b0 INTENA, b1 /ROMDIS,
  b4 side, b6:5 drive, b7 /EPROM), `$0314`/`$0318` R = /INTRQ//DRQ
  (bit 7 actif bas, b6:0 = 1), EPROM `microdis.rom` 8 Ko en overlay
  `$E000-$FFFF` ($C000-$DFFF = RAM overlay, sémantique /ROMDIS combinée
  avec le port d'extension), IRQ 6502 gouvernée par INTENA. Au boot :
  ROMDIS + EPROM actifs (la machine démarre sur l'EPROM, comme le vrai
  matériel). **SW1 (DIP) = interface « branchée »** — à OFF, l'Atmos est
  strictement inchangé (comme débrancher le Microdisc). Décodage
  `$0310-$031B` (l'ACIA garde `$031C-$031F`). Testbenches :
  `tb_microdisc` (registres, flags, EPROM, transparence) et `tb_boot
  +microdisc=1` — **la machine boote l'EPROM et affiche « insert system
  disc »** (pas encore de disquette : fournisseur de secteurs en bouchon
  jusqu'à US-DISK.3, pistes depuis la SD). 19/19 tests.
- **Cœur FDC WD1793 (US-DISK.1) — validé en simulation** (2026-08-12) :
  `rtl/wd1793.v`, fidèle à `~/Oric1/src/storage/disk.c` (modèle
  FDC_TIMING_REAL) : registres command/track/sector/data, type I
  (restore/seek/step, délais r1r0 6-30 ms + settling V 30 ms), type II
  (read sector simple/multiple, latence rotationnelle 300 RPM, DRQ par
  octet différé), type III (read address), type IV (force interrupt),
  status type I « vivant » (index pulse par tour, TRK0), RNF après
  5 tours d'index. **v1 lecture seule** (écritures → write protect,
  comportement disquette protégée). Interface fournisseur de secteurs
  (piste en BRAM + table d'IDs, à venir en US-DISK.3) avec gel des
  délais pendant un chargement SD (`trk_loading`). Testbench
  `tb_wd1793` (timings réduits) : 8 familles de scénarios. Épopée
  US-DISK démarrée : plan révisé source = carte SD (cf. backlog).
- **Mode turbo chargement (US-ULA-NG.8) — RÉSOLU, VALIDÉ SUR CARTE**
  (bmarty, 2026-08-12) : pendant un chargement cassette (`tape_active`),
  tout le domaine `cen1` (CPU+VIA+AY) passe de 1 MHz à ~4,17 MHz
  (`TURBO_DIV=6`, bascule à chaud sûre) et l'injecteur réduit ses
  demi-périodes du même ratio — chargement effectif ~3×, retour 1 MHz
  automatique dès la fin (y compris jeux autorun qui coupent le moteur).
  L'enquête (banc bout-en-bout `sim/tb_cload.v` : boot ROM réel + frappe
  `CLOAD""` + cassette, traces VIA/RAM, **désassemblage de GetTapeByte
  `$E6C9`**) a livré trois correctifs :
  1. **Stops supplémentaires** (trame 14→18 bits, données seulement) : la
     fenêtre inter-octets de la ROM (traitement + IRQ T1 100 Hz) dépassait
     les 4 stop bits → fronts manqués → raccrochage 2 bits trop tard
     (octet faux, signature `$41`→`$D0`) → « Errors found ». La ROM brûle
     un front puis saute les périodes courtes : des '1' en plus sont
     transparents. (Un gap silencieux ne convient PAS : son front terminal
     — le vrai start — se fait manger par le brûleur.) Course d'ailleurs
     LATENTE à 1 MHz (reproduite en tb), jamais vue sur carte avec les
     vrais jeux — comportement 1 MHz inchangé.
  2. **Phase vidéo dédiée `tphase_v`** (toujours 1 MHz) pour l'ULA et le
     port d'extension : sinon l'ULA ne voit plus les phases 6..24 en turbo
     → image figée (le chargement marchait, l'écran restait sur
     « Searching » — diagnostic décisif : reset → l'écran chargé apparaît).
  3. **Fin de bande moteur coupé** : les jeux autorun stoppent le moteur
     dès leur dernier octet lu ; l'injecteur conclut (S_DONE) s'il ne
     reste que des stop bits gelés — sinon `tape_active`/turbo/OSD
     restaient bloqués (jeu à 3×).
  Bancs : `tb_tape` scénarios turbo + moteur-coupé, `tb_cload`
  (`ALL TESTS PASSED turbo=1`, données `$0501-0504` exactes),
  `tb_cload_sd` (chaîne SD complète) disponible ; image de test
  `gen_fat_test.py` enrichie d'un `VALID.TAP`. 17/17 tests, timing 50 MHz.

### Corrigé
- **`.tap` multi-parties : amorce ré-insérée entre les blocs — VALIDÉ SUR
  CARTE** (bmarty, 2026-08-10, Defense Force — 4 blocs, 59 Ko — chargé et
  fonctionnel) : le format `.tap` ne conserve que ~3 octets de sync `0x16`
  entre les parties (la longue amorce de la vraie bande est supprimée). Or
  entre deux parties l'Oric traite le bloc chargé moteur actif : les ~20 ms
  de sync partaient dans le vide et le `CLOAD` suivant restait en
  « Searching... ». `rtl/tape_injector.v` parse désormais la structure des
  blocs (sync → `0x24` → en-tête 9 octets avec adresses fin/début → nom →
  données de fin−début+1 octets) et ré-insère `INTER_SYNCS` (255, ~1,8 s)
  trames d'amorce à chaque frontière de bloc — comme la vraie cassette.
  Sans risque : des `0x16` devant une amorce sont transparents pour la ROM,
  le parsing garantit de ne jamais insérer dans les données (structure
  vérifiée sur DEFENDER.TAP : les 4 frontières tombent exactement), pas
  d'insertion après le dernier octet, et un flux non conforme désactive
  simplement l'insertion. Testbench `tb_tape` : scénario multi-parties
  (2 blocs complets) — amorce initiale + bloc 1 + amorce inter-blocs +
  bloc 2 vérifiés trame par trame. Bénéficie aussi au chargement UART
  (`send_tap.py`), même injecteur.
- **Chargement `.tap` depuis la SD — bug résolu, VALIDÉ SUR CARTE**
  (bmarty, 2026-08-10, BREAKOUT chargé et fonctionnel) : le point ouvert
  des sessions précédentes était un défaut de protocole du flux fichier.
  `fat32` émettait un octet à CHAQUE cycle où `fdata_ready` était haut,
  or `tape_loader` tenait ce signal haut 2-3 cycles par crédit → 2-3
  octets partaient en rafale par crédit, le compteur de crédits passait
  en underflow 16 bits (65535 crédits fantômes) → plus aucun contrôle de
  flux → débordement de la FIFO 256 du `tape_injector` → données
  corrompues, l'Oric coupait le moteur. `fat_dump` avait le bug inverse
  (impulsion `fdata_ready` d'un cycle, perdue si `fat32` lisait le
  secteur suivant → blocage aux frontières de secteur).
  - Correctif : handshake **valid/ready** standard dans `rtl/fat32.v`
    (FO_EMIT : octet présenté, `fdata_valid` tenu jusqu'au cycle où
    valid ET ready sont hauts — exactement un octet par transfert),
    `rtl/tape_loader.v` (transfert compté une seule fois, décrément
    exact des crédits) et `rtl/fat_dump.v` (`ready` en niveau).
  - Testbench `tb_tape_loader` durci : crédits espacés + détection des
    rafales (espacement < DELAY = échec) et des octets excédentaires.
    Vérifié : l'ancien RTL échoue (« rafale, espacement 1 cycle »), le
    nouveau passe. Suite complète : 17/17 testbenches verts, timing OK.

### Documenté
- **US-ULA-NG.8 : mode turbo 6502** au backlog : registre NG_TURBO
  (fenêtre ULA-NG) commutant l'horloge CPU 1 MHz fidèle → 8/16 MHz+
  (BRAM sans wait state) ; VIA/AY/cassette restent au 1 MHz réel ;
  retour 1 MHz sur reset. Retenu comme alternative au 65C816 dans ce
  projet (le 65C816 = territoire du workspace séparé `~/oric2`).
- **US-ULA-NG.5 : architecture DOS/BASIC actée** (bmarty, 2026-08-10) :
  banque 0 (boot, vecteur reset) = DOS cc65 (SD/FAT32, menu, hooks) qui
  fait ensuite le handover vers la banque 1 = BASIC 1.1b patché. Le DOS
  reste appelable depuis le BASIC façon Sedoric : hooks vecteurs page 2 +
  résident RAM basse, commandes `!DIR`/`!LOAD`, commutation NG_BANK
  aller-retour, échanges par la RAM basse (< `$C000`).
- **US-ULA-NG : expérience utilisateur + VRAM dédiée** (décisions bmarty,
  2026-08-10) : boot 100 % classique ; la commande **`HIRES 1`** (BASIC
  étendu, ROM 1.1b patchée en banque de boot) bascule en mode OCULA/NG,
  `HIRES` sans argument inchangé. Les modes vidéo étendus utilisent une
  **VRAM à part** (BRAM séparée de la RAM 6502, accès par port indexé
  style VDP) — nouveaux incréments US-ULA-NG.6 (BASIC étendu) et
  US-ULA-NG.7 (VRAM + texte haute qualité 8×16/14×18 + hires 640×400).
- **Épopée US-SPEECH** au backlog : synthèse vocale **TMS5220** (le chip
  voix TI de l'Exelvision EXL 100) en RTL, réécrit d'après la référence
  MAME `tms5220.cpp` avec testbench de non-régression. Mode Speak External
  (données LPC streamées par le CPU, pas de ROM VSM), 2 registres page
  `$03xx`, sortie mixée avec l'AY (jack + HDMI). Outillage PC WAV→LPC et
  démo à venir ; exploité par notre propre soft (BASIC, puis ROM système).
- **Épopée US-ULA-NG « Oric 2 »** au backlog : banques mémoire pilotées par
  l'ULA (registre NG_BANK dans `$03E0-$03EF`, fenêtre 16 Ko à `$C000`
  commutée ROM/RAM, jusqu'à 64 Ko de ROM + 64 Ko de RAM) puis modes vidéo
  étendus de la spec ULA-NG de la référence `~/Oric1` (palette, texte
  80 colonnes, chunky 4bpp), et à terme une ROM système façon Orix (cc65).
  Compatibilité par défaut : comportement HCS10017 strict tant que le mode
  NG n'est pas déverrouillé, boot sur la banque BASIC.
- **Plan « Navigateur de fichiers WiFi »** (`docs/NETFS_WIFI.md`) + épopées
  US-NETFS et US-DISK au backlog : parcourir une arborescence de `.tap`/`.dsk`
  servie en HTTP (listing JSON) via WiFi, OSD incrusté par le FPGA, chargement
  `.tap` réutilisant l'injecteur cassette. `.dsk` (Microdisc WD1793) = épopée
  ultérieure. Partage le lien ESP32↔FPGA du plan modem.
- **Plan « Modem WiFi Oric »** (`docs/MODEM_WIFI.md`) + épopée US-MODEM au
  backlog : 6551 ACIA émulé (FPGA, `$031C-$031F`, fidèle à `acia6551.c`) relié
  au firmware Hayes/WiFi de l'ESP32 embarqué. 3 phases — cœur 6551 FPGA (RTL),
  firmware ESP32 (Zimodem, bmarty flashe), terminal Oric.

### Ajouté
- **Lecteur carte micro-SD (SPI) — épopée US-SDCARD (en cours)** : première
  étape vers le chargement de programmes depuis une carte SD (le lecteur SD de
  l'ULX3S, jusqu'ici inutilisé), alternative simple à l'USB Mass Storage —
  clavier branché en direct + stockage sur bus séparé.
  - **Incrément 1 — pilote SD**, **validé sur carte** :
    - `rtl/spi_byte.v` : moteur SPI mode 0 (octet full-duplex). Testbench
      `tb_spi_byte` (loopback).
    - `rtl/sd_spi.v` : FSM d'init (CMD0/CMD8/ACMD41/CMD58, détection SDHC via
      CCS) + lecture de secteur (CMD17). Octet `status` pour diagnostic LED.
    - `sim/sd_card_model.v` + `sim/tb_sd_spi.v` (`make test-sd`) : init complète
      + lecture secteur 0, motif + signature 0x55AA vérifiés en simulation.
    - Intégration `top_ulx3s` : broches `sd_clk`/`sd_cmd`/`sd_d` (SPI : mosi=cmd,
      miso=d0, cs=d3), test au boot lisant le secteur 0 → LEDs (`0xAA` = carte
      OK + signature valide). **Confirmé sur carte réelle par bmarty.**
  - **Incrément 2 — parseur FAT32**, **validé sur carte** :
    - `rtl/fat32.v` : lecture seule ; détecte table MBR *ou* superfloppy, lit le
      BPB, calcule les LBA, parcourt le répertoire racine, liste les `.TAP`/
      `.DSK` (ignore LFN/volume/dir + autres extensions). Listing exposé par
      port indexé (nom 8.3, cluster, taille, dsk?).
    - `sim/sd_card_file.v` (carte servie depuis une image) +
      `tools/gen_fat_test.py` (image FAT32 avec MBR) + `sim/tb_fat32.v`
      (`make test-fat`) : listing vérifié en simulation.
    - `top_ulx3s` : LEDs = nombre de `.tap`/`.dsk` trouvés. **Confirmé sur la
      carte réelle par bmarty** (les fichiers de la carte sont bien listés).
  - Suite : OSD à l'écran + navigation, chargement `.tap` via `tape_injector` ;
    `.dsk` = épopée US-DISK (émulation Microdisc).
- **Son sur HDMI — épopée US-HDMI-AUDIO (en cours)** : le son de l'Oric
  (AY-3-8912) ne sortait que sur le jack DAC 3,5 mm car la sortie GPDI est du
  **DVI pur** (vidéo seule). Objectif : transporter l'audio dans les *data
  islands* HDMI, en réécrivant en Verilog-2005 la logique standard (le module
  de référence `hdl-util/hdmi` est en SystemVerilog, incompatible en direct
  avec le flow yosys/iverilog du projet). Jack conservé en parallèle (aucune
  interaction avec l'entrée cassette, câblée sur `gp[14]`).
  - **Incrément 1 — encodeur TMDS 3-modes** (`rtl/hdmi_tmds_channel.v`) :
    control / video (8b/10b) / **data island TERC4** / guard bands vidéo et
    data-island, par canal (CN=0/1/2). Testbench `sim/tb_hdmi_tmds.v`
    (cible `make test-hdmi`) : **non-régression** stricte contre l'ancien
    `tmds_encoder.v` sur 512 cycles + vérification littérale des 16 codes
    TERC4, des guard bands et des codes de contrôle.
  - **Incrément 2 — packets audio** :
    - `rtl/hdmi_packet_assembler.v` : assemble un data island packet (header
      24 bits + 8 ECC, 4 subpackets 56 bits + 8 ECC) et le sérialise sur les
      32 pixels. ECC BCH par LFSR (polynôme 0x83). Testbench
      `sim/tb_hdmi_packet.v` (`make test-hdmi-packet`) : framing exact +
      **syndrome BCH nul** sur les mots reconstitués.
    - `rtl/hdmi_audio_packets.v` : contenu des packets Audio Clock
      Regeneration (N/CTS, N=4096 pour 32 kHz), Audio InfoFrame (LPCM 2 canaux,
      checksum), Audio Sample Packet (échantillon IEC60958 stéréo, preamble
      P/C/U/V, parité). Testbench `sim/tb_hdmi_audio.v`
      (`make test-hdmi-audio`) : headers, slices N/CTS, checksum nul, parité
      recalculée (1 et 2 échantillons).
  - **Incrément 3 — ordonnanceur + cadence audio** (`rtl/hdmi_data_island.v`) :
    place un data island par ligne dans le blanking (preamble + guard bands +
    island), plus video preamble/guard avant la reprise vidéo ; ordonnance
    InfoFrame (ligne 0), ACR (ligne 1) et Audio Sample Packets (autres lignes).
    Cadence audio 32 kHz exacte par accumulateur rationnel (pixel clock 25 MHz),
    jusqu'à 4 échantillons/packet (cadence ligne 31,25 kHz < 32 kHz). Testbench
    `sim/tb_hdmi_island.v` (`make test-hdmi-island`) : séquence complète des
    modes vérifiée pixel par pixel.
  - **Intégration** : `rtl/hdmi_out.v` passe de DVI pur à HDMI (3 canaux
    `hdmi_tmds_channel` + data islands) ; image inchangée sur écran DVI.
    `rtl/top_ulx3s.v` : audio PSG converti en PCM 16 bits signé, traversée de
    domaine clk_sys→clk_pixel, **jack 3.5 mm conservé** en parallèle.
  - **AVI InfoFrame** (`hdmi_audio_packets` type 0x82, ligne 2) : décrit la
    vidéo à l'écran passé en mode HDMI. **VIC=0** (format non-CEA) : sans lui
    (VIC=1) l'écran imposait le timing 25,175 MHz de la norme 640×480 et coupait
    l'image après ~30 s (on génère 25,000 MHz). **PB1 underscan (S=10)** :
    supprime le traitement d'image (halo/fantômes autour des glyphes) sans
    couper le son. NB : le bit `IT_CONTENT` (mode « PC ») supprime aussi le halo
    mais **coupe les haut-parleurs** de certaines TV — non retenu.
  - **Validé sur carte (ULX3S)** : image nette + audio HDMI dans le signal +
    stable, jack conservé. Cadence audio et compatibilité écran confirmées par
    bmarty. Flash en FLASH (`make oric-flash`) recommandé (le load SRAM peut
    être perdu au reboot).
- **Outillage ESP32 embarqué** (`tools/esp32/` + cibles Makefile
  `esp32-setup`/`esp32-build`/`esp32-flash`) : compile et flashe l'ESP32 de
  l'ULX3S *à travers* le FPGA via le **bitstream passthru officiel 85F**
  (`emard/ulx3s-bin`) + `arduino-cli`/esptool. `setup.sh` (arduino-cli local,
  core esp32, passthru), `build.sh`, `flash.sh` (passthru → upload → recharge
  l'Oric). README avec méthode, config WiFi, dépannage (TMS/GND, gpio5).
- **Scaffold firmware ESP32 « modem Hayes WiFi » — US-MODEM phase 2**
  (`firmware/esp32_modem/`) : sketch Arduino (WiFi STA, parseur AT —
  `ATDT host:port`, `ATH`, `+++`, `ATO`, `ATE`, `ATI`, config SSID/pass en
  NVS via `AT$SSID/$PASS/$C/$W`), pont transparent série↔TCP/telnet (filtrage
  IAC minimal), porteuse en bande (`CONNECT`/`NO CARRIER`). README : câblage
  K3/K4, compilation `arduino-cli`, procédure de flash ULX3S, points ouverts
  (mappage UART ESP32, flash, DCD matériel). À compiler/flasher par bmarty
  (non testé dans le dépôt).
- **6551 ACIA + pont ESP32 — US-MODEM phase 1** : cœur `rtl/acia6551.v`
  émulé et mappé `$031C-$031F` (fidèle à `~/Oric1/src/io/acia6551.c` :
  registres data/status/command/control, `TDRE`/`RDRF`/`OVRN`, IRQ armé/
  acquitté par lecture STATUS, bits DCD/DSR). Décodé dans `oric_atmos`
  (`sel_acia`, carve hors du bus d'extension, IRQ `via_irq|ext_irq|acia_irq`).
  Pont UART 115200 vers l'ESP32 embarqué : 6551 TX → `wifi_rxd` (K3), `wifi_txd`
  (K4) → 6551 RX (nouveaux `uart_tx`/`uart_rx`), `wifi_en` actif. Testbench
  `tb_acia` (registres, TX/RX, overrun, IRQ). Le firmware Hayes/WiFi de l'ESP32
  = phase 2 (bmarty). DCD/DSR câblés à 0 en attendant.
- **Chargement de programmes `.tap` (cassette) — US2.1** : injecteur cassette
  dans le FPGA (`rtl/tape_injector.v`) qui reçoit un `.tap` par UART et génère
  la forme d'onde cassette Oric exacte sur `tape_in` (→ VIA CB1 → `CLOAD`).
  Modulation conforme à la référence `~/Oric1/src/io/cassette.c` : trame 14
  bits (start, 8 data, parité impaire, 4 stop), amorce 64×`0x16`, bit `1`
  416 µs / bit `0` 624 µs, joué quand le moteur (PB6) tourne. **Contrôle de
  flux par crédits** sur la voie retour `ftdi_rxd` (nouvel `rtl/uart_tx.v`) :
  1 octet crédit `0x5A` par octet absorbable → aucune perte quelle que soit la
  taille (jeux 48 Ko inclus). Aiguillage UART clavier/cassette (`tape_active`),
  LED5 = chargement. Script PC `tools/send_tap.py`, doc `docs/CASSETTE.md`,
  testbench `tb_tape` (redécodage de la forme d'onde, framing, crédits).

### Corrigé
- **Touche `*` AZERTY sans effet** : le scancode réel de la touche `*µ`
  variait (`0x31` mappé, mais certains claviers émettent `0x32`). Ajout de
  `0x32` (variante ISO) et `0x55` (pavé numérique) → `*` = Shift+8 Oric.
- **Touche accentuée AZERTY tombait sur le chiffre QWERTY** (« la touche 2
  reste à 2 même avec Shift »). Les touches dont le glyphe est hors ASCII
  (é è à ç ù ° £ § µ) renvoyaient 0 et `key_map` retombait alors sur la table
  positionnelle QWERTY (→ chiffre). Ajout d'un drapeau « touche AZERTY
  reconnue » (`azerty_map` renvoie {reconnue, ASCII}) : une touche AZERTY à
  glyphe hors ASCII ne produit rien, sans repli parasite.
- **Shift synthétisé AZERTY intermittent** (symptôme : `&&7&&&&7` en tapant
  la touche « 1 »). Sur l'Oric `&` = Shift+7 ; un Shift dérivé du même
  scancode montait exactement en même temps que la touche, et le scan
  clavier de la ROM attrapait parfois la touche seule. Diagnostic confirmé
  sur carte (le Shift *physique*, qui précède la touche, était fiable ; le
  synthétisé non). Les glyphes AZERTY à Shift sont désormais séquencés par
  une FSM dans `oric_keyboard.v` : le Shift **précède** la touche (LEAD
  ~20 ms), la **maintient** (HOLD, minimum garanti pour être vu par ≥1
  balayage), puis la **prolonge** au relâché (TAIL ~10 ms) — comme un vrai
  doigt. Lettres, touches directes, modificateurs, clavier série et Shift
  physique QWERTY restent combinatoires. `tb_azerty` étendu (avance/maintien/
  traîne vérifiés avec paramètres réduits).

### Ajouté
- **Bascule de disposition clavier QWERTY ⇄ AZERTY** (ULX3S) sur le bouton
  `BTN6` (RIGHT), anti-rebond ~10 ms + détection de front ; `led[4]` allumée
  indique le mode AZERTY. En AZERTY le décodage passe par
  `(scancode, Shift) → ASCII français → matrice Oric` en réutilisant la table
  `map_char` du clavier série (factorisée dans `rtl/ascii2oric.vh`) : lettres
  permutées (A/Q, Z/W, M…), rangée du haut en **chiffres directs** (sans
  Shift), symboles en Shift avec Shift Oric automatique (`(` = Shift+9, etc.). Les touches non
  alphanumériques (Entrée, Échap, flèches, espace) retombent sur la table
  positionnelle. Les glyphes hors ASCII (é è à ç ù ° £ § µ) sont ignorés
  (l'Oric ne les affiche pas). Nouveau testbench `tb_azerty` (7 tests dans la
  suite).
- **`rtl/ascii2oric.vh`** : table ASCII→matrice Oric partagée entre
  `key_injector` (clavier série UART) et `oric_keyboard` (disposition AZERTY),
  élimine la duplication. Makefile : `-I rtl` (iverilog) et `read_verilog
  -I../rtl` (yosys) pour l'include.

### Validé sur carte
- **Clavier USB physique fonctionnel** sur l'ULX3S (frappe réelle confirmée
  par bmarty) — clôt le point de validation matérielle US2.

## [2.0.0-tn20k] — 2026-07-29 — Portage Gowin : premier bitstream Tang Nano 20K

### Ajouté
- **Portage complet du core sur GW2AR-18** (gowin/) : bitstream
  `oric_tn20k.fs` généré par la chaîne libre (yosys synth_gowin +
  nextpnr-himbaechel/apicula + gowin_pack). LUT 19 %, timing 79,6 MHz
  pour 27 requis. Cœur Oric (6502/ULA/VIA/AY) inchangé, DIV=27.
- **Vidéo 720×576p50 par doubleur de lignes** : trames ULA et HDMI de
  longueur strictement égale (539 136 cycles, vérifié par tb_video576),
  verrouillées au reset — zéro framebuffer, zéro tearing (résout US3.2
  par construction). TMDS par OSER10 + TLVDS_OBUF, rPLL 27→135 MHz.
- Clavier série via le BL616 embarqué (USB-C), audio sigma-delta 1 bit.
- RAM Gowin dédiée : 64 Ko simple-port + miroir vidéo $9800-$BFFF
  (10 Ko) pour la ULA — 45/46 blocs BSRAM (la 1W2R naïve en exigeait 64).

### Corrigé
- Collision de nom avec la primitive Gowin `ALU` : ALU du 6502 renommée
  à la volée au build.
- RAM principale passée en lecture/écriture exclusives (NO_CHANGE) —
  régression ECP5 6/6 tests OK.

## [1.2.0] — 2026-07-29 — Sprint 3 : port d'extension, cassette, imprimante

### Ajouté
- **Port d'extension Oric complet sur GPIO** (`expansion_port.v`) : bus 6502,
  Φ2, /ROMDIS, /MAP, /IOCTRL, /IRQ, /RESET drain ouvert — sémantique fidèle
  (ROM / RAM cachée / cartouche), VIA restreinte à $0300-$030F. Cible :
  cartouche LOCI réelle. Brochage officiel (annexe 11 manuel Atmos) et table
  de câblage dans docs/PORT_EXTENSION.md. Testbench tb_expansion.
- **Signaux cassette** (PB7 sortie, PB6 moteur, CB1 entrée) et
  **imprimante Centronics** (PA données, PB4 strobe, CA1 ack) sur GPIO.
- Spécification de la carte « face arrière Atmos » au format carte mère
  d'origine (hardware/FACE_ARRIERE_ATMOS.md) : connecteurs d'époque + HDMI,
  berceaux 2× Pico W + carte FPGA, 2 USB-A, haut-parleur, phasage A/B.

### Déployé
- Bitstream v1.2.0 (inclut les correctifs HIRES/clignotement v1.1.1) gravé
  en flash SPI : démarrage autonome. 6/6 tests, timing 54,7 MHz (25 requis).

## [1.1.1] — 2026-07-29 — Correctif HIRES

### Corrigé
- **HIRES : charset des 3 rangées texte du bas** — la base charset suit
  désormais le mode global de la ULA (`vmode[2]`) et non la zone de la
  ligne : en HIRES ces rangées lisent $9800/$9C00 (seule zone entretenue
  par la ROM), $B400 contenant alors des données périmées (symptôme
  constaté sur carte : texte blanc sur fond blanc). Conforme à
  `get_charset_byte` de la référence. Test ajouté à tb_ula.
- **Clignotement** : inversion périodique des couleurs (XOR avec le bit 7),
  et non masquage du caractère — conforme à `blink_phase_on` de la
  référence.

## [1.1.0] — 2026-07-29 — Sprint 2 : clavier série + fiabilisation HDMI

### Déployé
- Bitstream v1.1.0 gravé en flash SPI (--unprotect-flash requis) :
  démarrage autonome à la mise sous tension.

### Ajouté
- **Clavier série depuis le PC** (port US1, 115200 8N1) : `uart_rx.v` +
  `key_injector.v` (FIFO 256 octets, table ASCII→matrice Oric issue des
  tables ROM $FF70/$FFB0, frappe 45 ms + pause 25 ms, Shift automatique,
  CR/LF dédupliqués). Voir docs/CLAVIER_SERIE.md. Testbench `tb_injector`.

### Corrigé
- **HDMI : chargement TMDS aligné en phase** : le compteur mod-5 libre
  pouvait verrouiller les mots TMDS pendant leur transition selon la phase
  de démarrage de la PLL (perte de synchro intermittente constatée sur
  écran). Le front de clk_pixel est maintenant détecté dans le domaine
  125 MHz et le chargement s'effectue ~16 ns après la mise à jour des mots.

## [1.0.0] — 2026-07-29 — Sprint 1 terminé : « Il boote »

### Validé
- `tb_boot` : boot complet de la ROM en simulation — écran
  « ORIC EXTENDED BASIC V1.1 / © 1983 TANGERINE / 37631 BYTES FREE / Ready »
  identique à la machine réelle (bannière + charset copiés par la ROM).
- Timing nextpnr final : clk_sys 54,5 MHz (requis 25), clk_shift 256 MHz
  (requis 125), clk_pixel 59,4 MHz, clk_usb 76 MHz — tous PASS.
- Ressources ECP5-85F : 87/208 DP16KD (41 %), 4 MULT18, 2/4 PLL.
- Bitstream `build/oric_ulx3s.bit` flashé sur carte (openFPGALoader, SRAM).

## [0.2.0] — 2026-07-29 — Sprint 1 (suite)

### Ajouté
- RTL complet du core : `oric_ula.v` (PAL 384×312, TEXT/HIRES, attributs
  série, framebuffer 240×224), `via6522.v`, `oric_keyboard.v` (HID→matrice),
  `oric_atmos.v` (6502 Arlet à 1 MHz + RAM 48 Ko + ROM 16 Ko + AY jt49),
  `hdmi_out.v`/`tmds_encoder.v` (DVI 640×480@60, zoom ×2), `top_ulx3s.v`
  (2 PLL, hôte USB HID, audio jack 4 bits, LEDs de vie).
- Testbenches auto-vérifiants : `tb_via6522`, `tb_keyboard`, `tb_ula`,
  `tb_boot` (boot ROM complet). Cible `make test`.
- Makefile : synthèse yosys/nextpnr/ecppack, `make prog` (openFPGALoader).

### Corrigé
- **Protocole bus 6502 sous RDY** : le core d'Arlet ne garantit AB/WE/DO que
  pendant la phase RDY (DIMUX bascule de DIHOLD vers DI). Re-temporisation
  exacte de l'environnement natif : capture AB/WE/DO au front cen1, fetch au
  début du cycle suivant, DI verrouillé à t4 et consommé au front cen1
  suivant. Vérifié instruction par instruction contre le core en
  environnement natif pleine vitesse (sim/tb_trace.v).
- Boucle combinatoire AB→DI→AB avec le 6502 d'Arlet : lecture VIA et mux DI
  registrés.
- yosys `-noabc9` (assertion abc9 sur le pmux du CPU).
- RAM initialisée à zéro (état réel de la BRAM ECP5 ; supprime la
  propagation de X en simulation).
- clk_sys porté à 25 MHz (DIV=25) : le 1 MHz CPU est exact, ecppll ne
  pouvant pas produire 24 MHz.

## [0.1.0] — 2026-07-29 — Sprint 1

### Ajouté
- Structure initiale du projet (rtl/, third_party/, sim/, tests/, docs/, constraints/).
- Documentation : README, ARCHITECTURE, BACKLOG agile, CHANGELOG.
- Cores libres vendorés : verilog-6502 (Arlet), jt49 (jotego), usb_hid_host (nand2mario).
- Contraintes ULX3S v2.0 (ulx3s_v20.lpf, emard).
- ROM BASIC 1.1b copiée depuis la référence ~/Oric1 et convertie en .hex.

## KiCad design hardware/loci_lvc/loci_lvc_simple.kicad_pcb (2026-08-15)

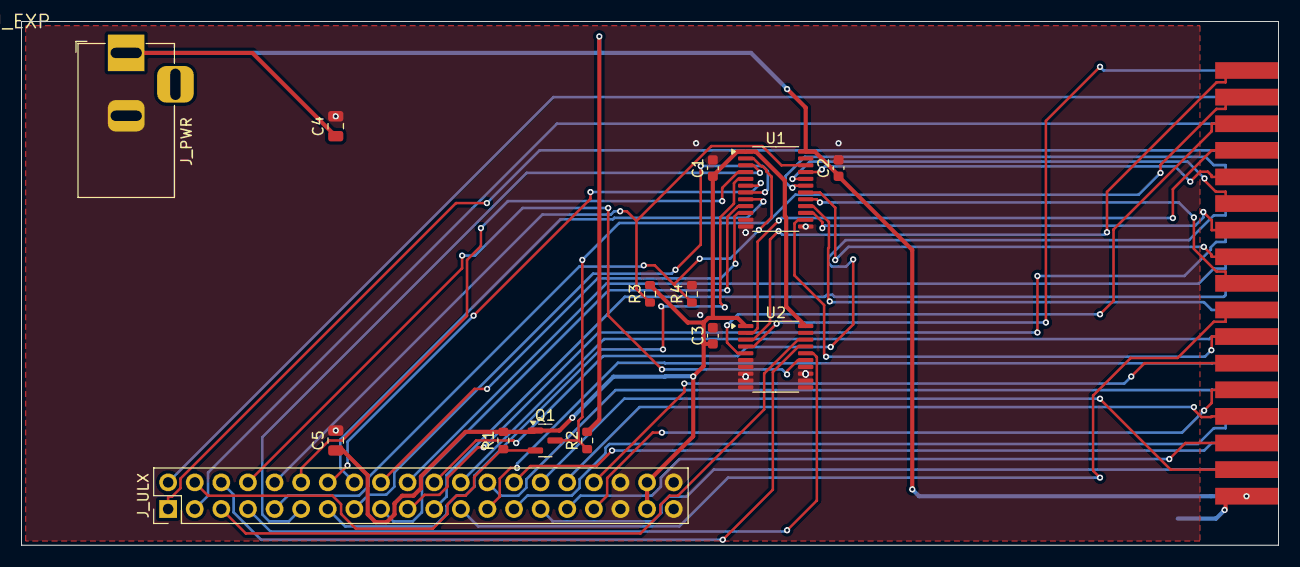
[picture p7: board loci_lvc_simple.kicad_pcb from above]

Board: 2 copper layers, 120.0 x 50.0 mm, 15 parts (0 on the bottom side), 50 nets.

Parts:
C1, C2, C3: 100nF; C_0603_1608Metric
C4, C5: 100nF; C_0805_2012Metric
J_EXP: EDGE_34; JEXP_34
J_PWR: Jack_5.5x2.1; BarrelJack_Horizontal
J_ULX: Conn_02x20; PinHeader_2x20_P2.54mm_Vertical
Q1: BSS138; SOT-23
R1, R2, R3, R4: 10k; R_0603_1608Metric
U1: SN74LVCC3245APW; TSSOP-24_4.4x7.8mm_P0.65mm
U2: SN74LVC245APW; TSSOP-20_4.4x6.5mm_P0.65mm

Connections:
+3V3: C1.1, C3.1, C5.1, J_ULX.37, J_ULX.38, Q1.1, R1.2, R3.2, U1.1, U2.1, U2.20
+5V: C2.1, C4.1, J_EXP.33, J_PWR.1, R2.2, U1.24
A0: J_EXP.13, J_ULX.19
A1: J_EXP.15, J_ULX.20
A2: J_EXP.17, J_ULX.21
A3: J_EXP.11, J_ULX.22
A4: J_EXP.20, J_ULX.23
A5: J_EXP.21, J_ULX.24
A6: J_EXP.23, J_ULX.25
A7: J_EXP.25, J_ULX.26
A8: J_EXP.27, J_ULX.27
A9: J_EXP.29, J_ULX.28
A10: J_EXP.31, J_ULX.29
A11: J_EXP.32, J_ULX.30
A12: J_EXP.30, J_ULX.31
A13: J_EXP.28, J_ULX.32
A14: J_EXP.26, J_ULX.33
A15: J_EXP.24, J_ULX.34
D0: J_ULX.11, U1.3
D1: J_ULX.12, U1.4
D2: J_ULX.13, U1.5
D3: J_ULX.14, U1.6
D4: J_ULX.15, U1.7
D5: J_ULX.16, U1.8
D5V0: J_EXP.10, U1.21
D5V1: J_EXP.12, U1.20
D5V2: J_EXP.9, U1.19
D5V3: J_EXP.16, U1.18
D5V4: J_EXP.18, U1.17
D5V5: J_EXP.19, U1.16
D5V6: J_EXP.14, U1.15
D5V7: J_EXP.22, U1.14
D6: J_ULX.17, U1.9
D7: J_ULX.18, U1.10
GND: C1.2, C2.2, C3.2, C4.2, C5.2, J_EXP.34, J_PWR.2, J_ULX.35, J_ULX.36, J_ULX.39, J_ULX.40, R4.2, U1.11, U1.12, U1.13, U2.6, U2.7, U2.8, U2.9, U2.10, U2.11, U2.12, U2.13, U2.14, U2.19
IOCTL5_n: J_EXP.6, U2.5
IOCTL_n: J_ULX.8, U2.15
IO_n: J_EXP.5, J_ULX.3
IRQ5_n: J_EXP.8, U2.2
IRQ_n: J_ULX.5, U2.18
MAP5_n: J_EXP.1, U2.4
MAP_n: J_ULX.7, U2.16
PHI2: J_EXP.3, J_ULX.2
ROMDIS5_n: J_EXP.2, U2.3
ROMDIS_n: J_ULX.6, U2.17
RST5_n: J_EXP.4, Q1.3, R2.1
RST_n: J_ULX.4, Q1.2, R1.1
RW: J_EXP.7, J_ULX.1
XCVR_DIR: J_ULX.9, R4.1, U1.2
XCVR_OE_n: J_ULX.10, R3.1, U1.22

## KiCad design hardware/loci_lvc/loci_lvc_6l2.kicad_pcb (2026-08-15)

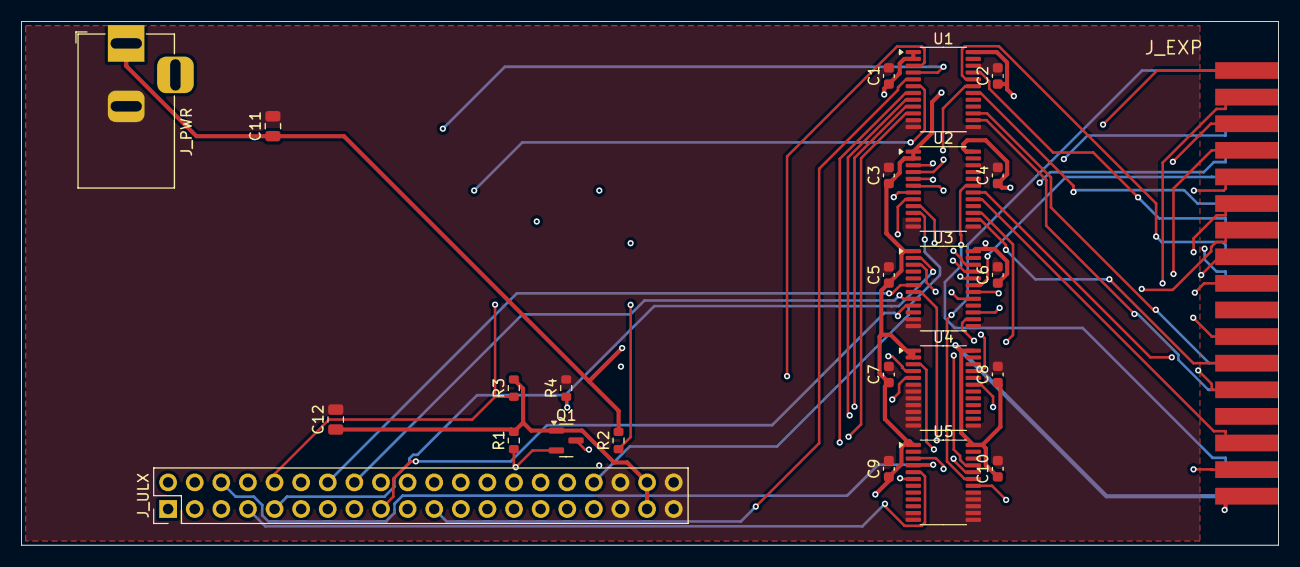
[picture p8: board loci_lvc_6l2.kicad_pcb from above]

Board: 6 copper layers, 120.0 x 50.0 mm, 25 parts (0 on the bottom side), 69 nets.

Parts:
C1, C2, C3, C4, C5, C6, C7, C8, C9, C10: 100nF; C_0603_1608Metric
C11, C12: 10uF; C_0805_2012Metric
J_EXP: EDGE_34_GOLDFINGERS; JEXP_34_GOLDFINGERS
J_PWR: Jack_5.5x2.1; BarrelJack_Horizontal
J_ULX: Conn_02x20; PinHeader_2x20_P2.54mm_Vertical
Q1: BSS138; SOT-23
R1, R2, R3, R4: 10k; R_0603_1608Metric
U1, U2, U3, U4, U5: SN74LVCC3245APW; TSSOP-24_4.4x7.8mm_P0.65mm

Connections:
+3V3: C1.1, C3.1, C5.1, C7.1, C9.1, C12.1, J_ULX.37, J_ULX.38, Q1.1, R1.2, R3.2, U1.1, U1.2, U2.1, U2.2, U3.1, U4.1, U4.2, U5.1
+5V: C2.1, C4.1, C6.1, C8.1, C10.1, C11.1, J_EXP.33, J_PWR.1, R2.2, U1.24, U2.24, U3.24, U4.24, U5.24
A0: J_ULX.19, U1.3
A1: J_ULX.20, U1.4
A2: J_ULX.21, U1.5
A3: J_ULX.22, U1.6
A4: J_ULX.23, U1.7
A5: J_ULX.24, U1.8
A5V0: J_EXP.13, U1.21
A5V1: J_EXP.15, U1.20
A5V2: J_EXP.17, U1.19
A5V3: J_EXP.11, U1.18
A5V4: J_EXP.20, U1.17
A5V5: J_EXP.21, U1.16
A5V6: J_EXP.23, U1.15
A5V7: J_EXP.25, U1.14
A5V8: J_EXP.27, U2.21
A5V9: J_EXP.29, U2.20
A5V10: J_EXP.31, U2.19
A5V11: J_EXP.32, U2.18
A5V12: J_EXP.30, U2.17
A5V13: J_EXP.28, U2.16
A5V14: J_EXP.26, U2.15
A5V15: J_EXP.24, U2.14
A6: J_ULX.25, U1.9
A7: J_ULX.26, U1.10
A8: J_ULX.27, U2.3
A9: J_ULX.28, U2.4
A10: J_ULX.29, U2.5
A11: J_ULX.30, U2.6
A12: J_ULX.31, U2.7
A13: J_ULX.32, U2.8
A14: J_ULX.33, U2.9
A15: J_ULX.34, U2.10
D0: J_ULX.11, U3.3
D1: J_ULX.12, U3.4
D2: J_ULX.13, U3.5
D3: J_ULX.14, U3.6
D4: J_ULX.15, U3.7
D5: J_ULX.16, U3.8
D5V0: J_EXP.10, U3.21
D5V1: J_EXP.12, U3.20
D5V2: J_EXP.9, U3.19
D5V3: J_EXP.16, U3.18
D5V4: J_EXP.18, U3.17
D5V5: J_EXP.19, U3.16
D5V6: J_EXP.14, U3.15
D5V7: J_EXP.22, U3.14
D6: J_ULX.17, U3.9
D7: J_ULX.18, U3.10
GND: C1.2, C2.2, C3.2, C4.2, C5.2, C6.2, C7.2, C8.2, C9.2, C10.2, C11.2, C12.2, J_EXP.34, J_PWR.2, J_ULX.35, J_ULX.36, J_ULX.39, J_ULX.40, R4.2, U1.11, U1.12, U1.13, U1.22, U2.11, U2.12, U2.13, U2.22, U3.11, U3.12, U3.13, U4.6, U4.7, U4.8, U4.9, U4.10, U4.11, U4.12, U4.13, U4.22, U5.2, U5.11, U5.12, U5.13, U5.14, U5.15, U5.16, U5.17, U5.22
IO5_n: J_EXP.5, U4.19
IOCTL5_n: J_EXP.6, U5.18
IOCTL_n: J_ULX.8, U5.6
IO_n: J_ULX.3, U4.5
IRQ5_n: J_EXP.8, U5.21
IRQ_n: J_ULX.5, U5.3
MAP5_n: J_EXP.1, U5.19
MAP_n: J_ULX.7, U5.5
PHI2: J_ULX.2, U4.4
PHI2_5: J_EXP.3, U4.20
ROMDIS5_n: J_EXP.2, U5.20
ROMDIS_n: J_ULX.6, U5.4
RST5_n: J_EXP.4, Q1.3, R2.1
RST_n: J_ULX.4, Q1.2, R1.1
RW: J_ULX.1, U4.3
RW5: J_EXP.7, U4.21
XCVR_DIR: J_ULX.9, R4.1, U3.2
XCVR_OE_n: J_ULX.10, R3.1, U3.22

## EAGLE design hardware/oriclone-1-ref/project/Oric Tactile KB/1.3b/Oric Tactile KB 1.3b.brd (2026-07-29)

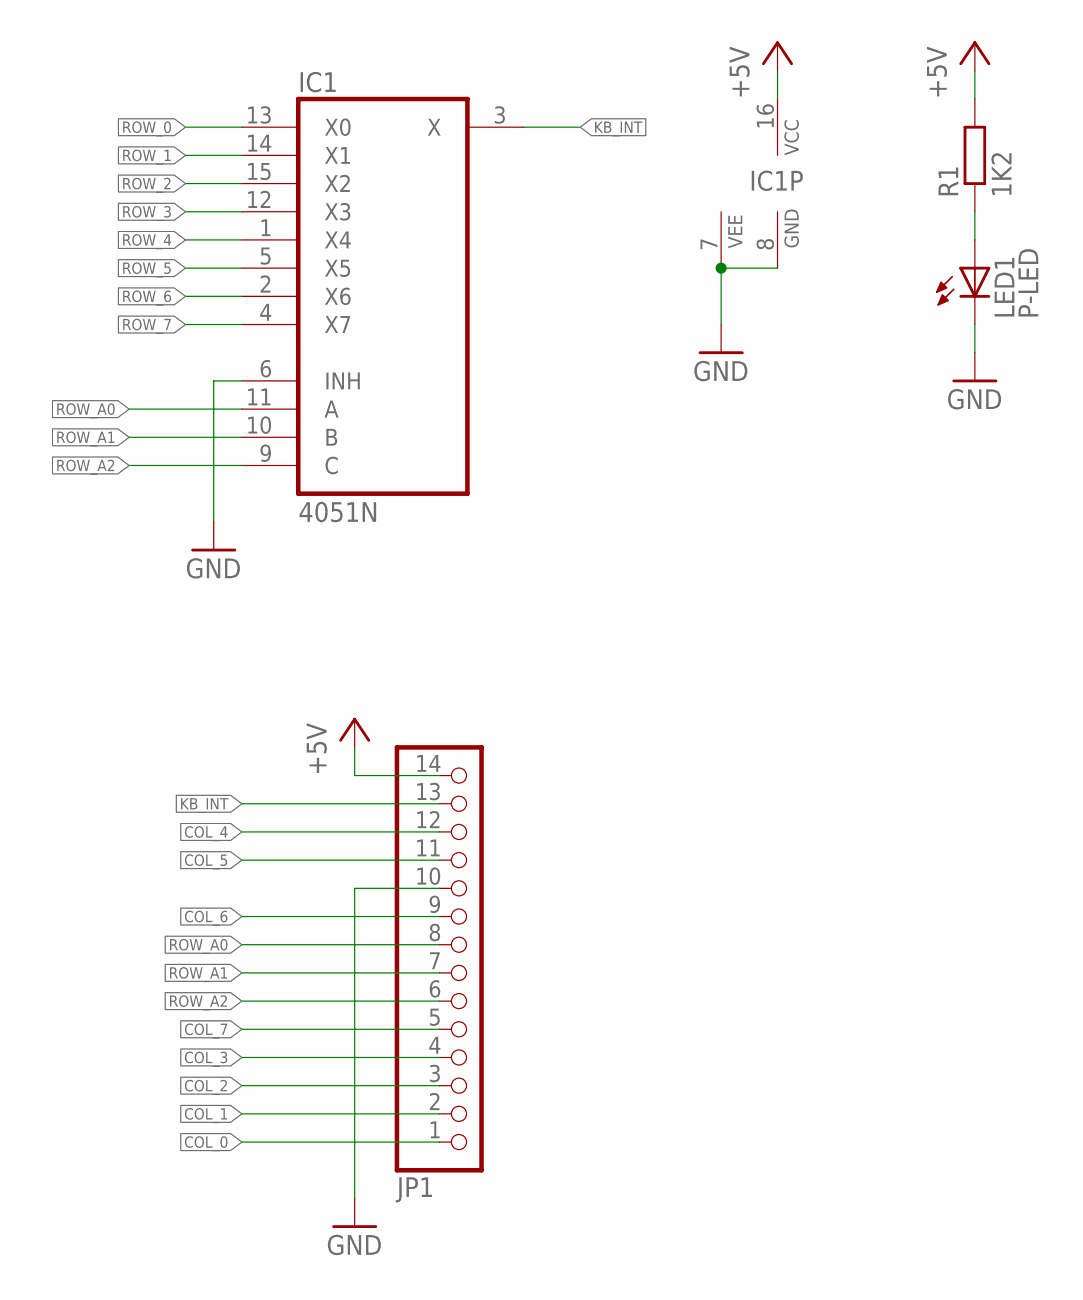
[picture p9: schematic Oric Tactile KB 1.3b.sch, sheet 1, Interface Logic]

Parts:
IC1: 4051N; DIL16
JP1: PINHD-1X14; 1X14
LED1: P-LED; LED3MM
R1: 1K2; 0207/7

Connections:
+5V: IC1.16 (VCC), JP1.14, R1.2
COL_0: JP1.1; also elsewhere on the board
COL_1: JP1.2; also elsewhere on the board
COL_2: JP1.3; also elsewhere on the board
COL_3: JP1.4; also elsewhere on the board
COL_4: JP1.12; also elsewhere on the board
COL_5: JP1.11; also elsewhere on the board
COL_6: JP1.9; also elsewhere on the board
COL_7: JP1.5; also elsewhere on the board
GND: IC1.6 (INH), IC1.7 (VEE), IC1.8 (GND), JP1.10, LED1.K (C)
KB_INT: IC1.3 (X), JP1.13
unnamed: LED1.A, R1.1
ROW_0: IC1.13 (X0); also elsewhere on the board
ROW_1: IC1.14 (X1); also elsewhere on the board
ROW_2: IC1.15 (X2); also elsewhere on the board
ROW_3: IC1.12 (X3); also elsewhere on the board
ROW_4: IC1.1 (X4); also elsewhere on the board
ROW_5: IC1.5 (X5); also elsewhere on the board
ROW_6: IC1.2 (X6); also elsewhere on the board
ROW_7: IC1.4 (X7); also elsewhere on the board
ROW_A0: IC1.11 (A), JP1.8
ROW_A1: IC1.10 (B), JP1.7
ROW_A2: IC1.9 (C), JP1.6

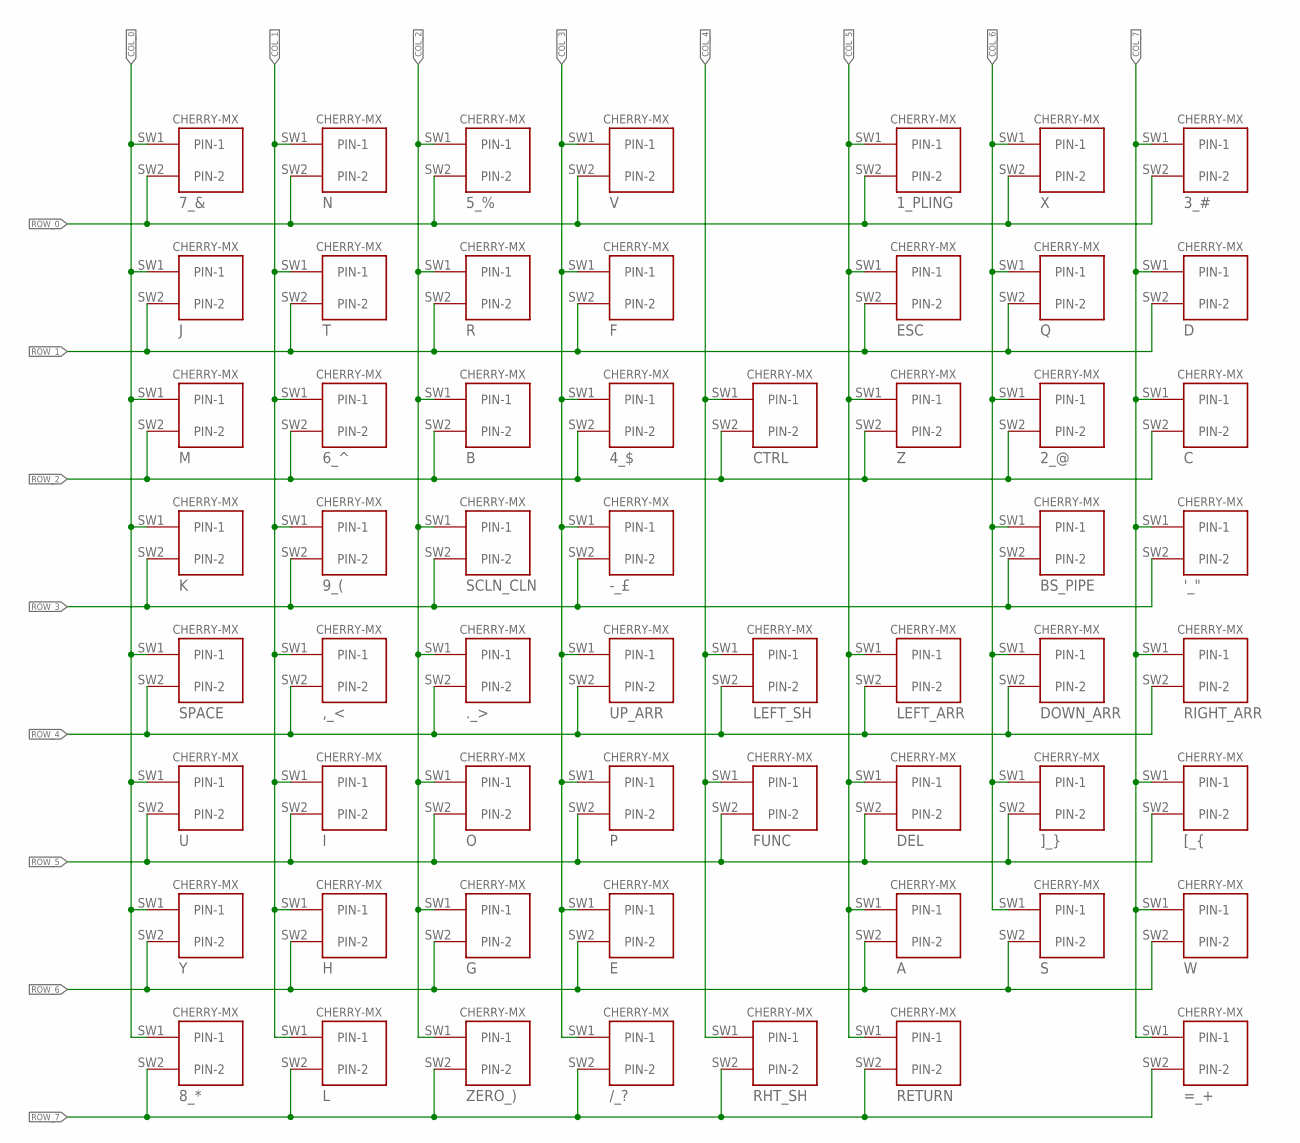
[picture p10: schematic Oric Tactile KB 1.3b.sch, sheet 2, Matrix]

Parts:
1_PLING, 2_@, 3_#, 4_$, 5_%, 6_^, 7_&, 8_*, 9_(, ._>: CHERRY-MX
'_": CHERRY-MX
,_<: CHERRY-MX
-_£: CHERRY-MX
/_?: CHERRY-MX
=_+: CHERRY-MX
A: CHERRY-MX
B: CHERRY-MX
BS_PIPE: CHERRY-MX
C: CHERRY-MX
CTRL: CHERRY-MX
D: CHERRY-MX
DEL: CHERRY-MX
DOWN_ARR: CHERRY-MX
E: CHERRY-MX
ESC: CHERRY-MX
F: CHERRY-MX
FUNC: CHERRY-MX
G: CHERRY-MX
H: CHERRY-MX
I: CHERRY-MX
J: CHERRY-MX
K: CHERRY-MX
L: CHERRY-MX
LEFT_ARR: CHERRY-MX
LEFT_SH: CHERRY-MX
M: CHERRY-MX
N: CHERRY-MX
O: CHERRY-MX
P: CHERRY-MX
Q: CHERRY-MX
R: CHERRY-MX
RETURN: CHERRY-MX
RHT_SH: CHERRY-MX
RIGHT_ARR: CHERRY-MX
S: CHERRY-MX
SCLN_CLN: CHERRY-MX
SPACE: CHERRY-MX
T: CHERRY-MX
U: CHERRY-MX
UP_ARR: CHERRY-MX
V: CHERRY-MX
W: CHERRY-MX
X: CHERRY-MX
Y: CHERRY-MX
Z: CHERRY-MX
ZERO_): CHERRY-MX
[_{: CHERRY-MX
]_}: CHERRY-MX

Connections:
COL_0: 7_&.SW1 (PIN-1), 8_*.SW1 (PIN-1), J.SW1 (PIN-1), K.SW1 (PIN-1), M.SW1 (PIN-1), SPACE.SW1 (PIN-1), U.SW1 (PIN-1), Y.SW1 (PIN-1); also elsewhere on the board
COL_1: 6_^.SW1 (PIN-1), 9_(.SW1 (PIN-1), ,_<.SW1 (PIN-1), H.SW1 (PIN-1), I.SW1 (PIN-1), L.SW1 (PIN-1), N.SW1 (PIN-1), T.SW1 (PIN-1); also elsewhere on the board
COL_2: 5_%.SW1 (PIN-1), ._>.SW1 (PIN-1), B.SW1 (PIN-1), G.SW1 (PIN-1), O.SW1 (PIN-1), R.SW1 (PIN-1), SCLN_CLN.SW1 (PIN-1), ZERO_).SW1 (PIN-1); also elsewhere on the board
COL_3: 4_$.SW1 (PIN-1), -_£.SW1 (PIN-1), /_?.SW1 (PIN-1), E.SW1 (PIN-1), F.SW1 (PIN-1), P.SW1 (PIN-1), UP_ARR.SW1 (PIN-1), V.SW1 (PIN-1); also elsewhere on the board
COL_4: CTRL.SW1 (PIN-1), FUNC.SW1 (PIN-1), LEFT_SH.SW1 (PIN-1), RHT_SH.SW1 (PIN-1); also elsewhere on the board
COL_5: 1_PLING.SW1 (PIN-1), A.SW1 (PIN-1), DEL.SW1 (PIN-1), ESC.SW1 (PIN-1), LEFT_ARR.SW1 (PIN-1), RETURN.SW1 (PIN-1), Z.SW1 (PIN-1); also elsewhere on the board
COL_6: 2_@.SW1 (PIN-1), BS_PIPE.SW1 (PIN-1), DOWN_ARR.SW1 (PIN-1), Q.SW1 (PIN-1), S.SW1 (PIN-1), X.SW1 (PIN-1), ]_}.SW1 (PIN-1); also elsewhere on the board
COL_7: 3_#.SW1 (PIN-1), '_".SW1 (PIN-1), =_+.SW1 (PIN-1), C.SW1 (PIN-1), D.SW1 (PIN-1), RIGHT_ARR.SW1 (PIN-1), W.SW1 (PIN-1), [_{.SW1 (PIN-1); also elsewhere on the board
ROW_0: 1_PLING.SW2 (PIN-2), 3_#.SW2 (PIN-2), 5_%.SW2 (PIN-2), 7_&.SW2 (PIN-2), N.SW2 (PIN-2), V.SW2 (PIN-2), X.SW2 (PIN-2); also elsewhere on the board
ROW_1: D.SW2 (PIN-2), ESC.SW2 (PIN-2), F.SW2 (PIN-2), J.SW2 (PIN-2), Q.SW2 (PIN-2), R.SW2 (PIN-2), T.SW2 (PIN-2); also elsewhere on the board
ROW_2: 2_@.SW2 (PIN-2), 4_$.SW2 (PIN-2), 6_^.SW2 (PIN-2), B.SW2 (PIN-2), C.SW2 (PIN-2), CTRL.SW2 (PIN-2), M.SW2 (PIN-2), Z.SW2 (PIN-2); also elsewhere on the board
ROW_3: 9_(.SW2 (PIN-2), '_".SW2 (PIN-2), -_£.SW2 (PIN-2), BS_PIPE.SW2 (PIN-2), K.SW2 (PIN-2), SCLN_CLN.SW2 (PIN-2); also elsewhere on the board
ROW_4: ,_<.SW2 (PIN-2), ._>.SW2 (PIN-2), DOWN_ARR.SW2 (PIN-2), LEFT_ARR.SW2 (PIN-2), LEFT_SH.SW2 (PIN-2), RIGHT_ARR.SW2 (PIN-2), SPACE.SW2 (PIN-2), UP_ARR.SW2 (PIN-2); also elsewhere on the board
ROW_5: DEL.SW2 (PIN-2), FUNC.SW2 (PIN-2), I.SW2 (PIN-2), O.SW2 (PIN-2), P.SW2 (PIN-2), U.SW2 (PIN-2), [_{.SW2 (PIN-2), ]_}.SW2 (PIN-2); also elsewhere on the board
ROW_6: A.SW2 (PIN-2), E.SW2 (PIN-2), G.SW2 (PIN-2), H.SW2 (PIN-2), S.SW2 (PIN-2), W.SW2 (PIN-2), Y.SW2 (PIN-2); also elsewhere on the board
ROW_7: 8_*.SW2 (PIN-2), /_?.SW2 (PIN-2), =_+.SW2 (PIN-2), L.SW2 (PIN-2), RETURN.SW2 (PIN-2), RHT_SH.SW2 (PIN-2), ZERO_).SW2 (PIN-2); also elsewhere on the board

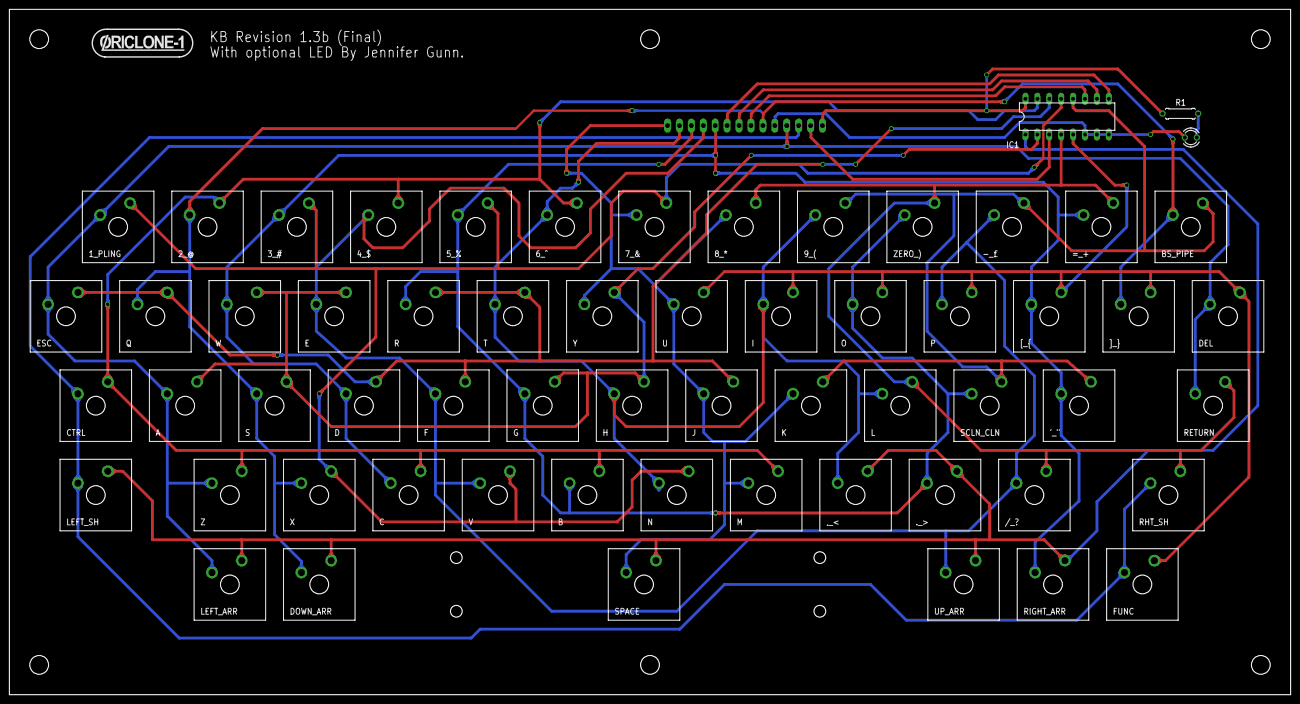
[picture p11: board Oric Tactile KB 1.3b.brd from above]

Board: 2 copper layers, 273.1 x 146.1 mm, 63 parts (1 on the bottom side), 23 nets.

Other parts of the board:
U$1: ORICLONE-1

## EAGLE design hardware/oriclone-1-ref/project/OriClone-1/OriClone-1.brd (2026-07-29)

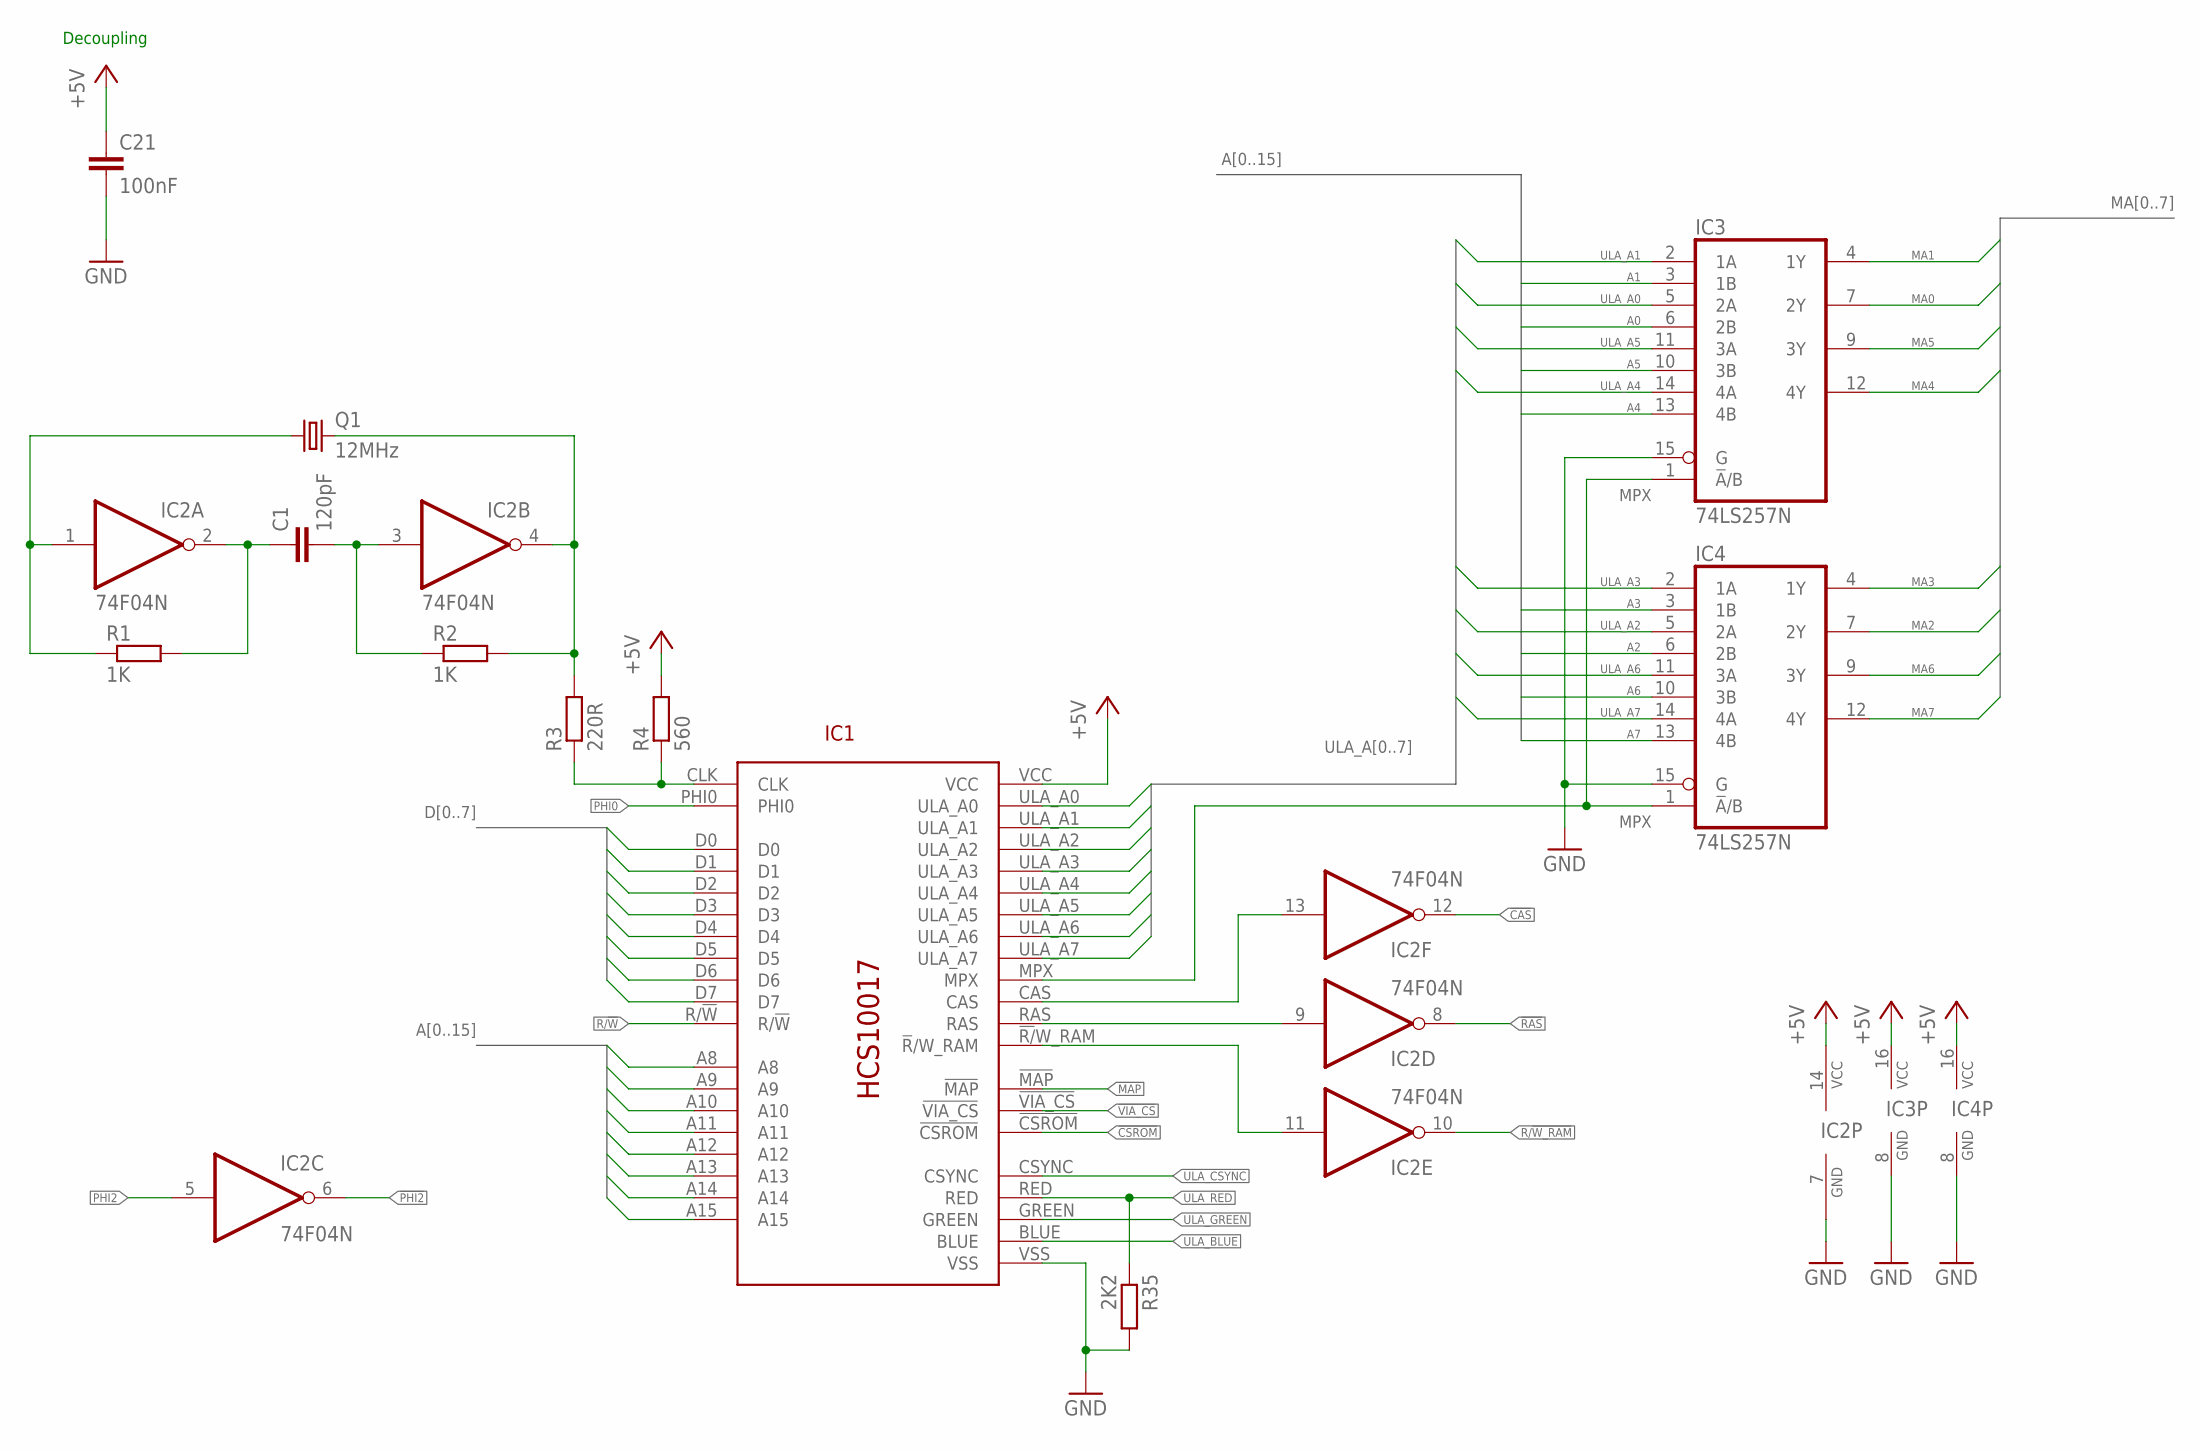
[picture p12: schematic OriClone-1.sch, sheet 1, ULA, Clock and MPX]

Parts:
C1: 120pF; C050-025X075
C21: 100nF; C050-025X075
IC1: IC1; HCS10017_DIP
IC2: 74F04N; DIL14
IC3, IC4: 74LS257N; DIL16
Q1: 12MHz; HC49U-V
R1, R2: 1K; 0207/2V
R3: 220R; 0207/2V
R4: 560; 0207/2V
R35: 2K2; 0207/10

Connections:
!CAS: IC2.12 (O); also elsewhere on the board
!CSROM: IC1.!CSROM; also elsewhere on the board
!MAP: IC1.!MAP; also elsewhere on the board
!PHI2: IC2.6 (O); also elsewhere on the board
!R/!W_RAM: IC1.!R/!W_RAM (!R!/W_RAM), IC2.11 (I)
!RAS: IC2.8 (O); also elsewhere on the board
!VIA_CS: IC1.!VIA_CS; also elsewhere on the board
+5V: C21.1, IC1.VCC, IC2.14 (VCC), IC3.16 (VCC), IC4.16 (VCC), R4.2; also elsewhere on the board
A0: IC3.6 (2B); also elsewhere on the board
A1: IC3.3 (1B); also elsewhere on the board
A2: IC4.6 (2B); also elsewhere on the board
A3: IC4.3 (1B); also elsewhere on the board
A4: IC3.13 (4B); also elsewhere on the board
A5: IC3.10 (3B); also elsewhere on the board
A6: IC4.10 (3B); also elsewhere on the board
A7: IC4.13 (4B); also elsewhere on the board
A8: IC1.A8; also elsewhere on the board
A9: IC1.A9; also elsewhere on the board
A10: IC1.A10; also elsewhere on the board
A11: IC1.A11; also elsewhere on the board
A12: IC1.A12; also elsewhere on the board
A13: IC1.A13; also elsewhere on the board
A14: IC1.A14; also elsewhere on the board
A15: IC1.A15; also elsewhere on the board
CAS: IC1.CAS, IC2.13 (I)
CLK: IC1.CLK, R3.1, R4.1
D0: IC1.D0; also elsewhere on the board
D1: IC1.D1; also elsewhere on the board
D2: IC1.D2; also elsewhere on the board
D3: IC1.D3; also elsewhere on the board
D4: IC1.D4; also elsewhere on the board
D5: IC1.D5; also elsewhere on the board
D6: IC1.D6; also elsewhere on the board
D7: IC1.D7; also elsewhere on the board
GND: C21.2, IC1.VSS, IC2.7 (GND), IC3.8 (GND), IC3.15 (G), IC4.8 (GND), IC4.15 (G), R35.2; also elsewhere on the board
MA0: IC3.7 (2Y); also elsewhere on the board
MA1: IC3.4 (1Y); also elsewhere on the board
MA2: IC4.7 (2Y); also elsewhere on the board
MA3: IC4.4 (1Y); also elsewhere on the board
MA4: IC3.12 (4Y); also elsewhere on the board
MA5: IC3.9 (3Y); also elsewhere on the board
MA6: IC4.9 (3Y); also elsewhere on the board
MA7: IC4.12 (4Y); also elsewhere on the board
MPX: IC1.MPX, IC3.1 (!A!/B), IC4.1 (!A!/B)
unnamed: C1.1, IC2.2 (O), R1.2
unnamed: C1.2, IC2.3 (I), R2.1
unnamed: IC2.4 (O), Q1.2, R2.2, R3.2
unnamed: IC2.1 (I), Q1.1, R1.1
PHI0: IC1.PHI0; also elsewhere on the board
PHI2: IC2.5 (I); also elsewhere on the board
R/!W: IC1.R/!W; also elsewhere on the board
R/!W_RAM: IC2.10 (O); also elsewhere on the board
RAS: IC1.RAS, IC2.9 (I)
ULA_A0: IC1.ULA_A0, IC3.5 (2A)
ULA_A1: IC1.ULA_A1, IC3.2 (1A)
ULA_A2: IC1.ULA_A2, IC4.5 (2A)
ULA_A3: IC1.ULA_A3, IC4.2 (1A)
ULA_A4: IC1.ULA_A4, IC3.14 (4A)
ULA_A5: IC1.ULA_A5, IC3.11 (3A)
ULA_A6: IC1.ULA_A6, IC4.11 (3A)
ULA_A7: IC1.ULA_A7, IC4.14 (4A)
ULA_BLUE: IC1.BLUE; also elsewhere on the board
ULA_CSYNC: IC1.CSYNC; also elsewhere on the board
ULA_GREEN: IC1.GREEN; also elsewhere on the board
ULA_RED: IC1.RED, R35.1; also elsewhere on the board

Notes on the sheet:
Decoupling

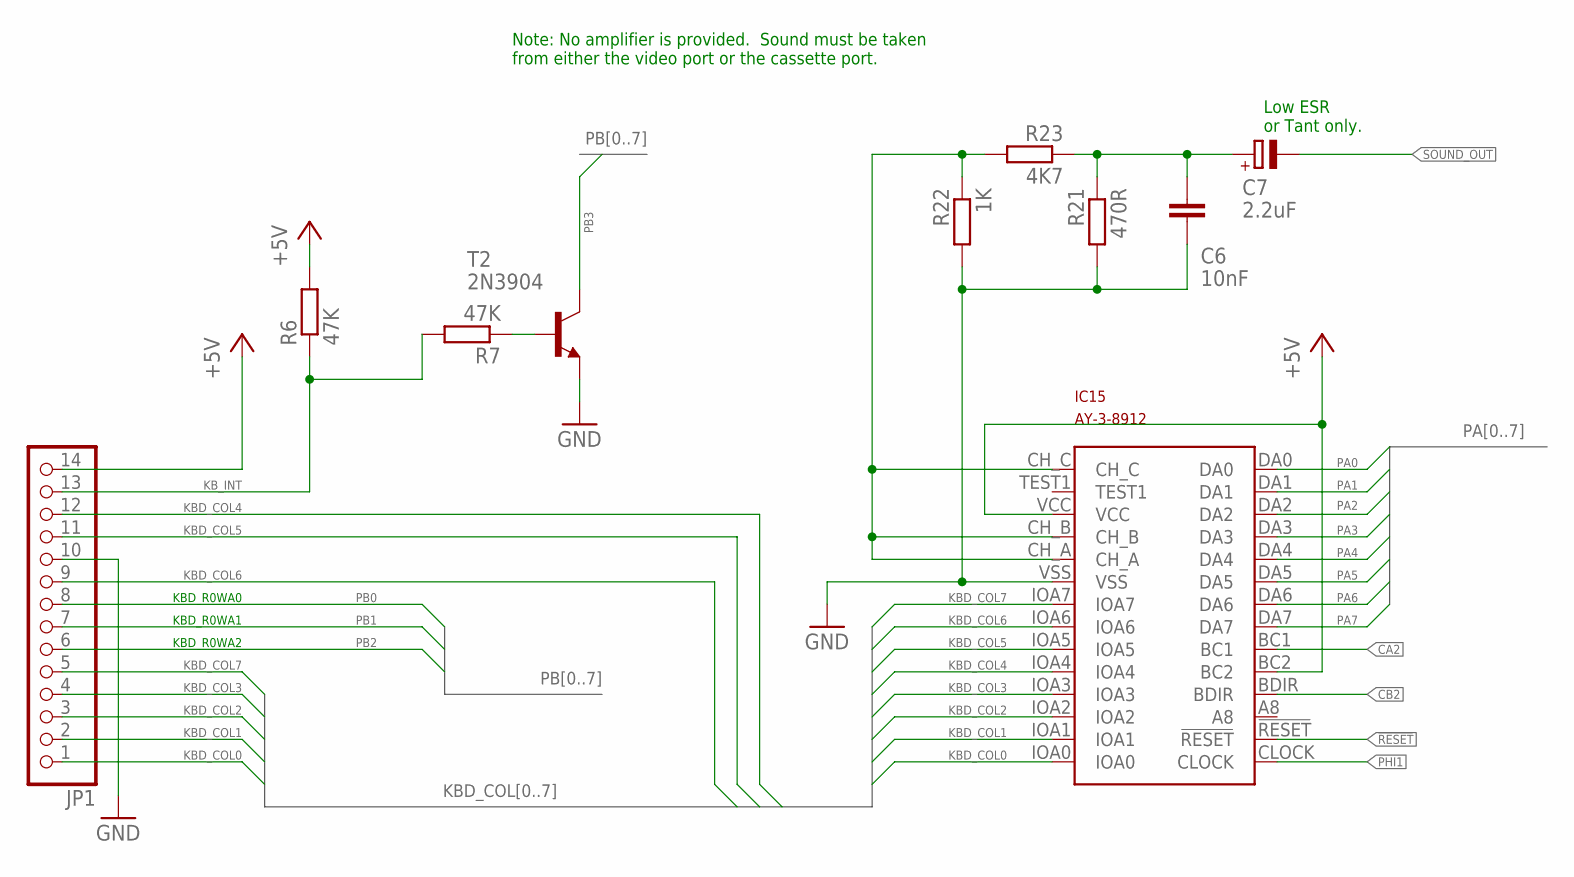
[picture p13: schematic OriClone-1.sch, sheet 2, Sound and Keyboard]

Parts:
C6: 10nF; C050-025X075
C7: 2.2uF; E5-6
IC15: AY-3-8912; DIP
JP1: PINHD-1X14; 1X14
R6: 47K; 0207/2V
R7: 47K; 0207/10
R21: 470R; 0207/10
R22: 1K; 0207/10
R23: 4K7; 0207/10
T2: 2N3904; TO92

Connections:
!RESET: IC15.!RESET; also elsewhere on the board
+5V: IC15.BC2, IC15.VCC, JP1.14, R6.2; also elsewhere on the board
CA2: IC15.BC1; also elsewhere on the board
CB2: IC15.BDIR; also elsewhere on the board
GND: C6.2, IC15.VSS, JP1.10, R21.2, R22.2, T2.3 (E); also elsewhere on the board
KBD_COL0: IC15.IOA0, JP1.1
KBD_COL1: IC15.IOA1, JP1.2
KBD_COL2: IC15.IOA2, JP1.3
KBD_COL3: IC15.IOA3, JP1.4
KBD_COL4: IC15.IOA4, JP1.12
KBD_COL5: IC15.IOA5, JP1.11
KBD_COL6: IC15.IOA6, JP1.9
KBD_COL7: IC15.IOA7, JP1.5
KB_INT: JP1.13, R6.1, R7.2
unnamed: R7.1, T2.2 (B)
unnamed: C6.1, C7.+, R21.1, R23.1
unnamed: IC15.CH_A, IC15.CH_B, IC15.CH_C, R22.1, R23.2
PA0: IC15.DA0; also elsewhere on the board
PA1: IC15.DA1; also elsewhere on the board
PA2: IC15.DA2; also elsewhere on the board
PA3: IC15.DA3; also elsewhere on the board
PA4: IC15.DA4; also elsewhere on the board
PA5: IC15.DA5; also elsewhere on the board
PA6: IC15.DA6; also elsewhere on the board
PA7: IC15.DA7; also elsewhere on the board
PB0: JP1.8; also elsewhere on the board
PB1: JP1.7; also elsewhere on the board
PB2: JP1.6; also elsewhere on the board
PB3: T2.1 (C); also elsewhere on the board
PHI1: IC15.CLOCK; also elsewhere on the board
SOUND_OUT: C7.-; also elsewhere on the board

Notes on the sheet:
KBD_R0WA0
KBD_R0WA1
KBD_R0WA2
Low ESR or Tant only.
Note: No amplifier is provided. Sound must be taken from either the video port or the cassette port.

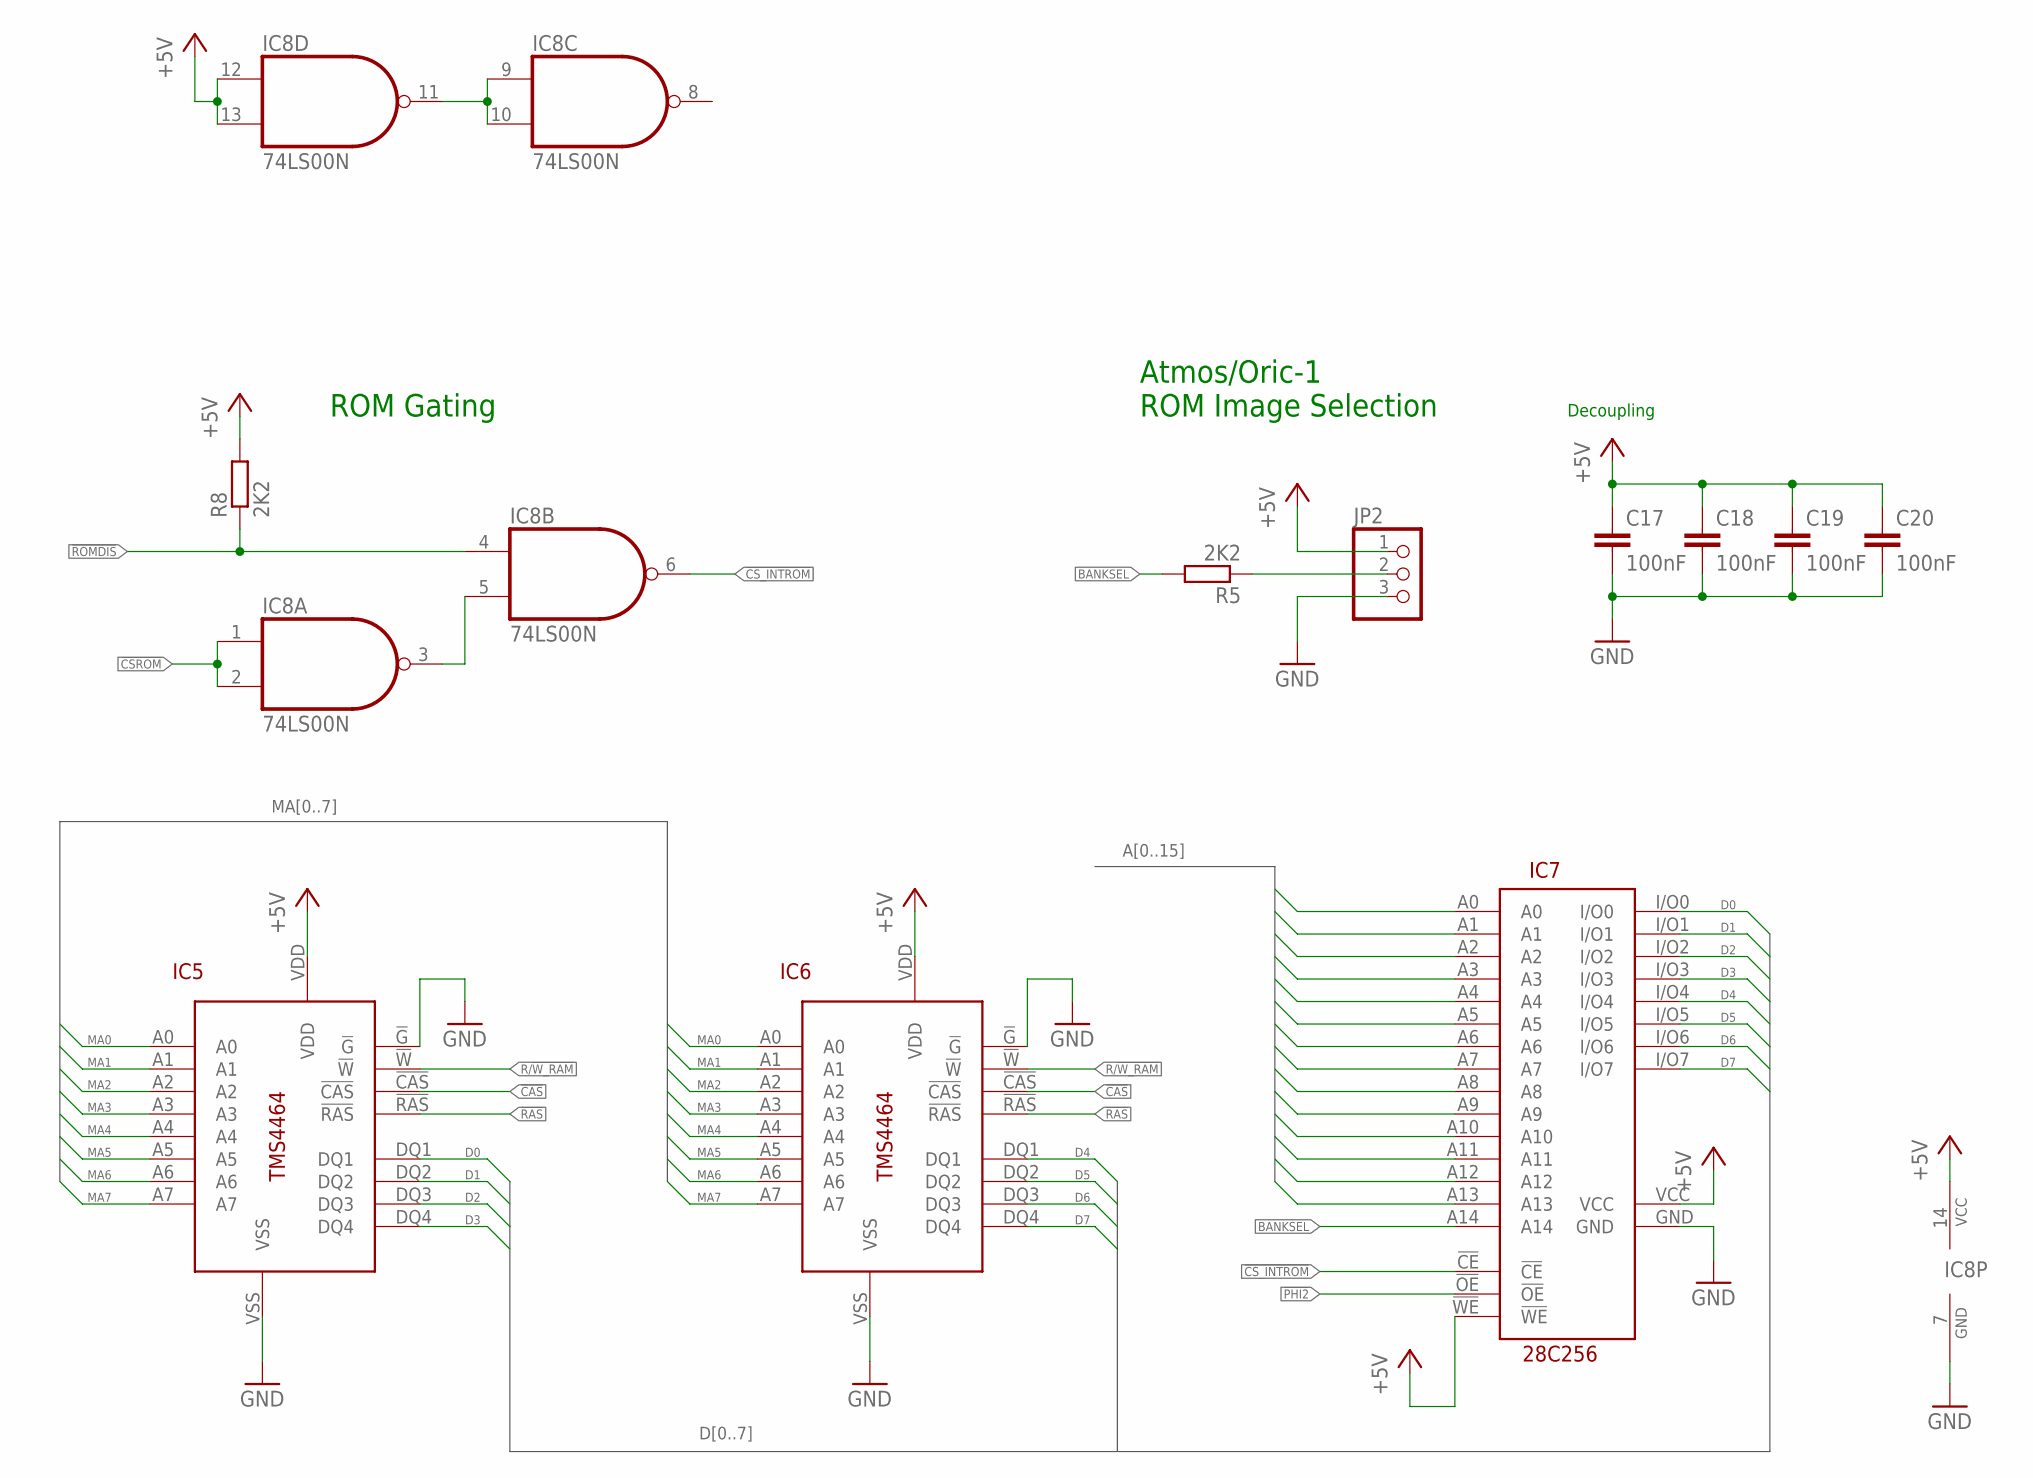
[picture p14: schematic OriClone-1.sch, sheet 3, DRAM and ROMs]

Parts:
C17, C18, C19, C20: 100nF; C050-025X075
IC5, IC6: TMS4464_DIP18; DIP18
IC7: 28C256_DIP; DIP28_WIDE
IC8: 74LS00N; DIL14
JP2: PINHD-1X3; 1X03
R5, R8: 2K2; 0207/10

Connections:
!CAS: IC5.!CAS, IC6.!CAS; also elsewhere on the board
!CSROM: IC8.1 (I0), IC8.2 (I1); also elsewhere on the board
!CS_INTROM: IC7.!CE, IC8.6 (O)
!PHI2: IC7.!OE; also elsewhere on the board
!RAS: IC5.!RAS, IC6.!RAS; also elsewhere on the board
!ROMDIS: IC8.4 (I0), R8.1; also elsewhere on the board
+5V: C17.1, C18.1, C19.1, C20.1, IC5.VDD, IC6.VDD, IC7.!WE, IC7.VCC, IC8.12 (I0), IC8.13 (I1), IC8.14 (VCC), JP2.1, R8.2; also elsewhere on the board
A0: IC7.A0; also elsewhere on the board
A1: IC7.A1; also elsewhere on the board
A2: IC7.A2; also elsewhere on the board
A3: IC7.A3; also elsewhere on the board
A4: IC7.A4; also elsewhere on the board
A5: IC7.A5; also elsewhere on the board
A6: IC7.A6; also elsewhere on the board
A7: IC7.A7; also elsewhere on the board
A8: IC7.A8; also elsewhere on the board
A9: IC7.A9; also elsewhere on the board
A10: IC7.A10; also elsewhere on the board
A11: IC7.A11; also elsewhere on the board
A12: IC7.A12; also elsewhere on the board
A13: IC7.A13; also elsewhere on the board
BANKSEL: IC7.A14, R5.2
CSROM: IC8.3 (O), IC8.5 (I1)
D0: IC5.DQ1, IC7.I/O0; also elsewhere on the board
D1: IC5.DQ2, IC7.I/O1; also elsewhere on the board
D2: IC5.DQ3, IC7.I/O2; also elsewhere on the board
D3: IC5.DQ4, IC7.I/O3; also elsewhere on the board
D4: IC6.DQ1, IC7.I/O4; also elsewhere on the board
D5: IC6.DQ2, IC7.I/O5; also elsewhere on the board
D6: IC6.DQ3, IC7.I/O6; also elsewhere on the board
D7: IC6.DQ4, IC7.I/O7; also elsewhere on the board
GND: C17.2, C18.2, C19.2, C20.2, IC5.!G, IC5.VSS, IC6.!G, IC6.VSS, IC7.GND, IC8.7 (GND), JP2.3; also elsewhere on the board
MA0: IC5.A0, IC6.A0; also elsewhere on the board
MA1: IC5.A1, IC6.A1; also elsewhere on the board
MA2: IC5.A2, IC6.A2; also elsewhere on the board
MA3: IC5.A3, IC6.A3; also elsewhere on the board
MA4: IC5.A4, IC6.A4; also elsewhere on the board
MA5: IC5.A5, IC6.A5; also elsewhere on the board
MA6: IC5.A6, IC6.A6; also elsewhere on the board
MA7: IC5.A7, IC6.A7; also elsewhere on the board
unnamed: JP2.2, R5.1
unnamed: IC8.9 (I0), IC8.10 (I1), IC8.11 (O)
R/!W_RAM: IC5.!W, IC6.!W; also elsewhere on the board

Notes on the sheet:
ROM Gating
Atmos/Oric-1 ROM Image Selection
Decoupling

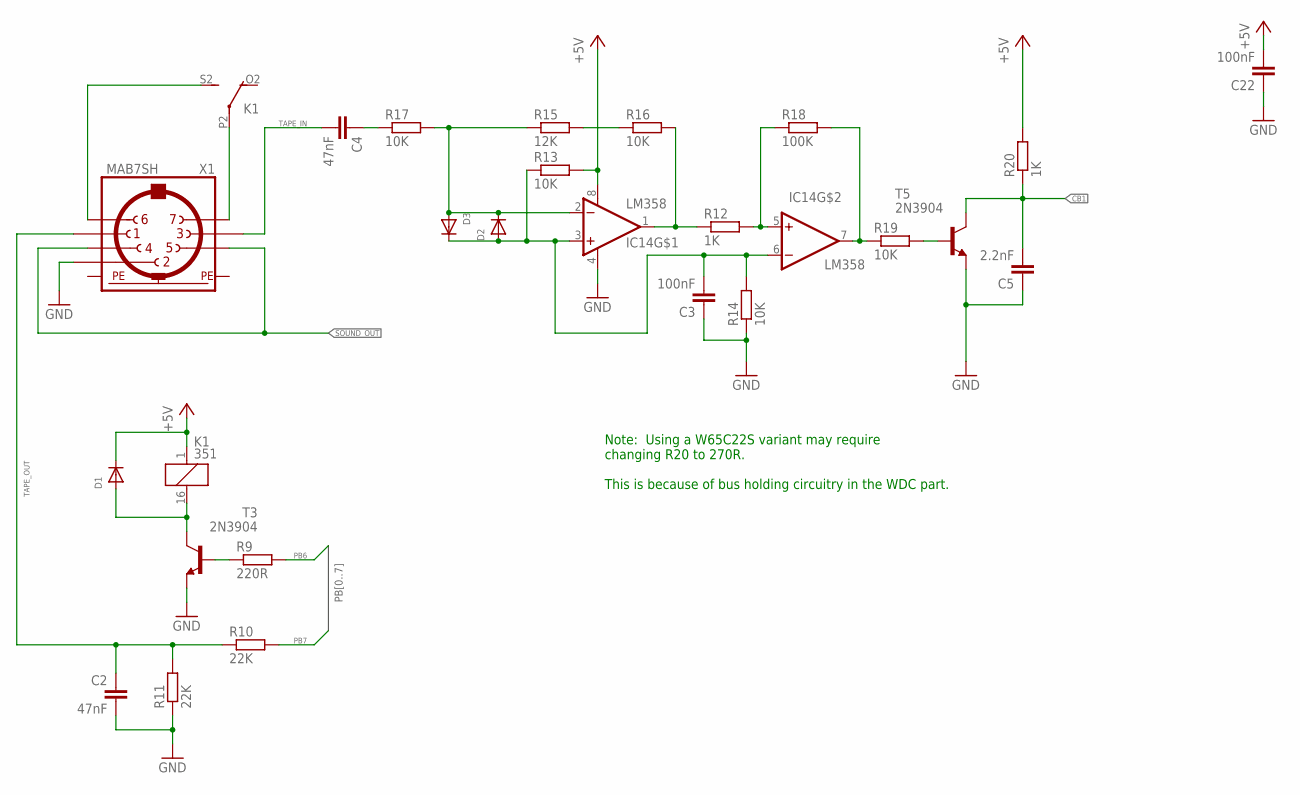
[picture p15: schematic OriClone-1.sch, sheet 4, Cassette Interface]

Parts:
C2, C4: 47nF; C050-025X075
C3, C22: 100nF; C050-025X075
C5: 2.2nF; C050-025X075
D1, D2, D3: DIODEDO-1N4148; DO-1N4148
IC14: LM358; DIP08
K1: 351
R9: 220R; 0207/10
R10, R11: 22K; 0207/10
R12, R20: 1K; 0207/10
R13: 10K; 0207/2V
R14: 10K; 0207/7
R15: 12K; 0207/10
R16, R17, R19: 10K; 0207/10
R18: 100K; 0207/10
T3, T5: 2N3904; TO92
X1: MAB7SH

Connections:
+5V: C22.2, D1.C, IC14.8 (V+), K1.1, R13.2, R20.2; also elsewhere on the board
CB1: C5.2, R20.1, T5.1 (C); also elsewhere on the board
GND: C2.1, C3.1, C5.1, C22.1, IC14.4 (V-), R11.1, R14.1, T3.3 (E), T5.3 (E), X1.2; also elsewhere on the board
unnamed: D1.A, K1.16 (2), T3.1 (C)
unnamed: IC14.5 (+IN), R12.2, R18.1
unnamed: R9.1, T3.2 (B)
unnamed: K1.S2 (S), X1.6
unnamed: K1.P2, X1.7
unnamed: IC14.1 (OUT), R12.1, R16.2
unnamed: R15.2, R16.1
unnamed: C4.1, R17.1
unnamed: IC14.7 (OUT), R18.2, R19.1
unnamed: D2.C, D3.A, IC14.2 (-IN), R15.1, R17.2
unnamed: C3.2, D2.A, D3.C, IC14.3 (+IN), IC14.6 (-IN), R13.1, R14.2
unnamed: R19.2, T5.2 (B)
PB6: R9.2; also elsewhere on the board
PB7: R10.2; also elsewhere on the board
PE: X1.PE, X1.PE@ (PE)
SOUND_OUT: X1.4, X1.5; also elsewhere on the board
TAPE_IN: C4.2, X1.3
TAPE_OUT: C2.2, R10.1, R11.2, X1.1

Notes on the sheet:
Note: Using a W65C22S variant may require changing R20 to 270R. This is because of bus holding circuitry in the WDC part.

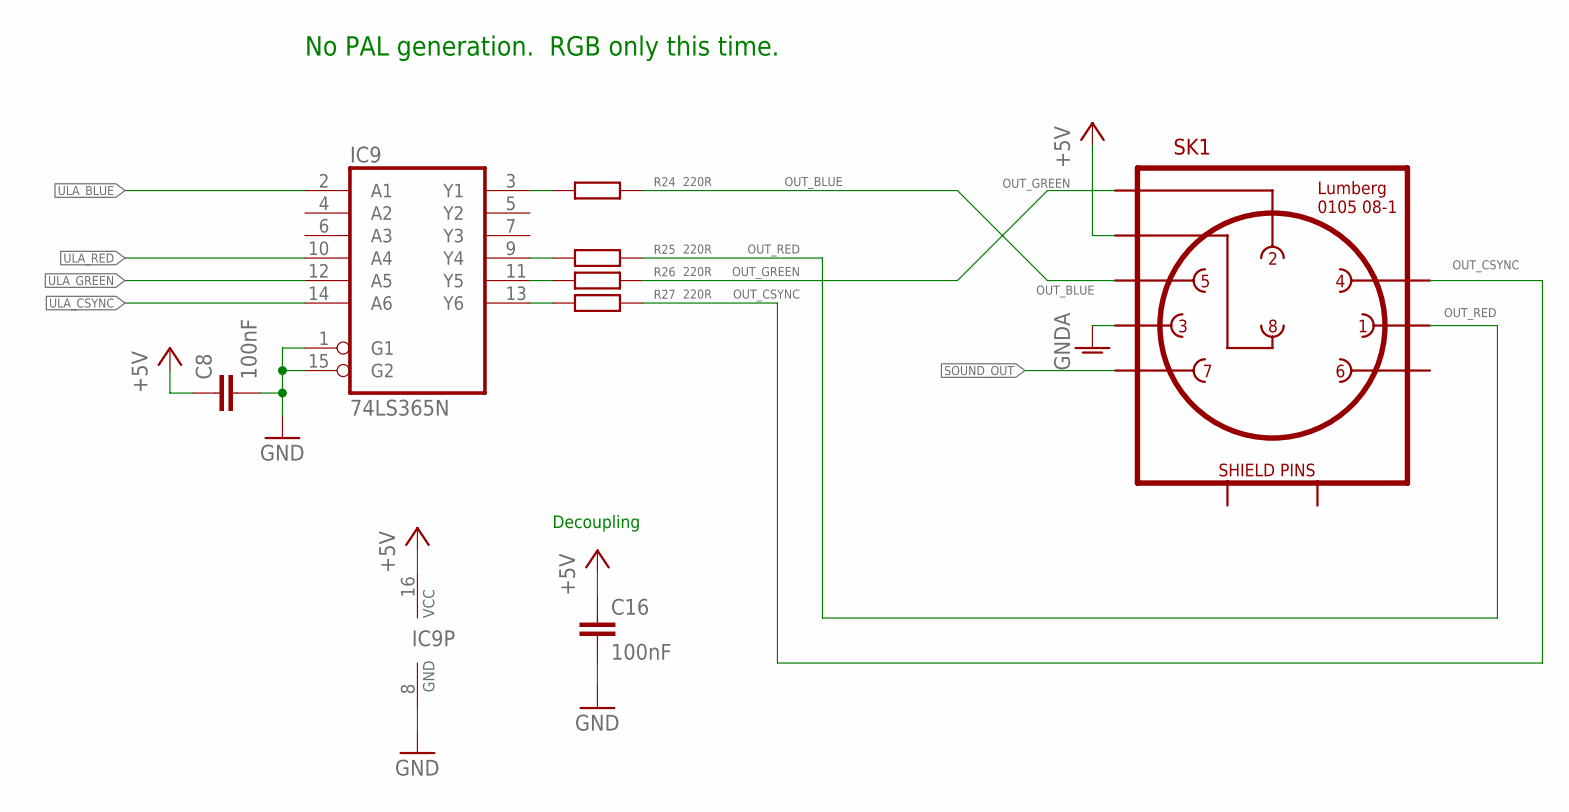
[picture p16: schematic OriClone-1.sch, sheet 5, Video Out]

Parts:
C8, C16: 100nF; C050-025X075
IC9: 74LS365N; DIL16
R24, R25, R26, R27: 220R; 0207/10
SK1: LUMBERG_DIN_0105_08-1; 0105-08-1

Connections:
+5V: C8.1, C16.1, IC9.16 (VCC), SK1.8; also elsewhere on the board
BUF_BLUE: IC9.3 (Y1), R24.1
BUF_CSYNC: IC9.13 (Y6), R27.1
BUF_GREEN: IC9.11 (Y5), R26.1
BUF_RED: IC9.9 (Y4), R25.1
GND: C8.2, C16.2, IC9.1 (G1), IC9.8 (GND), IC9.15 (G2), SK1.3; also elsewhere on the board
OUT_BLUE: R24.2, SK1.5
OUT_CSYNC: R27.2, SK1.4
OUT_GREEN: R26.2, SK1.2
OUT_RED: R25.2, SK1.1
SOUND_OUT: SK1.7; also elsewhere on the board
ULA_BLUE: IC9.2 (A1); also elsewhere on the board
ULA_CSYNC: IC9.14 (A6); also elsewhere on the board
ULA_GREEN: IC9.12 (A5); also elsewhere on the board
ULA_RED: IC9.10 (A4); also elsewhere on the board

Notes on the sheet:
No PAL generation. RGB only this time.
Decoupling

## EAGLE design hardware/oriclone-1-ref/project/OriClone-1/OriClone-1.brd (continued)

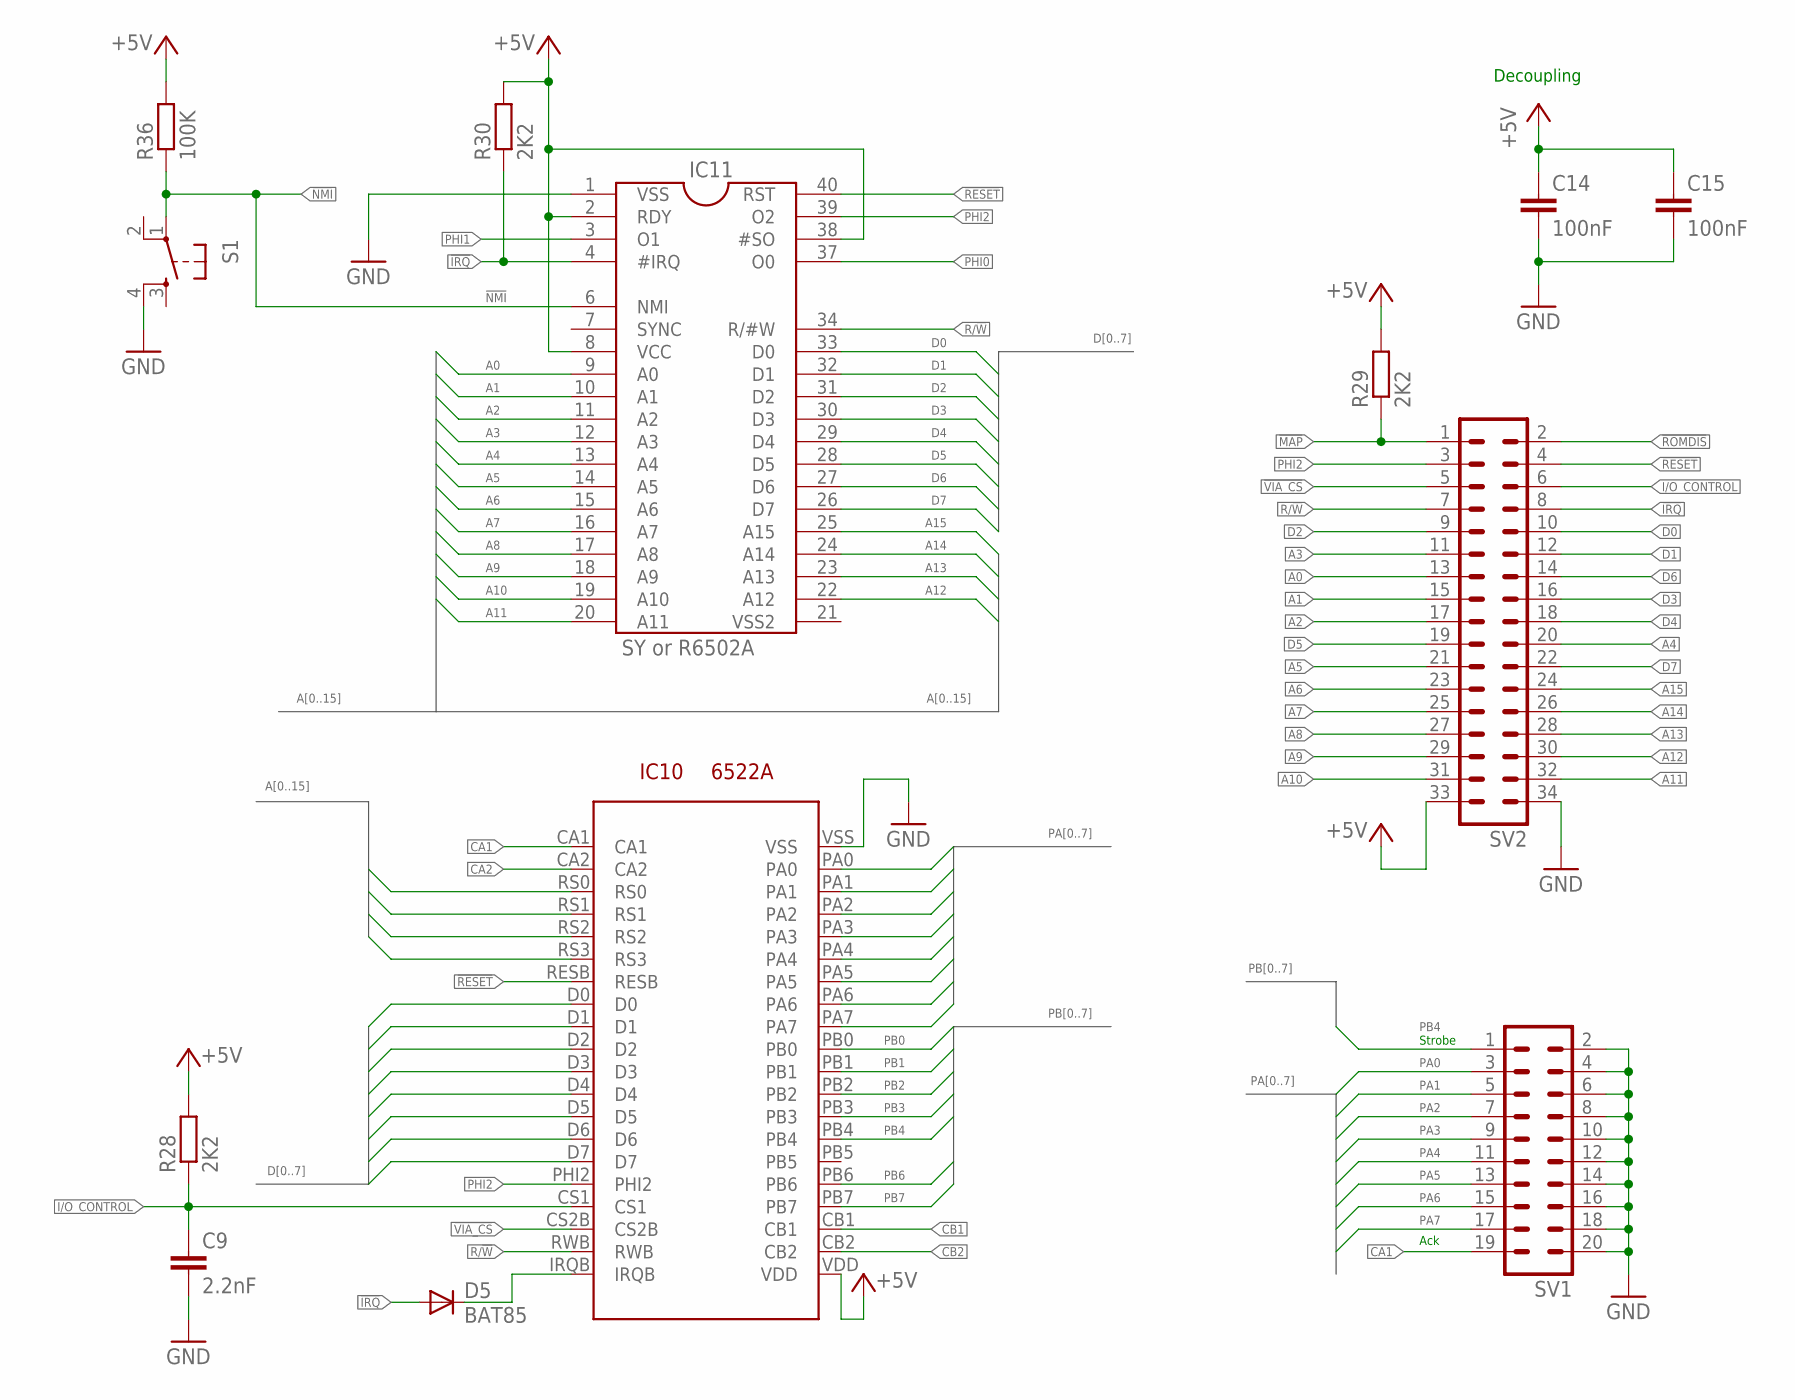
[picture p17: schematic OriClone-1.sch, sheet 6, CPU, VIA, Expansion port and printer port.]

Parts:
C9: 2.2nF; C050-025X075
C14, C15: 100nF; C050-025X075
D5: BAT85; DO34-7
IC10: 6522A; DIP
IC11: SY or R6502A; DIL40
R28, R29, R30: 2K2; 0207/10
R36: 100K; 0207/10
S1: TAC_SWITCHPTH; TACTILE-PTH
SV1: ML20L
SV2: ML34L

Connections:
!IRQ: D5.A, IC11.4 (#IRQ), R30.1, SV2.8
!MAP: R29.1, SV2.1; also elsewhere on the board
!NMI: IC11.6 (NMI), R36.1, S1.1
!RESET: IC10.RESB, IC11.40 (RST), SV2.4; also elsewhere on the board
!ROMDIS: SV2.2; also elsewhere on the board
!VIA_CS: IC10.CS2B, SV2.5; also elsewhere on the board
+5V: C14.1, C15.1, IC10.VDD, IC11.2 (RDY), IC11.8 (VCC), IC11.38 (#SO), R28.2, R29.2, R30.2, R36.2, SV2.33; also elsewhere on the board
A0: IC10.RS0, IC11.9 (A0), SV2.13; also elsewhere on the board
A1: IC10.RS1, IC11.10 (A1), SV2.15; also elsewhere on the board
A2: IC10.RS2, IC11.11 (A2), SV2.17; also elsewhere on the board
A3: IC10.RS3, IC11.12 (A3), SV2.11; also elsewhere on the board
A4: IC11.13 (A4), SV2.20; also elsewhere on the board
A5: IC11.14 (A5), SV2.21; also elsewhere on the board
A6: IC11.15 (A6), SV2.23; also elsewhere on the board
A7: IC11.16 (A7), SV2.25; also elsewhere on the board
A8: IC11.17 (A8), SV2.27; also elsewhere on the board
A9: IC11.18 (A9), SV2.29; also elsewhere on the board
A10: IC11.19 (A10), SV2.31; also elsewhere on the board
A11: IC11.20 (A11), SV2.32; also elsewhere on the board
A12: IC11.22 (A12), SV2.30; also elsewhere on the board
A13: IC11.23 (A13), SV2.28; also elsewhere on the board
A14: IC11.24 (A14), SV2.26; also elsewhere on the board
A15: IC11.25 (A15), SV2.24; also elsewhere on the board
CA1: IC10.CA1, SV1.19
CA2: IC10.CA2; also elsewhere on the board
CB1: IC10.CB1; also elsewhere on the board
CB2: IC10.CB2; also elsewhere on the board
D0: IC10.D0, IC11.33 (D0), SV2.10; also elsewhere on the board
D1: IC10.D1, IC11.32 (D1), SV2.12; also elsewhere on the board
D2: IC10.D2, IC11.31 (D2), SV2.9; also elsewhere on the board
D3: IC10.D3, IC11.30 (D3), SV2.16; also elsewhere on the board
D4: IC10.D4, IC11.29 (D4), SV2.18; also elsewhere on the board
D5: IC10.D5, IC11.28 (D5), SV2.19; also elsewhere on the board
D6: IC10.D6, IC11.27 (D6), SV2.14; also elsewhere on the board
D7: IC10.D7, IC11.26 (D7), SV2.22; also elsewhere on the board
GND: C9.2, C14.2, C15.2, IC10.VSS, IC11.1 (VSS), S1.4, SV1.2, SV1.4, SV1.6, SV1.8, SV1.10, SV1.12, SV1.14, SV1.16, SV1.18, SV1.20, SV2.34; also elsewhere on the board
I/O_CONTROL: C9.1, IC10.CS1, R28.1, SV2.6
unnamed: D5.C, IC10.IRQB
PA0: IC10.PA0, SV1.3; also elsewhere on the board
PA1: IC10.PA1, SV1.5; also elsewhere on the board
PA2: IC10.PA2, SV1.7; also elsewhere on the board
PA3: IC10.PA3, SV1.9; also elsewhere on the board
PA4: IC10.PA4, SV1.11; also elsewhere on the board
PA5: IC10.PA5, SV1.13; also elsewhere on the board
PA6: IC10.PA6, SV1.15; also elsewhere on the board
PA7: IC10.PA7, SV1.17; also elsewhere on the board
PB0: IC10.PB0; also elsewhere on the board
PB1: IC10.PB1; also elsewhere on the board
PB2: IC10.PB2; also elsewhere on the board
PB3: IC10.PB3; also elsewhere on the board
PB4: IC10.PB4, SV1.1
PB6: IC10.PB6; also elsewhere on the board
PB7: IC10.PB7; also elsewhere on the board
PHI0: IC11.37 (O0); also elsewhere on the board
PHI1: IC11.3 (O1); also elsewhere on the board
PHI2: IC10.PHI2, IC11.39 (O2), SV2.3; also elsewhere on the board
R/!W: IC10.RWB, IC11.34 (R/#W), SV2.7; also elsewhere on the board

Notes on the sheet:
Strobe
Ack
Decoupling

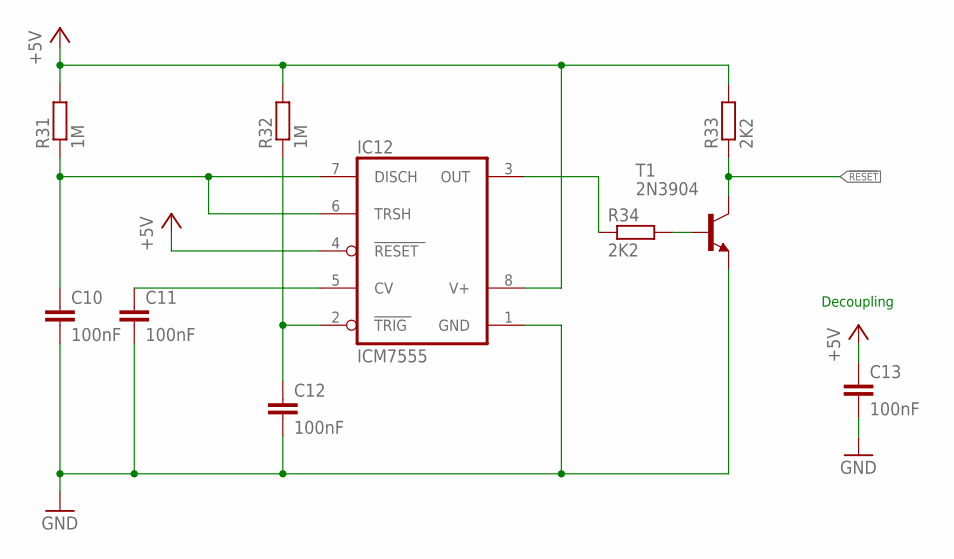
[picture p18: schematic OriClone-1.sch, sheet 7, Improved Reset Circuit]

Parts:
C10, C11, C12, C13: 100nF; C050-025X075
IC12: ICM7555; DIL08
R31, R32: 1M; 0207/2V
R33, R34: 2K2; 0207/10
T1: 2N3904; TO92

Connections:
!RESET: R33.1, T1.1 (C); also elsewhere on the board
+5V: C13.1, IC12.4 (RESET), IC12.8 (V+), R31.2, R32.2, R33.2; also elsewhere on the board
GND: C10.2, C11.2, C12.2, C13.2, IC12.1 (GND), T1.3 (E); also elsewhere on the board
unnamed: C10.1, IC12.6 (TRSH), IC12.7 (DISCH), R31.1
unnamed: C11.1, IC12.5 (CV)
unnamed: C12.1, IC12.2 (TRIG), R32.1
unnamed: R34.2, T1.2 (B)
unnamed: IC12.3 (OUT), R34.1

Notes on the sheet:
Decoupling


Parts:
C25: 100uF 25V 105C; E2,5-7
C26: 100nF; C050-025X075
IC13: 7805 or equivalent; TO220H
U$2: 2.1MMJACKTHM; PJ-102A

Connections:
+5V: C26.1, IC13.3 (VO); also elsewhere on the board
GND: C25.-, C26.2, IC13.2 (GND), U$2.RING, U$2.RING_SW; also elsewhere on the board
unnamed: C25.+, IC13.1 (VI), U$2.TIP

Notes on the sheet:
It is strongly reccomended that a switching equivalent is used. Board space to provide room for either including heatsink space.


Board: 2 copper layers, 206.5 x 138.0 mm, 94 parts (1 on the bottom side), 138 nets.

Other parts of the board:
U$3: ORICLONE-1

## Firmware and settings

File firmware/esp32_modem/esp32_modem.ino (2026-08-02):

/*
 * esp32_modem — modem WiFi « Hayes » pour l'Oric sur ULX3S (US-MODEM phase 2).
 *
 * Ponte l'UART venant du 6551 ACIA du FPGA ($031C-$031F) vers une connexion
 * TCP/telnet en WiFi. L'Oric parle au 6551 comme à un modem RS-232 ; ce
 * firmware interprète les commandes AT et ouvre les connexions.
 *
 * Liaison FPGA <-> ESP32 (cf. top_ulx3s.v / LPF ULX3S) :
 *   FPGA wifi_rxd (K3)  --->  ESP32 RX   (le FPGA émet, l'ESP32 reçoit)
 *   FPGA wifi_txd (K4)  <---  ESP32 TX   (l'ESP32 émet, le FPGA reçoit)
 *   FPGA wifi_en        --->  ESP32 EN   (maintenu haut par le FPGA)
 * ⚠️ Vérifier le mappage GPIO exact de l'UART côté ESP32 sur le schéma ULX3S
 *    (voir README). Par défaut on utilise UART0 (Serial, GPIO1/3), qui est la
 *    liaison standard ESP32<->FPGA de l'ULX3S. Si conflit console, basculer
 *    sur un UART secondaire (voir LINK ci-dessous).
 *
 * SCAFFOLD : à compiler et flasher par bmarty (voir README). Non compilé/testé
 * dans ce dépôt (pas de toolchain ESP32 ici).
 */

#include <WiFi.h>
#include <Preferences.h>

// ---------------------------------------------------------------------------
// Configuration
// ---------------------------------------------------------------------------
static const uint32_t LINK_BAUD = 115200;   // doit matcher uart_tx/uart_rx du FPGA

// UART vers le FPGA. Par défaut UART0 (Serial). Pour un UART dédié, remplacer
// par :  HardwareSerial Link(2); ... Link.begin(LINK_BAUD, SERIAL_8N1, RXPIN, TXPIN);
HardwareSerial& Link = Serial;

static const uint16_t DEF_PORT = 23;        // telnet par défaut
Preferences prefs;

// ---------------------------------------------------------------------------
// État
// ---------------------------------------------------------------------------
WiFiClient client;
bool   online   = false;      // true = mode « en ligne » (données transparentes)
bool   echoOn   = true;       // ATE1/ATE0
bool   verbose  = true;       // ATV1 : réponses texte ; ATV0 : codes numériques
bool   telnetStrip = true;    // filtre les négociations IAC (telnet)
String cmdLine;

// Détection de la séquence d'échappement +++ (garde ~1 s)
uint8_t  plusCount = 0;
uint32_t lastPlus  = 0;
uint32_t lastLinkActivity = 0;

// ---------------------------------------------------------------------------
// Réponses (style Hayes)
// ---------------------------------------------------------------------------
void resp(const char* verboseMsg, int code) {
    Link.print("\r\n");
    if (verbose) { Link.print(verboseMsg); Link.print("\r\n"); }
    else         { Link.print(code);       Link.print("\r"); }
}
void respOK()        { resp("OK", 0); }
void respERROR()     { resp("ERROR", 4); }
void respCONNECT()   { resp("CONNECT", 1); }
void respNOCARRIER() { resp("NO CARRIER", 3); }

// ---------------------------------------------------------------------------
// WiFi
// ---------------------------------------------------------------------------
bool wifiConnect(uint32_t timeoutMs = 15000) {
    String ssid = prefs.getString("ssid", "");
    String pass = prefs.getString("pass", "");
    if (ssid.isEmpty()) return false;
    WiFi.mode(WIFI_STA);
    WiFi.begin(ssid.c_str(), pass.c_str());
    uint32_t t0 = millis();
    while (WiFi.status() != WL_CONNECTED && millis() - t0 < timeoutMs) delay(100);
    return WiFi.status() == WL_CONNECTED;
}

// ---------------------------------------------------------------------------
// Numérotation : ATDT host[:port]
// ---------------------------------------------------------------------------
void dial(String target) {
    target.trim();
    if (target.isEmpty()) { respERROR(); return; }
    if (WiFi.status() != WL_CONNECTED && !wifiConnect()) { respNOCARRIER(); return; }

    uint16_t port = DEF_PORT;
    int colon = target.lastIndexOf(':');
    String host = target;
    if (colon > 0) { host = target.substring(0, colon); port = target.substring(colon + 1).toInt(); }

    if (client.connect(host.c_str(), port)) {
        online = true;
        respCONNECT();          // porteuse en bande ; DCD matériel = TODO (voir README)
    } else {
        respNOCARRIER();
    }
}

void hangup() {
    if (client.connected()) client.stop();
    online = false;
    respNOCARRIER();
}

// ---------------------------------------------------------------------------
// Analyse d'une commande AT
// ---------------------------------------------------------------------------
void handleAT(String line) {
    line.trim();
    if (line.length() < 2 || line.substring(0, 2) != "AT") {
        if (line.isEmpty()) return;   // ligne vide : rien
        respERROR(); return;
    }
    String rest = line.substring(2);
    rest.toUpperCase();

    // Bare "AT"
    if (rest.isEmpty()) { respOK(); return; }

    // Commandes multiples simples
    if (rest.startsWith("DT") || rest.startsWith("D")) {   // ATDT / ATD
        int idx = rest.startsWith("DT") ? 2 : 1;
        // On récupère la cible depuis la ligne ORIGINALE (casse préservée)
        dial(line.substring(2 + idx));
        return;
    }
    if (rest == "H" || rest == "H0")            { hangup(); return; }
    if (rest == "O" || rest == "O0")            { if (client.connected()) { online = true; respCONNECT(); } else respNOCARRIER(); return; }
    if (rest == "E0") { echoOn = false; respOK(); return; }
    if (rest == "E1") { echoOn = true;  respOK(); return; }
    if (rest == "V0") { verbose = false; respOK(); return; }
    if (rest == "V1") { verbose = true;  respOK(); return; }
    if (rest == "Z"  || rest == "Z0")           { hangup(); respOK(); return; }  // reset léger
    if (rest.startsWith("I"))                   { Link.print("\r\nESP32 WiFi Modem (Oric ULX3S)\r\n"); respOK(); return; }

    // Config WiFi (custom) : AT$SSID=..., AT$PASS=..., AT$C (connect), AT$W (état)
    if (rest.startsWith("$SSID=")) { prefs.putString("ssid", line.substring(2 + 6)); respOK(); return; }
    if (rest.startsWith("$PASS=")) { prefs.putString("pass", line.substring(2 + 6)); respOK(); return; }
    if (rest == "$C")   { bool ok = wifiConnect(); resp(ok ? "WIFI OK" : "WIFI FAIL", ok ? 0 : 4); return; }
    if (rest == "$W")   {
        Link.print("\r\nSSID: "); Link.print(prefs.getString("ssid", "(vide)"));
        Link.print("\r\nIP:   "); Link.print(WiFi.localIP());
        Link.print("\r\n"); respOK(); return;
    }

    respERROR();
}

// ---------------------------------------------------------------------------
// Mode « en ligne » : pont transparent série <-> TCP
// ---------------------------------------------------------------------------
void pumpOnline() {
    // TCP -> FPGA (avec filtrage telnet IAC optionnel)
    while (client.available()) {
        int b = client.read();
        if (telnetStrip && b == 0xFF) {           // IAC : refuser toute négociation
            int cmd = client.read();
            if (cmd == 0xFF) { Link.write(0xFF); } // IAC IAC = 0xFF littéral
            else {                                  // WILL/WONT/DO/DONT + option
                int opt = client.read();
                (void)opt;                          // on ignore (pas de réponse -> minimal)
            }
            continue;
        }
        Link.write(b);
    }
    // FPGA -> TCP
    while (Link.available()) {
        uint8_t b = Link.read();
        lastLinkActivity = millis();
        // Détection +++ (uniquement en ligne)
        if (b == '+') {
            if (plusCount == 0 && millis() - lastLinkActivity > 900) plusCount = 1;
            else plusCount++;
            lastPlus = millis();
            if (plusCount >= 3) { /* validé après le temps de garde, cf. loop() */ }
        } else {
            plusCount = 0;
        }
        client.write(b);
    }
    if (!client.connected()) { online = false; respNOCARRIER(); }
}

// ---------------------------------------------------------------------------
// Mode commande : accumulation de la ligne AT
// ---------------------------------------------------------------------------
void pumpCommand() {
    while (Link.available()) {
        char c = Link.read();
        if (echoOn) Link.write(c);
        if (c == '\r' || c == '\n') {
            if (cmdLine.length()) { handleAT(cmdLine); cmdLine = ""; }
        } else if (c == 8 || c == 127) {           // backspace
            if (cmdLine.length()) cmdLine.remove(cmdLine.length() - 1);
        } else if (cmdLine.length() < 128) {
            cmdLine += c;
        }
    }
}

// ---------------------------------------------------------------------------
// Setup / loop
// ---------------------------------------------------------------------------
void setup() {
    Link.begin(LINK_BAUD);
    prefs.begin("modem", false);
    delay(200);
    resp("ESP32 WiFi Modem pret", 0);   // bannière au boot
}

void loop() {
    if (online) {
        pumpOnline();
        // Validation de l'échappement +++ après le temps de garde (~1 s sans data)
        if (plusCount >= 3 && millis() - lastPlus > 900) {
            plusCount = 0; online = false; respOK();   // retour en mode commande, connexion maintenue
        }
    } else {
        pumpCommand();
    }
}

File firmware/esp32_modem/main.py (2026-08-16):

# Modem Hayes WiFi pour l'ESP32 interne de l'ULX3S (MicroPython 1.14).
# Tourne sur l'UART0 (= pont FPGA wifi_rxd/txd = 6551 de l'Oric, 115200).
# Installé via le REPL (tools/esp32/install_main.py) — PAS de flash esptool.
#
# Jeu de commandes : sous-ensemble COMPATIBLE PicoWiFiModemUSB (~/picowifi,
# lignée mecparts/RetroWiFiModem) pour que l'Oric parle la même langue au
# modem interne et au Pico W de la LOCI :
#   AT            OK
#   AT?           aide
#   ATI           état (SSID, IP, RSSI)
#   ATE0/ATE1/ATE?  écho commande
#   AT$SSID=nom   / AT$SSID?     réseau WiFi
#   AT$PASS=mdp   / AT$PASS?     mot de passe (affiché masqué)
#   ATC1 / ATC0 / ATC?           connexion WiFi on/off/état
#   AT&W          sauve SSID/PASS (wifi.txt, rejoint au boot)
#   AT&F          efface la config
#   ATDT host[:port]             appel TCP (port 23 défaut) -> CONNECT
#   +++ (garde 1 s)              retour mode commande
#   ATO           retour en ligne     ATH  raccroche -> NO CARRIER
#   ATGET http://hote[/page]     GET simple, affiche la page, raccroche
#   ATZ           reset du modem (machine.reset)
# Ctrl-C au REPL : interrompt le modem et rend la main à MicroPython.

import sys
import time
import select
import socket
import network
import machine

VERSION = "ULX3S-ORIC ESP32 MODEM 0.2 (MicroPython, cmds PicoWiFiModem)"

wlan = network.WLAN(network.STA_IF)
wlan.active(True)

poller = select.poll()
poller.register(sys.stdin, select.POLLIN)
net_poll = select.poll()          # surveille la socket réseau (lisible ?)

echo = True
sock = None
online = False
is_tls = False        # socket courante enveloppée TLS (ussl) ?
ssid = ""
password = ""


def sock_write(d):
    # SSL utilise write(), TCP brut utilise send()
    return sock.write(d) if is_tls else sock.send(d)

# Telnet : on répond aux négociations IAC (refus de toutes les options) et on
# les retire de l'affichage -> terminal propre. ATNET0 = mode brut (IAC passés
# tels quels, ex. transfert XMODEM binaire). État persistant entre les recv.
tn_on = True
_tn_st = 0            # 0 normal, 1 IAC, 2 option, 3 SB, 4 SB+IAC
_tn_cmd = 0


def telnet_reset():
    global _tn_st, _tn_cmd
    _tn_st = 0
    _tn_cmd = 0


def telnet_filter(data):
    global _tn_st, _tn_cmd
    if not tn_on:
        return data
    out = bytearray()
    resp = bytearray()
    for b in data:
        if _tn_st == 0:
            if b == 0xFF:
                _tn_st = 1
            else:
                out.append(b)
        elif _tn_st == 1:
            if b == 0xFF:            # IAC IAC = 0xFF littéral
                out.append(0xFF); _tn_st = 0
            elif 0xFB <= b <= 0xFE:  # WILL/WONT/DO/DONT
                _tn_cmd = b; _tn_st = 2
            elif b == 0xFA:          # SB
                _tn_st = 3
            else:
                _tn_st = 0
        elif _tn_st == 2:            # octet d'option -> refuser
            if _tn_cmd == 0xFD:      # DO x   -> WONT x
                resp += bytes((0xFF, 0xFC, b))
            elif _tn_cmd == 0xFB:    # WILL x -> DONT x
                resp += bytes((0xFF, 0xFE, b))
            _tn_st = 0
        elif _tn_st == 3:            # sous-négociation
            if b == 0xFF:
                _tn_st = 4
        elif _tn_st == 4:
            _tn_st = 0 if b == 0xF0 else 3   # IAC SE = fin
    if resp and sock:
        try:
            sock_write(resp)
        except Exception:
            pass
    return bytes(out)


# Sortie octets BRUTS : MicroPython ne supporte que le codec UTF-8, donc
# data.decode("latin-1") LÈVE UnicodeError sur un octet >=0x80 (ex. telnet
# IAC 0xFF). On écrit les octets directement via sys.stdout.buffer.
_rawout = getattr(sys.stdout, "buffer", None)
def wbytes(data):
    if _rawout:
        _rawout.write(data)
    else:
        for b in data:
            sys.stdout.write(chr(b) if b < 0x80 else "?")


def crlf(s=""):
    sys.stdout.write(s + "\r\n")


def load_cfg():
    global ssid, password
    try:
        f = open("wifi.txt")
        ssid = f.readline().strip()
        password = f.readline().strip()
        f.close()
    except OSError:
        pass


def save_cfg():
    f = open("wifi.txt", "w")
    f.write(ssid + "\n" + password + "\n")
    f.close()


def wifi_connect():
    if not ssid:
        return False
    if wlan.isconnected():
        return True
    wlan.connect(ssid, password)
    for _ in range(120):            # ~12 s
        if wlan.isconnected():
            return True
        time.sleep_ms(100)
    return False


def hangup(report=True):
    global sock, online, is_tls
    if sock:
        try:
            net_poll.unregister(sock)
        except Exception:
            pass
        try:
            sock.close()
        except Exception:
            pass
    sock = None
    online = False
    is_tls = False
    if report:
        crlf("NO CARRIER")


def dial(arg):
    global sock, online, is_tls
    host = arg.strip()
    tls = False
    if host.startswith("#"):          # ATDT#host = dial sécurisé TLS (picowifi)
        tls = True
        host = host[1:].strip()
    port = 443 if tls else 23
    if ":" in host:
        host, p = host.rsplit(":", 1)
        try:
            port = int(p)
        except ValueError:
            crlf("ERROR")
            return
    if not wifi_connect():
        crlf("NO CARRIER")
        return
    try:
        s = socket.socket()
        s.connect(socket.getaddrinfo(host, port)[0][-1])
        if tls:
            # handshake TLS en bloquant, PUIS passage non-bloquant. Les sockets
            # SSL n'acceptent pas select.poll de façon fiable sur MicroPython :
            # la boucle online lit en non-bloquant à chaque tour (read()->None
            # si rien).
            import ussl
            s = ussl.wrap_socket(s, server_hostname=host)
            s.setblocking(False)
        else:
            s.setblocking(False)
            net_poll.register(s, select.POLLIN)
        sock = s
        is_tls = tls
        online = True
        telnet_reset()
        crlf("CONNECT")
    except Exception:
        crlf("NO CARRIER")
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

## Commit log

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2026-07-29 Correctif majeur: protocole bus 6502 sous RDY re-temporisé
    Le core d'Arlet ne garantit AB/WE/DO que pendant la phase RDY.
    Capture AB/WE/DO au front cen1, fetch au cycle suivant, DI verrouillé
    à t4 — équivalence démontrée avec l'environnement natif du core
    (trace instruction par instruction, sim/tb_trace.v).
    Tests unitaires VIA/clavier/ULA re-validés.
2026-07-29 Sprint 2 (v1.1.0): clavier série UART depuis le PC + fix HDMI TMDS
    - uart_rx 115200 8N1 sur US1 + key_injector (FIFO 256, table ASCII->matrice
    des tables ROM $FF70/$FFB0, frappe 45ms, Shift auto, CR/LF dédupliqués)
    - Entrée d'injection dans oric_keyboard/oric_atmos/top
    - Fix HDMI: chargement TMDS aligné en phase sur clk_pixel (perte de synchro
    intermittente selon la phase PLL au démarrage)
    - tb_injector + suite complète: 5/5 PASS (dont boot ROM)
    - docs/CLAVIER_SERIE.md
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2026-07-29 Fix ULA v1.1.1: charset des rangées basses en HIRES + clignotement
    - chr_base suit vmode[2] (mode global) : en HIRES les 3 rangées texte du
    bas lisent $9800/$9C00 comme la référence (blanc-sur-blanc corrigé)
    - blink = inversion périodique (XOR bit7), pas un masquage
    - tb_ula étendu (scénario HIRES) : PASS
2026-07-29 Sprint 3: port d'extension Oric sur GPIO ULX3S (cible LOCI)
    - expansion_port.v: bus 6502 complet sur gp/gn (A sur gp0-10+18-22,
    D sur gn0-7, controles gn8-10+18-22, zones ESP32/ADC évitées)
    - Sémantique - fidèle: ROM / RAM cachée (/ROMDIS) /
    cartouche (/ROMDIS+/MAP); /IOCTRL inhibe la VIA; /RESET drain ouvert
    (bouton reset LOCI fonctionnel); VIA restreinte à /bin/bash300-/bin/bash30F
    - Brochage officiel annexe 11 du manuel Atmos transcrit dans
    docs/PORT_EXTENSION.md avec table de câblage Dupont + TXS0108E
    - tb_expansion (cartouche comportementale): PASS
    [tb_expansion.v]
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2026-07-29 Phase A: import SES scripté (parseur s-expression, l'import natif KiCad échoue), R8 hystérésis ajoutée au PCB, rendu visuel OK, passe 2 de routage en cours (freerouting 2.2.4/JDK25, bug -mp contourné)
    [phaseA.kicad_pcb, phaseA_r2.dsn]
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2026-07-29 Phase A: carte agrandie 160x56 (autoroute sud pour le fan-out header), outillage complet de routage (A* nom-de-net, import SES, boucle de re-routage), diagnostics (bug freerouting: omission silencieu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
    [phaseA.dsn, phaseA.kicad_pcb, phaseA_fr.dsn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]
2026-07-29 Phase A: PCB routé (144/144 signaux dont 2 tronçons à finir au push-and-shove), 0 erreur DRC, exports fab complets
    - Routage final: freerouting 1.9 (DISPLAY local) + A* maison (relais + queues
    validées) + 61 vias de couture GND + suppression d'îlots
    - Bugs routeurs documentés et contournés: 2.2.4 omission silencieuse de nets
    (paires de doigts coïncidentes), crash sur ':' dans les noms d'images DSN,
    1.9 headless impossible (HeadlessException)
    - Exports: gerbers+perçage, BOM.csv (16 refs), CPL.csv (32 CMS), rendus PNG
    - Reste: tronçon central RST5_n et IRQ5_n (queues posées), artefact de
    comptage GND à inspecter en GUI
    [BOM.csv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]
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2026-07-29 Portage Gowin Tang Nano 20K: video 576p50 verrouillée (doubleur de lignes, VERIFIE en sim: trames ULA=HDMI=539136 cycles), TMDS OSER10, rPLL 27->135, clavier BL616, cst, Makefile (ALU renommé: collis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
2026-08-02 Clavier AZERTY: corrige le Shift synthetise intermittent (& -> 7)
    Symptome sur carte: taper la touche 1 en AZERTY donnait &&7&&&&7.
    Sur l'Oric & = Shift+7; le Shift synthetise (derive du meme scancode)
    montait exactement en meme temps que la touche, et le scan clavier de la
    ROM attrapait parfois la touche seule. Diagnostic confirme par bmarty: le
    Shift PHYSIQUE (qui precede la touche) est fiable, le synthetise non.
    Les glyphes AZERTY a Shift sont desormais sequences par une FSM dans
    oric_keyboard.v: LEAD (Shift presente avant la touche, ~20 ms) -> HOLD
    (Shift + touche, maintien minimal garanti pour etre vu par >=1 balayage)
    -> TAIL (Shift prolonge au relache, ~10 ms), comme un vrai doigt. L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
    [tb_azerty.v]
2026-08-02 Clavier AZERTY: rangee du haut en chiffres directs + fin du repli QWERTY parasite
    Bug signale sur carte: en AZERTY, la touche accentuee (ex. « 2 »/é)
    donnait le chiffre QWERTY meme avec Shift. Cause: les glyphes hors ASCII
    (é è à ç ù ° £ § µ) renvoyaient 0 et key_map retombait sur la table
    positionnelle QWERTY.
    - azerty_map renvoie desormais {reconnue, ASCII} : une touche AZERTY a
    glyphe hors ASCII ne produit RIEN, sans repli parasite.
    - Choix ergonomique (bmarty): rangee du haut en CHIFFRES DIRECTS
    (1 2 3 4 5 6 7 8 9 0 sans Shift), symboles en Shift. Plus pratique pour
    le BASIC; les accents restent indisponibles (l'Oric ne les affiche pas).
    - tb_azerty: chiffres directs i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
    [tb_azerty.v]
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2026-08-02 Outillage ESP32 : flux robuste passthru-en-flash + retry (US-MODEM)
    Le flash direct (passthru SRAM + esptool auto-reset) echoue sur v3.0.8
    (Invalid head of packet 0x08 : autoexec ESP32 bavard, download mode non
    atteint). Ajout du flux documente emard :
    - flash.sh : baud upload 115200 + retry x6 (reco officielle "retry until
    Hash of data verified").
    - upload.sh : upload-seul avec retry (passthru deja en flash).
    - Makefile : esp32-passthru-flash (passthru en config flash, persistant),
    esp32-upload, oric-flash (restaure l'Oric en flash).
    Aucun RTL modifie.
    [esp32_modem.ino]
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2026-08-02 Outillage ESP32 : flash via esptool ancien (contourne regression reset >=4.6)
    esptool 5.3.1 (core Arduino) n'entre pas en download mode via le passthru
    (Invalid head of packet 0x08 constant) : esptool >=4.6 utilise UnixTightReset
    (impulsions trop courtes). Ajout de flash-esptool.sh : venv isole + esptool
    pinne (ESPTOOL_VERSION, defaut 4.5.1, reset classique a impulsions longues),
    ecrit les binaires arduino-cli (bootloader/partitions/boot_app0/app) avec
    --before default_reset, retry x6. Cible make esp32-flash-classic.
    gitignore : venv/out. Aucun RTL modifie.
2026-08-02 Outillage ESP32 : bitstream download maison (force GPIO0 bas) + flash no_reset
    Diagnostic (capture serie vide + boot au lieu de download sur reset) : le
    passthru officiel pulse EN mais ne TIENT PAS GPIO0 bas sur cette carte v3.0.8,
    donc l'ESP32 reboote en mode normal (Invalid head of packet 0x08 constant,
    independant de la version d'esptool).
    Parade : rtl/download_esp32.v — bitstream utilitaire qui ponte l'UART FTDI<->
    ESP32 ET tient wifi_gpio0 bas + pulse wifi_en (bas ~0,34s puis haut) : au
    front montant d'EN, GPIO0 bas => mode download deterministe. Puis
    tools/esp32/flash-download.sh flashe avec esptool --before no_reset (la puce
    est deja en attente, plus besoin du reset DTR/RTS defaill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
2026-08-02 Backlog: ESP32 interne non flashable (v3.0.8), issue = ESP32 externe
    Constat apres investigation exhaustive : le FPGA ne peut pas forcer le mode
    download de l'ESP32 interne sur cette carte v3.0.8 (GPIO0 non tenable bas ;
    gestion ajoutee seulement en v3.1.7/R56). US-MODEM.2 marque bloque, ajout de
    US-MODEM.2b (ESP32 externe : repointer le pont UART du 6551 vers gp[]).
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2026-08-07 Son sur HDMI : audio dans les data islands (US-HDMI-AUDIO)
    Le son de l'AY-3-8912 sort désormais par le câble HDMI (data islands),
    en plus du jack 3,5 mm conservé. Réécriture en Verilog-2005 de la logique
    standard HDMI (le module de référence hdl-util est en SystemVerilog,
    incompatible avec le flow yosys/iverilog).
    Modules :
    - hdmi_tmds_channel : encodeur TMDS 3 modes (control/video/data island TERC4
    + guard bands), non-régression bit-exacte vs l'ancien tmds_encoder.
    - hdmi_packet_assembler : ECC BCH (0x83) + framing/sérialisation sur 32 pixels.
    - hdmi_audio_packets : ACR (N/CTS 32 kHz), Audio InfoFrame, Audio Sample
    Packet (1-4 échantillons IEC60958), AVI InfoFrame (RGB, VIC=0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
2026-08-07 Carte SD : intégration top + validation sur carte (US-SDCARD incr 1)
    Câblage du pilote SD sur le lecteur micro-SD de l'ULX3S en mode SPI
    (sck=sd_clk, mosi=sd_cmd, miso=sd_d[0], cs=sd_d[3], sd_d[1:2] hauts).
    Test au boot : lecture du secteur 0, LEDs = octet `status` du pilote
    (0xAA = init OK + secteur lu + signature 0x55AA valide).
    Confirmé sur carte réelle (LEDs 0xAA) : la vraie micro-SD s'initialise et
    le secteur 0 est lu correctement. Makefile : modules SD ajoutés à la
    synthèse. Affichage LED de vie temporairement réquisitionné pour le test.
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2026-08-07 OSD liste des jeux + fix chargement SD (US-SDCARD incr 3 + correctif)
    OSD (rtl/osd.v) : incrustation de la liste des fichiers SD par-dessus la
    vidéo (police 8x8 roms/font8x8.hex générée par tools/gen_font.py), zoom x2,
    interligne, curseur sur le fichier sélectionné. fat32 : 2e port de lecture
    (q2) pour l'OSD. hdmi_out : incrustation avant l'encodeur TMDS. Navigation
    BTN3/BTN4 déjà en place.
    Correctif chargement (blocage "LOADING" figé, LED sd_status=0x80) :
    - tape_loader : compteur de crédits élargi à 16 bits — le tape_injector
    envoie une rafale de ~256 crédits (FIFO), le compteur 8 bits débordait et
    se coinçait à 0. tb_tape_loader reproduit désormais le FIFO 256 (éc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
    [sd_spi.v]
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2026-08-10 Backlog: US-ULA-NG.8 mode turbo 6502 (NG_TURBO)
    Registre NG_TURBO dans la fenêtre ULA-NG (déverrouillage NG requis) :
    horloge CPU 1 MHz fidèle par défaut → 8/16 MHz+ (RAM/ROM BRAM sans
    wait state). VIA, AY et cassette restent au 1 MHz réel (musique,
    délais, IRQ timer inchangés), synchronisation des franchissements de
    domaine CPU↔périphériques. Retour 1 MHz sur reset. Retenu comme
    alternative au 65C816 dans ce projet (chimère = ~/oric2).
2026-08-10 Chargement SD : fix du protocole fdata (handshake valid/ready) — VALIDÉ SUR CARTE
    Cause du point ouvert : fat32 émettait un octet à chaque cycle où
    fdata_ready était haut, alors que tape_loader le tenait haut 2-3 cycles
    par crédit → rafale de 2-3 octets par crédit + underflow 16 bits du
    compteur de crédits (65535 crédits fantômes) → contrôle de flux mort →
    débordement de la FIFO du tape_injector → données corrompues, l'Oric
    coupait le moteur. fat_dump avait le bug inverse (pulse ready perdu
    pendant la lecture du secteur suivant → blocage frontière de secteur).
    Correctif : handshake valid/ready standard (transfert au cycle où les
    deux sont hauts, exactement un octe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
2026-08-10 Doc : limitation jeux à loader protégé (citadel.tap) en mode signal
    Diagnostic 2026-08-11 : « Errors found » sur Citadel — identique dans
    l'émulateur de référence en --tape-signal (fichier sain, --fast-load
    OK). Loader maison Loriciels (bloc 1 autorun rechargeant la suite par
    sa propre routine) incompatible avec la reconstruction signal du .tap.
    Pas une régression du RTL. Issues futures : fast-load FPGA (lié à la
    ROM patchée US-ULA-NG.6) ou version disquette (US-DISK).
2026-08-10 Turbo (point ouvert) + tb_cload + diagnostic Citadel (ROM 1.0 requise)
    - Turbo US-ULA-NG.8 : domaine cen1 commutable 1→4,17 MHz + cassette au
    même ratio, activé par tape_active. Tests/timing verts mais CLOAD
    reste en « Searching » sur carte — point ouvert, instrumentation en
    cours (tb_cload : banc bout-en-bout boot + frappe CLOAD + cassette,
    qui valide le mode normal).
    - Citadel : loader protégé vérifiant l'empreinte ROM (/) et
    sautant dans les entrailles de la ROM. Incompatible 1.1b (décalée).
    PROUVÉ en émulateur : ROM 1.0 + amorce inter-blocs (notre RTL) =
    Citadel charge. Prise en charge via banque ROM 1.0 (US-ULA-NG.1).
    L'insertion d'amorce serait aussi util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
2026-08-11 ROM 2 banques (1.1b + 1.0) sur BTN5 — Citadel VALIDÉ SUR CARTE
    US-ULA-NG.1 première tranche : oric_rom.v héberge 2 banques de 16 Ko
    (banque 0 = BASIC 1.1b défaut, banque 1 = BASIC 1.0 depuis la ROM de
    l'émulateur, roms/basic10.hex). BTN5 (gauche) bascule + reset ~5 ms ;
    vérif banque : PRINT PEEK(#FFF9). tb_boot boote les deux banques
    (+bank=1). Makefile : basic10.hex en dépendance.
    Validation carte (2026-08-11) : Citadel — loader protégé Loriciels
    vérifiant la révision ROM — charge ses 4 blocs sur la banque 1.0
    jusqu'au « Choix des couleurs » (amorce inter-blocs indispensable).
    Bitstream gravé en flash SPI.
    Limitation notée : bascule = warm-boot silencieux (pas de bann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
2026-08-12 Turbo chargement cassette (US-ULA-NG.8) — VALIDÉ SUR CARTE
    Pendant tape_active : domaine cen1 (CPU+VIA+AY) 1 -> ~4,17 MHz +
    demi-périodes cassette au même ratio ; ~3x effectif ; retour 1 MHz
    automatique en fin de bande. Trois correctifs issus de l'enquête
    (tb_cload bout-en-bout, traces VIA/RAM, désassemblage GetTapeByte
    $E6C9) :
    1. Stops supplémentaires (trame 14->18 bits, données seulement) : la
    fenêtre inter-octets ROM (traitement+IRQ T1) dépassait les 4 stops
    -> raccrochage 2 bits trop tard (41->D0, « Errors found »). La ROM
    brûle un front puis saute les courts ; un gap silencieux est refusé
    (le front terminal se fait manger). Course latente aussi à 1 MHz
    (t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
2026-08-12 US-DISK.3 : pistes .dsk depuis la SD, validé en simulation
    fat32 : seek par open_offset (saut de chaîne de clusters + offset fin)
    et open_abort MÉMORISÉ (abort_pend — l'impulsion tombant pendant une
    transaction SD, ex. frontière de cluster pile en fin de piste, était
    perdue : le flux continuait et l'open suivant était ignoré — bug
    débusqué par tb_dsk, piste 2 servait la piste 1).
    dsk_track.v : en-tête MFM_DISK (signature + géométrie), chargement de
    piste 6400 o en BRAM via seek fat32, scan RTL des marques A1A1A1FE/FB
    (miroir de mfm_extract_track), table des 17 secteurs, rechargement
    automatique quand le WD1793 change de piste (délais gelés pendant le
    transfert SD). gen_fat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
    [dsk_track.v]
2026-08-12 US-DISK : campagne pistes réelles (Citadelle 22 pistes au byte près) + correctifs
    - tb_dsk : scénario CITREAL — les 22 pistes RÉELLES de Citadelle.dsk
    (marques MFM, gaps serrés du mastering 1 face/22 pistes, entrelacement,
    fausses marques dans les données, 4 secteurs réellement absents) lues
    via les registres Microdisc et comparées octet à octet à l'extraction
    de référence (golden généré par l'algorithme mfm_extract_track).
    TOUT PASSE : le chemin de données est exonéré.
    - tb_dsk : correction d'une course du banc (lecture avant la fin du
    chargement de piste — attendre le front montant PUIS descendant de
    trk_loading) qui mimait une corruption.
    - gen_fat_test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
    [dsk_track.v]
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2026-08-13 Boot Sedoric : init RAM motif Oricutron + fix course seek/rechargement piste
    Deux causes racines du gel après la bannière (US-DISK.4) :
    - oric_ram.v : RAM toute à zéro = boot 'à chaud' pour le checksum $B932
    -> mini-loader 4 secteurs au lieu de SYSTEM.DOS complet -> vecteur IRQ
    sur $D0A5 vide -> tempête BRK. Init au motif Oricutron 128x00/128xFF.
    - dsk_track.v : un seek pendant un rechargement de piste étiquetait le
    buffer avec la nouvelle cible (piste 20 face 1 servie comme piste 13)
    -> READ FAULT. Cible capturée au début du chargement (load_tgt).
    Bancs : tb_dsk scénario 3 (non-régression course), tb_side1 (diagnostic),
    gen_sed_test.py embarque désormais les 2 faces (le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
    [dsk_track.v]
2026-08-13 US-DISK.4 validé sur carte : OSD ouvert/fermé + reset auto à l'insertion .dsk
    Sedoric boote jusqu'au menu, Citadelle.dsk fonctionne (les choix du menu
    étaient cassés par la course de piste corrigée au commit précédent).
    - OSD : BTN4 charge/insère ET ferme ; fermé, BTN3/BTN4 ne font que le
    rouvrir. Fini les chargements cassette accidentels pendant un boot
    disque (vol du bus SD -> READ FAULT, turbo x4 -> touches répétées).
    Pas de réouverture sur reset (pas de recouvrement du boot).
    - Insertion .dsk = reset auto : attente du front dsk_inserted puis ~5 ms
    de reset, la machine reboote sur l'EPROM Microdisc. Plus besoin de BTN1.
    - Backlog : US-SD-SPEED (SPI haute vitesse + se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
2026-08-13 PORT_EXTENSION : TXS0108E proscrit, plan 74LVC245 (DIR//OE) pour la LOCI
    Analyse bmarty : le TXS0108E (auto-sens pass-gates + one-shot, prévu pour
    I2C open-drain) entre en contention avec le 74LVC4245A push-pull de la
    LOCI et déraille avec la capacité des fils volants. Plan retenu : famille
    74LVC (5 V-tolérante alimentée en 3,3 V) — LVC245 données DIR=R/W,
    adresses/contrôles en sortie fixe (ou AHCT245 montant uniquement),
    entrées vers FPGA en LVC245, /RESET par BSS138.
    Complément : /OE=/IO ne suffit pas pour le transceiver données — la LOCI
    sert sa ROM menu via /ROMDIS+/MAP en $C000-$FFFF (lectures mémoire sur
    D0-D7) ; /OE à la masse (sûr) ou combinaison incluant /MAP.
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2026-08-13 Carte adaptateur LOCI rév. LVC : spécification électrique (hardware/loci_lvc)
    5x SN74LVCC3245APW (DIR//OE maîtrisés) au lieu des TXS0108E du bandeau
    phaseA ; U3 données piloté par XCVR_DIR//XCVR_OE (gp/gn[16]), sécurité
    par défaut isolé+écoute ; /RESET par BSS138 ; peigne 34 doigts et ordre
    de nappe hérités de phaseA. Brochage LVCC3245A à vérifier sur TI SCDS010
    avant génération du PCB.
2026-08-13 US-SD-SPEED + US-DISK.4 UX : validés sur carte, gravés en flash SPI
    Boot Sedoric rapide (SPI x16 + seek incrémental), OSD fermé à l'insertion,
    reset auto, Citadelle OK, cassette et Atmos pur sans régression.
    [loci_lvc.dsn, loci_lvc.kicad_pcb, loci_lvc_fr.dsn]
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2026-08-13 Réponse à la note liaison LOCI : gp/gn[16] figés, TXS purgé d'expansion_port, vigilance BOM berceau
    - 3.1 tranché : gp/gn[16] (ADC AIN5/AIN4) intentionnel — gp/gn[23] occupés
    par l'imprimante, broches ESP32 à préserver (modem actif), ADC jamais
    sélectionné. Figé et gravé.
    - 3.2 corrigé : expansion_port.v ne mentionne plus le TXS0108E qu'en proscrit.
    - Berceau : 2 transceivers ne suffisent pas (31 signaux, 4 directions -> 5
    puces + BSS138) ; réutiliser l'affectation U1..U5 de hardware/loci_lvc.
    - loci_lvc = variante B si berceau PCBA retenu.
2026-08-13 Modem ESP32 v0.3 : AT$SCAN (wificonf.bas) + ATDISKRD (loci-webdisk) + robustesse
    AT$SCAN au format attendu par wificonf.bas ; ATDISKRD au protocole exact
    de ~/loci-webdisk (+DISK:<len> framing, corps brut, range en query) ;
    garde globale anti-crash ; dispatch ATDISKRD avant ATD (le bug : la
    commande tombait dans la numérotation). Réinstallé et testé sur l'ESP32.
    PCB loci_lvc : correction des collisions C11/jack et C12/J_ULX.
    [loci_lvc.kicad_pcb]
2026-08-13 ACIA 6551 : FIFO RX 4 Ko (anti-overrun) + DCD/DSR présents — liaison Oric-modem validée carte
    Diagnostic sur carte (PEEK #31D = 28 : OK du modem reçu + OVRN) : l'ACIA
    n'avait qu'un octet de tampon face au modem 115200, une boucle BASIC lit
    ~1000x plus lentement -> presque tout débordait (wificonf/term muets).
    Équivalent du --serial-buffer 4096 de l'émulateur de référence : FIFO
    BRAM 4 Ko show-ahead derrière le registre RDR, OVRN seulement si pleine,
    purge au reset programmé. DCD/DSR câblés à 1 (réf. acia6551.c : true à
    l'init). tb_acia : rafale 64 octets lue lentement, ordre et complétude.
    Suite 20/20. Aussi : wificonf vise $0380 (LOCI) -> version ULX3S $031C
    préparée (li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
    [loci_lvc.dsn, loci_lvc.kicad_pcb, loci_lvc_fr.dsn]
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2026-08-15 loci_lvc : variante 6 couches - bus complet route a 90% (freerouting propre, 0 violation)
    Le 2 couches plafonne a ~12-17 signaux non routes (faisceau 5V trop dense).
    Le passage en 6 couches (4 couches signal + 2 plans GND internes) debloque :
    freerouting ferme tout sauf ~11 liaisons, PROPREMENT (0 violation DRC).
    - loci_lvc_6l2.kicad_pcb : board 6 couches, ~90% route, 25 liaisons a finir
    (11 signaux a pads recouverts + 14 masses a coudre).
    - convert_6layer.py / route_6l2.py : reproduction du board propre.
    - NOTE_6L.md : etat, reproduction, finition (a faire a la main dans KiCad).
    - scripts de completion auto (route_signals, fix_gnd2...) : NON fiables
    (introduisent des courts) - base seu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
    [loci_lvc_6l2.kicad_pcb]
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2026-08-15 loci_lvc : version SIMPLIFIEE (facon vraie LOCI) - tous signaux routes en 2 couches
    Constat : la vraie LOCI n'a qu'UN transceiver octal (+ petits buffers), pas 5.
    Les entrees des peripheriques Oric etant 5V-tolerantes, les sorties du FPGA
    (A0-A15, PHI2, R/W, /IO) pilotent le peigne EN DIRECT en 3,3V - sans transceiver.
    Il ne reste qu'a adapter : data (1x 74LVC4245A), entrees de controle
    (1x 74LVC245), /RESET (BSS138). -> 15 composants au lieu de 25.
    Resultat : freerouting route TOUS les signaux en 2 couches, 0 violation
    (vs 12-17 signaux bloques avec 5 transceivers). Reste 9 masses a coudre
    (finition triviale). gen_pcb_simple.py + route_simple.py + NOTE_SIMPLE.md.
    [loci_lvc_simple.kicad_pcb]
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2026-08-16 Modem ESP32 : ATI n'utilise plus wlan.config('ssid') (ValueError MicroPython 1.14 STA)
    WIFI VALIDÉ DE BOUT EN BOUT depuis l'Oric (WIFICONF : scan reseaux ->
    selection -> AT$SSID/AT$PASS -> ATC1 CONNECTE 'Alterop Legacy' -> AT&W
    sauve). Seul bug : ATI faisait wlan.config('ssid') -> ValueError (rattrapé
    par la garde globale). ATI affiche maintenant le SSID mémorisé + RSSI
    optionnel (try/except).
    [main.py]
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2026-08-16 Modem ESP32 : recv via poll (fin du NO CARRIER après CONNECT) + ATI corrigé
    - run loop : ne lit la socket que si POLLIN (net_poll) -> b'' = vraie
    fermeture. Avant : recv() non-bloquant renvoyait b'' 'pas de données'
    sur MicroPython, pris pour une fermeture -> NO CARRIER juste apres CONNECT.
    - ATI : SSID mémorisé + RSSI optionnel (plus de ValueError wlan.config).
    Firmware réinstallé (passthru). DIAGNOSTIC : port 80 OK (ATGET 200, ATDT
    telehack:80 reste connecté), port 23 RST immédiat -> le WiFi 'Alterop
    Legacy' bloque le telnet, pas le modem.
    [main.py]
2026-08-16 Modem ESP32 : sortie octets BRUTS (fin du plantage sur octet telnet 0xFF)
    VRAIE cause du 'CONNECT -> NO CARRIER' sur le port 23 (pas le reseau ni un
    blocage FAI — PC et ESP32 sont sur le meme LAN Bouygues) : MicroPython ne
    supporte QUE le codec UTF-8, donc data.decode('latin-1') LEVE UnicodeError
    sur un octet >=0x80 (telnet IAC 0xFF au 1er paquet) -> hangup. Le port 80
    marchait car les donnees HTTP sont ASCII (valides UTF-8). Correctif :
    wbytes() ecrit les octets via sys.stdout.buffer (boucle online + atget).
    Diagnostique par instrumentation (recv=3 b'\xff\xfb\x03' EXC UnicodeError).
    Validation : ATDT telehack.com:23 -> banniere TELEHACK complete recue.
    [main.py]
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2026-08-16 Modem ESP32 : fix parsing ATD<hôte> (le 'p' de pavi mangé par faux-match ATDP)
    VRAIE cause du NO CARRIER depuis l'Oric (le modem joignait pourtant pavi:6502
    en passthru) : TERMBBS envoie 'ATDpavi.3617.fr:6502' ; en majuscules
    'ATDPAVI...' matchait startswith('ATDP') (pulse dial Hayes) -> 4 car. retirés
    au lieu de 3 -> hôte 'avi.3617.fr' (p mangé) -> DNS échoue. Idem tout hôte
    commençant par t/p. Fix : après ATD, ne retirer le modificateur T/P QUE s'il
    précède '#' (dial TLS ATDT# de TERMBBS) ; sinon c'est le début de l'hôte.
    VALIDÉ avec les formats EXACTS de TERMBBS : ATDpavi.3617.fr:6502 ET
    ATDT#pavi.3617.fr:6992 -> CONNECT + banniere BBS ORIC.
    [main.py]
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2026-08-17 US-DISK.5 phase 4 : commande Write Sector WD1793 (ecriture disquette e2e)
    Commande 0xA0 : DRQ -> 256 octets -> sec_we vers dsk_track -> wr_commit ->
    attente wr_ok/wr_err (niveaux). Cablage top complet wd1793->microdisc->
    oric_atmos->dsk_track->fat32.wblk. Bug decalage 1 octet corrige (increment
    cur_offset deplace hors du pulse sec_we). tb_dsk_wr_e2e + tb_wd1793 maj.
    test-dsk-wr-e2e/test-wd PASSED ; boot/dsk/microdisc/dsk-write sans regression.
    US-DISK.5 (ecriture disquette) COMPLETE.
    [dsk_track.v, wd1793.v]
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

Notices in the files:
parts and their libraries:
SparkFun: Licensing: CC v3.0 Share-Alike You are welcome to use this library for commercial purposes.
